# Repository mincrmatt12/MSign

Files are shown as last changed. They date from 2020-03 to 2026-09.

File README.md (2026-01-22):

# MSign

Code + designs for an LED sign display board powered by an STM32 and ESP8266. Make sure you clone the submodules.

## Organization

- `board`: schematics and PCB layout
- `stm`: STM32 firmware (drives the display)
- `stmboot`: STM32 bootloader
- `esp`: ESP8266 firmware (grabs information from the internet)
- `espweb`: ESP8266 web-based configuration page source
- `cfgserver`: Server for shipping unattended config and software updates (without using the webui)
- `bmap`: Tools for generating graphics resources
- `caplog`: Tools for debugging
- `vendor`: Various dependencies in source form (everything not listed below)
- `sim`: Stubs/shims for running the `esp` and `stm` codebases under linux.

## Dependencies

- A recent `arm-none-eabi-gcc` installation (suitably modern to deal with C++20; GCC 14 is what's tested)
- A `xtensa-lx106-elf-gcc` that can deal with C++20; preferably version 13.2.0 (which was available at one point in debian)
  - A suitable newlib/libstdc++ archive is available in `Dockerfile.build`
- Python 3 and the packages in `requirements.txt`
  - If you aren't building the `espweb` directory you do not require the `cryptography` package listed
- OpenOCD (for flashing)
  - If you have PlatformIO installed we use its OpenOCD by default, so you may not need to install it system-wide.
- CMake (version 3.13 or later is recommended)
- `quilt`, to apply the patches in `vendor` for the ESP8266 SDK

and everything checked out in the `vendor` directory. The ESP8266 SDK also usually requests you have python (specifically _system_ python, whatever runs from `python`) installed with it's requirements (`vendor/ESP8266_RTOS_SDK/requirements.txt`)

A Docker file with these is provided as `Dockerfile.build`.

For building the `espweb` you also need:

- yarn
- node 

A Docker file with _these_ is also provided as `Dockerfile.webbuild`

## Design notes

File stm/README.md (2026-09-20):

# STM
The code will run on a nucleo-f207zg or the msign, which uses an stm32f205rgt

## HUB75

### Pinout on nucleo

| Pin | Mapped |
| ----- | --- |
| `R0`  | `PD0`  |
| `G0`  | `PD1`  |
| `B0`  | `PD2`  |
| `R1`  | `PD3`  |
| `G1`  | `PD4`  |
| `B1`  | `PD5`  |
| `A` | `PB0`  |
| `B` | `PB1`  |
| `C` | `PB2`  |
| `D` | `PB3`  |
| `CLK` | `PD6`  |
| `LAT` | `PB5`  |
| `OE`  | `PB6`  |

### Pinout on board

| Pin | Mapped |
| ----- | --- |
| `R0`  | `PC0`  |
| `G0`  | `PC1`  |
| `B0`  | `PC2`  |
| `R1`  | `PC3`  |
| `G1`  | `PC4`  |
| `B1`  | `PC5`  |
| `A` | `PB0`  |
| `B` | `PB1`  |
| `C` | `PB2`  |
| `D` | `PB3`  |
| `CLK` | `PD6`  |
| `LAT` | `PB5`  |
| `OE`  | `PB6`  |

Uses DMA to the GPIO to drive R0-B1 as well as the clock.
DMA is triggered off of TIM1 update event; the delay between different bits of color in PCM encoding goes off of TIM9.

## Serial Protocol

Serial communications run at 115200 baud with even parity, except where specified otherwise.

The protocol starts with a handshake, initiated from the STM32, and continues asynchronously.

The system is mostly based around the sharing and storage of various "slots" of data, which have variable length, which while being capped at 65k by technical restrictions
is limited to around 8k in practice.

### Command format

```
| 0xA6 | 0x00 | 0x11 | <payload> |
  |       |     |
  |       |     ------ command, see below
  |       ---- payload size
  --- direction byte, A6 for packets from the esp, A5 for packets from the STM
```

| Name | Byte |
| ---- | ---- |
| `HANDSHAKE_INIT` | `0x10` |
| `HANDSHAKE_RESP` | `0x11` |
| `HANDSHAKE_OK` | `0x12` |
| `HANDSHAKE_UOK` | `0x13` |
| `HANDSHAKE_CRASH` | `0x14` |
| `DATA_TEMP` | `0x20` |
| `DATA_FULFILL` | `0x21` |
| `DATA_RETRIEVE` | `0x22` |
| `DATA_REQUEST` | `0x23` |
| `DATA_SET_SIZE` | `0x24` |
| `DATA_STORE` | `0x25` |
| `ACK_DATA_TEMP` | `0x30` |
| `ACK_DATA_FULFILL` | `0x31` |
| `ACK_DATA_RETRIEVE` | `0x32` |
| `ACK_DATA_REQUEST` | `0x33` |
| `ACK_DATA_SET_SIZE` | `0x34` |
| `ACK_DATA_STORE` | `0x35` |
| `QUERY_TIME` | `0x40` |
| `RESET` | `0x50` |
| `PING` | `0x51` |
| `PONG` | `0x52` |
| `UPDATE_CMD` | `0x60` |
| `UPDATE_IMG_DATA` | `0x61` |
| `UPDATE_IMG_START` | `0x62` |
| `UPDATE_STATUS` | `0x63` |
| `CONSOLE_MSG` | `0x70` |
| `REFRESH_GRABBER` | `0x80` |
| `SLEEP_ENABLE` | `0x81` |
| `RECONNECT_WIFI` | `0x82` |
| `UI_GET_CALIBRATION` | `0x90` |
| `UI_SAVE_CALIBRATION` | `0x91` |

### Handshake

STM sends command `HANDSHAKE_INIT`, esp responds with `HANDSHAKE_RESP`, STM finishes with `HANDSHAKE_OK`. All handshake commands have payload size 0 and no payload.
The command `HANDSHAKE_UOK` is sent to indicate that the STM should enter update mode. The command `HANDSHAKE_CRASH` is sent from the ESP in place of `HANDSHAKE_RESP` or
`HANDSHAKE_UOK` if there is a pending crash report -- this status is cleared after a reset and the STM should not boot if it gets it.

### Slots

Each slot is represented as a theoretically unbounded, randomly-accessible and partitionable chunk of memory.

Each part of the slot's data can be stored on either the ESP or the STM when not in use. Data stored on a processor in this way is called _canonical_ data. The other processor refers
to this data as _remote_ data, using a placeholder to avoid duplicating it. Remote data may temporarily be converted to _ephemeral_ data, which is a temporary copy of _canonical_ data, almost
always by the STM for use on-screen.

An entire slot has a _temperature_, which relates to where a version of it should be made available:

| Temperature | Meaning |
| --- | --- |
| Cold | Not required for the display right now |
| Warm | Will be required soon for the display, should be sent. |
| Hot | Is being displayed right now. |

There is also a special temperature which is never transmitted, but which the ESP uses internally to represent data that should be Warm but has no space to fit on the STM.

Any updates to data that is at least level Warm should be immediately transferred to the STM, so long as there
is space for it. Additionally, if any part of the slot's data is stored _canonically_ on the STM and the slot
is made Warm or higher, all the remaining parts of the data still stored on the ESP should be flushed to the STM and marked remote, again, memory permitting.

The STM controls the temperature of data using the `DATA_TEMP` (data temperature) message:

```
| 0x090a | 0x01 |
  |        |
  |        ---- the temperature to update to, one of the Block::Temperature* constants
  ----- the slot ID to update (12 bits, stored as 16 bit with upper nybble 0)
```

The STM shall send this message whenever it wishes to change the temperature of a slot, and should send it repeatedly until it receives an identical message of type `ACK_DATA_TEMP` confirming the change
(although it's allowed to stop sending if it wants to). The ESP can also respond with the fake temperature "0xff" which indicates a non-acknowledgement, usually because it thinks there isn't 
enough space (or for if there's no data for that slot)

The ESP can also send a `DATA_TEMP` message to set a slot back to Cold should it determine there is not enough space for it to be updated immediately. The STM may challenge this declaration
by trying to change the slot back to Warm, but will probably get a nak. The ESP may decide to re-instate the Warm temperature for a slot later, but only if the STM has not otherwise changed
the temperature since.

#### Updating

The ESP uses the `DATA_FULFILL` message to signal that the STM should create an ephemeral part of the data at some offset and length.

```
| 0x090a | 0x0100 | 0x0500 | <data> |
  |        |        |        
  |        |        |        
  |        |        ---- total length of update
  |        --- offset to update at
  --- slot ID + framing info:

  0b0000  0x90a
    ||||    |
    ||\\    slot ID
    ||-- reserved
    |- end
    - start
```

The "fulfilling" of the data is in response to a "request", either implicitly from the temperature setting or explicitly from a "DATA_REQUEST" message.

#### Framing

This message (as well as `DATA_STORE`) is framed to allow for sending more than 249 bytes: the `start` bit is set for the first message corresponding to this update, the `end` bit is set for the last message, and the offset is always
the offset of this message.

This is enough to both know the size and starting offset of an update immediately, progressively update, and again know the size and starting offset of the entire update as well.

#### Acknowledgements

This message (as well as `DATA_STORE`) send a single acknowledgement to indicate successful/unsuccessful completion of the update as a whole. Note that an acknowledgement is not required if an `end` packet
is not sent.

This acknowledgement takes the form

```
| 0x090a | 0x0100 | 0x0120 | 0 |
  |           |      |       |
  |           |      |       -- result code
  |           |      -- length of update
  -- slot ID  -- start of update
```

The result code is one of these:

| Code | Usage |
| ---- | ----- |
| `0x00` | Completed OK |
| `0x01` | Not enough space to store -- try again soon to allow for potential cleanup |
| `0x02` | Not enough space to store -- cleanup failed, definitely no space |
| `0x10` | Illegal internal state |
| `0x11` | Parameters don't make sense / other NAK |
| `0xff` | Internal timeout somewhere |

#### Moving 

The ESP is allowed to store data canonically on the STM should it want, and it does this with the `DATA_STORE` message.
It has the same format and acknowledgement scheme as `DATA_FULFILL`, but semantically means to create a canonical part not an ephemeral one.

### Unmoving

If the ESP decides it no longer wants data canonically on the STM, it can send the `DATA_RETRIEVE` message. 

```
| 0x090a | 0x0100 | 0x0120 |
  |           |     |
  |           |     -- region size
  -- slot ID  -- region start 
```

If the data is present on the STM, it sends an acknowledgement that is identical. If the data is not present, a similar process to an invalid `DATA_CHANGE_SIZE` is used.
Once the acknowledgement is sent, the STM sends its own `DATA_STORE` message sequence, and the ESP responds accordingly. 

#### Size update

The ESP sends `DATA_CHANGE_SIZE` whenever the total size of a slot changes. The STM should handle new empty space as remote placeholders.

```
| 0x090a | 0x0aaa |
   |           |
   |           |
   -- slot ID  -- new slot size
```

This is acknowledged with a copy of the message, and it is illegal to not have this complete succesfully. If there isn't enough space to store
the placeholder, not responding is valid and the ESP will handle the timeout in some vaguely graceful manner.

#### Forgetting/requesting

The STM can request an explicit `DATA_FULFILL` from the ESP by sending a `DATA_REQUEST` message. The syntax for this message is:

```
| 0x090a | 0x000c | 0x0120 |
  |           |     |
  |           |     -- region size
  -- slot ID  -- region start
```

An identically-formatted message is sent as acknowledgement.

### Consoles

A console is a unidirectional stream of characters. There are three consoles on the MSign:

| ID | Usage |
| --- | ---|
| `0x01` | The debug console input; as accessed through the web interface for commands starting with `"stm"` |
| `0x02` | The debug console output; relayed back to the web interface, hooked to `stderr` |
| `0x10` | `printf` output; logs, hooked to `stdout` |

The protocol uses one message for these:

```
| 0x01 | <data> |
  |      |
  |		 - character data for the remainder of the message
  -------- the console ID
```

It can be sent from either device.

### Time sync

When the STM sends a `QUERY_TIME` message, the ESP should respond with the current time. The payload of the request is empty and the response is

```
| 0x00 | <time> |
  |      |
  |      ---- JS-style millisecond-referenced unix timestamp
  ---- status code
```

The time should be as close to as possible the time when the last byte of the header of the request was sent.
The status code can be one of

| Code | Meaning |
| ---- | --- |
| `0x00` | OK |
| `0x01` | Time is still being retrieved, try again in a bit |

### Refresh

The STM can ask the ESP to refresh data from a certain grabber (see the esp source) by sending the `REFRESH_GRABBER` with a single byte payload indicating which ID to refresh.

### Sleep mode

The MSign has a sort of pseudo sleep mode which can by enabled or disabled by either devices by sending the `SLEEP_ENABLE` message with a singly byte payload indicating whether
or not to enable/disable (`00` being disabled, anything else being enabled)

When in sleep mode, the following things occur:

- all log output is prevented from reaching the serial port (to avoid blinking the led)
- the screen is turned off
- update frequency is made much slower

### Reconnect

The STM can ask the ESP to reset its WiFi connection (e.g. to refresh DHCP leases after a router reboot) by sending a `RECONNECT_WIFI` message with no payload.

### ADC calibration

The ESP persists to the SD card the current calibration in a file. The calibration can be updated either manually on the SD card or by an interactive process on the STM whose results
are also persisted to the SD card.

The STM can request the current calibration with an empty `UI_GET_CALIBRATION` message. In response, the ESP sends a `UI_GET_CALIBRATION` of its own, formatted as

```
| 0x00 | 0x0000 | 0x0000 | 0x0000 | 0x0000 | 0x0000 | 0x0000 |
  |      |                                                 |
  |      ---------- calibration data as 6 16-bit words ----|
  --- response code                                        
```

with the calibration data missing if the error code is not `0`. The error code can be one of:

| Code | Meaning |
| ---- | --- |
| `0x00` | OK |
| `0x10` | No calibration data present |
| `0x11` | No calibration data present and auto-configuration is disabled (i.e. ignore joystick) |

The calibration data is made up of the following three values repeated twice, once for the x-axis and once for the y-axis:

- minimum reading
- maximum reading
- deadzone width (total delta from (max + min)/2 allowed)

The STM can upload new calibration using the `UI_SAVE_CALIBRATION` command, with a payload consisting of just the calibration data portion of the `UI_GET_CALIBRATION` response. Once the data is
written to the SD card, the ESP responds with an empty `UI_SAVE_CALIBRATION` message.

### Other commands

When either device sends the `RESET` command, both devices should reset. Usually sent by the ESP upon grabbing new configuration -- but the STM can also send it in rare cases.

When either device sends the `PING` command, the other MUST respond with the `PONG` command, UNLESS the handshake has not been completed.

The above three commands have no payload.

### Update commands

The update procedure is rather complicated due to the requirement to update two things.
The first step is the ESP receiving an update package. While it is downloading the package, it updates various status slots to inform. Once it has finished, it will send a `RESET` command to reset the device.
When the system reboots, the ESP shall respond with `HANDSHAKE_UOK` on successful handshaking. Once this occurs, the STM enter update mode. When this occurs, the baudrate is doubled until
the terminating `RESET`.

Once the update finishes for the STM, it must send an appropriate `UPDATE_STATUS` to the ESP. Once this occurs,
the ESP will update itself. When it finishes, the STM will hear a `UPDATE_CMD` to reset itself to normal mode. At this point, the system is updated.

#### Detailed flow

After the `RESET`, the ESP will send various `UPDATE_CMD`s, and then the image.

The `UPDATE_CMD` message looks like this:

```
| 0xFF |
 |
 ---- cmd ID
```

where `cmd ID` is:

| ID | Meaning |
| :--- | :--- |
| `0x10` | Cancel update mode / reset to normal mode |
| `0x11` | Prepare to recieve image
| `0x30` | Image read error |
| `0x31` | Image checksum error |
| `0x32` | Invalid state error |
| `0x40` | Update completed successfully |
| `0x50` | ESP wrote sector (see below) |
| `0x51` | ESP copying sector (see below) |

Once message `0x11` is sent, the STM should get ready to recieve the `UPDATE_IMG_START`. This message contains:

The STM can respond with `UPDATE_STATUS` messages, with the same format.

| ID | Meaning |
| :--- | --- |
| `0x10` | Entered update mode |
| `0x12` | Ready for image |
| `0x13` | Ready for chunk |
| `0x20` | Beginning copy process |
| `0x21` | Copy process completed |
| `0x30` | Resend last chunk, csum error |
| `0x40` | Checksum error on entire thing, abort procedure |
| `0x41` | Unexpected protocol error, abort |

Note there are no errors for copy process as if it fails the code won't run. If the ESP doesn't get anything for a few minutes it can report failure and ask for manual reflashing.

```
| 0xCC CC | 0xSS SS SS SS | 0xCNCN |
  |          |               |
  |          |               ------ chunk count, little endian 16bits
  |          ---- size of new image, bytes, little endian 32bits
  ---- checksum, little endian 16bits, CRC16
```

Then, the STM can send `UPDATE_STATUS` commands to get the chunks.

Once it sends the `0x13` message, the ESP responds with a chunk like this:

```
| 0xCC 0xCC | <data for rest of message>
  |            |
  |            -- chunk data (size = msgsize - 2) extra bytes are padded with zeros
  ---- CRC-16 checksum for this chunk
```

After each chunk, the STM can respond with an error or a new message.
If the stm deduces it has received all chunks, it sends the finished message and updates itself.
After completion of this process, it sends the status corresponding to update completed.
The ESP will then begin writing the image to itself in preparation for copying, and will send out "ESP wrote sector" messages
as it does so.
The STM then waits for the ESP to send a cmd corresponding to completed.
It then resets.

## Serial

### Pinout on nucleo

USART6.

| Pin  | Mapped |
| ---- | --- |
| `TX` | `PG14`  |
| `RX` | `PG9`  |

### Pinout on board

USART2.

| Pin  | Mapped |
| ---- | --- |
| `TX` | `PA2`  |
| `RX` | `PA3`  |

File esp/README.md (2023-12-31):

# ESP8266

## Pinouts

Debug tx is mapped to `GPIO2`.

TX/RX are on `GPIO13`/`GPIO15`.

SD is wired

| PIN | Mapped |
| --- | --- |
| `MISO` | `GPIO12` |
| `MOSI` | `GPIO4` |
| `SCK` | `GPIO14` |
| `CS`  | `GPIO5` |

(configurable via menuconfig)

## SD Card

The SD card contains the following files:

```
|
+- config.json
+- ca
| |
| -- <sha512 dn hash>
| -- <sha512 dn hash>
+-?model.bin
+-?model1.bin
+-?adc.bin
+- cache
|  |
|  +- ... various directories
+- web
| |
| +- page.html
| +- page.js
| +- page.css
| +- vendor.js
| +-?page.html.gz
| +-?page.js.gz
| +-?page.css.gz
| +-?vendor.js.gz
| +-?etag
--*upd
  |
  +- state
  +- esp.bin
  +- stm.bin
  +- webui.ar
  +- certs.bin
  +- chck.sum
```

Files marked with a `?` are optional, and will either be generated by the system or are not required.

Files marked with a `*` are only present during an update.

Files marked with a `!` are internal only.

### Simple files

- `config.json` contains the configuration for the sign. A reference of keys/values can be found in the various `.cfg.h` files within the main source tree.
- `model.bin` and `model1.bin` are optional 3D models, the default is a baked in M^2 text. The format is simply a 32bit integer of the number of triangles followed by tightly packed floats for each triangle (`xyz*3, rgb`)
- `adc.bin` contains the current calibration for the joystick. If not calibrated, the joystick is ignored (and a warning is shown unless
disabled in the config).

### Web files

The `html` file is served whenever a request is made that _doesn't_ contain a valid API URI.
The other files are served whenever a request matching their name (optionally containing a cache-busting
hash, in which case cache headers are set to cache indefinitely). 
The `etag` file is generated automatically to help with caching and should be deleted after changing the web assets.

### Update files

The files in the `upd` folder relate to the ongoing system update. In general, these should not be touched. To update the webui / certificate bundle it's easier
to manipulate their folders directly; to install new firmware from the SD card see the utilities in the `espweb/` folder.

The `bin` files contain the entire firmware image for the two systems, stored as flat binary files.

State is a single byte indicating the update state. `chck.sum` contains two 16 bit checksums for the
firmware files.

The `webui.ar` file is a normal `.ar` archive containing the new website files. It is written by the webui itself
for an over-the-air update -- updating the files manually in `web/` and deleting `web/etag` is usually faster for a manual
update.

The `certs.bin` file is a custom archive type containing a new block of certificates to install from an over-the-air update. Old certificates
are not removed -- to revoke a certificate the folder must be manually cleaned up.

## TLS files

All the files in the `ca` directory are trusted certificates. The filename is the
subject DN encoded in X.500 form and hashed with SHA512 (stored as hex) and is just
the DER-encoded X.509 certificate.

## Cache files

Files in the `cache` directory are used internally by various grabbers (in general, each grabber
automatically manages its own subfolder). The folder can be safely deleted.

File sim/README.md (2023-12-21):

# sim

Simulates the entire sign, using mostly the same codebase.

## Building

Requirements:

- A recent version of CMake

## Running

The system communicates with named pipes for emulating the UART.

Create two with

```
$ mkfifo stoe
$ mkfifo etos
```

then point the new `stmsim` and `espsim` binaries at them:

```
$ # terminal 1
$ ./stmsim <etos 2>stoe

----

$ # terminal 2
$ ./espsim <stoe >etos
```

You can also use more magic if you want to record the messages, possibly to be looked at with `caplog`, or combined with the logging utilities below:

```
$ # terminal 1
$ ./stmsim <etos 2>stoe 2> >(logtime.py stoelog.txt)

----

$ # terminal 2
$ ./espsim <stoe >etos > >(logtime.py etoslog.txt)
```

(`>(something)` becomes a file descriptor, `> >(something)` redirects that normally)

Alternatively, make two more named pipes and pass them into `caplog`'s `realtime` mode.

You also need to setup a TAP interface to get the ESP network working.

```
# add a bridge that our machine is on: this will forward packets
# to/from the virtual esp
# if you have a vm system setup with a virbr0 interface, you can skip all the way to the tap0 setup and just use it instead

$ sudo ip link add br0 type bridge
$ sudo ip addr add <some ip unused, e.g. 192.168.122.1/24> dev br0
$ sudo ip link set br0 up

# setup nat

$ echo 1 > /proc/sys/net/ipv4/ip_forward
$ sudo iptables -t nat -A POSTROUTING -o <your wifi/ethernet port> -j MASQUERADE
$ sudo iptables -A FORWARD -i br0 -j ACCEPT
$ sudo iptables -A FORWARD -o br0 -d <your subnet, e.g 192.168.122.0/24> -m conntrack --ctstate RELATED,ESTABLISHED -j ACCEPT
$ sudo ip route add <subnet for the bridge, e.g. 192.168.122.0/24> dev br0 proto kernel scope link src <ip of bridge, e.g. 192.168.122.1>

# setup the tap

$ sudo ip tuntap add dev tap0 mode tap user `whoami`
$ sudo ip link set tap0 master br0
$ sudo ip link set address 02:12:34:56:78:ab dev tap0
$ sudo ip link set tap0 up

# set config for espsim

$ export PRECONFIGURED_TAPIF=tap0
$ export SIMESP_IP <some ip on the subnet of the bridge, e.g 192.168.122.2>
$ export SIMESP_NETMASK <netmask of the bridge, e.g. 255.255.255.0>
$ export SIMESP_GATEWAY <ip of the bridge, e.g. 192.168.122.1>
```

The esp sim gets its SD card contents from the file `sdcard.bin` in the working directory, which should be a raw image of an SD card. You can create one with `fdisk` and `mkfs.vfat` and modify it
by loop mounting it; or by grabbing an actual SD card in use and taking a `dd`-style image of it.

## Structure

The `src` folder contains files to be mixed with the actual sources, any files here have precedence over those elsewhere, allowing for "overriding" of the original sources with mocked-up versions.
The two binaries communicate over standard file streams.

`espsim` sends data to `stmsim` over `stdout` and receives over `stdin`, sending debug data to `stderr`. To allow for terminal coloring, `stmsim` sends over `stderr`, but still receives on `stdin`.

The only file the fake ESP currently reads is the `config.txt`, placed in the working directory and with exactly identical contents to what it would be on the real sign.

## Logging

There are two programs provided here, `logtime.py` and `mergelog.py`, which create a logfile with extra bytes for the time and merge two of those logs into a normal log respectively.

## Extras

The `utils/` folder contains a few utilities which are compiled along with the simulator, which can be used for experimenting with some of the libraries available on both systems.

### `jdump`

`jdump` reads JSON from standard input and outputs a trace of how the `json::JSONParser` class will interpret it.

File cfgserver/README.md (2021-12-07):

# cfgserver

Implements a Vaguely Secure™ protocol for sending configuration over the network.

It exposes a set of HTTPS endpoints which implement a simple authentication scheme and update delivery mechanism.

It also now supports telemetry logging; the ESP can optionally include a header with prometheus-style key/value pairs, which
are exposed at `/a/metrics`.

## Authentication

To authenticate, the ESP must form a valid bearer token. The first step to generating a token is to obtain a _challenge_ from the server, by
performing `GET /challenge`. This will return a blob of text, which is opaque to the ESP (but on the server is a signed message containing
some random nonce and a timestamp). The ESP then signs this message with a shared HMAC key and appends the result (in hex) to the blob. This final string
is used as a bearer token.

For example:

```
GET /challenge HTTP/1.1
...

fahdvu234hauc.fjah3
```

```
GET /whatever HTTP/1.1
Authorization: Bearer fahdvu234hauc.fjah3;22be1f7c
```

Separately, the server stores an administrator user/password/2fa token which can be sent to `POST /login` as

```
{
   "user": "username",
   "password": "password",
   "token": "232148"
}
```

which will set a session cookie that will substitute for valid authentication (this is so that the normal webui can be hosted at the root of the server)

Thirdly, the server can be asked to generate static bearer tokens for use in CI.

These all have different privilege levels:

- The ESP is allowed to download but not change config
- Static tokens are allowed to change but not read config
- The administrator is allowed to do both.

## Update checking

There are two things `cfgserver` can send to the ESP, config updates or system updates. Both of these have an associated "version" identifier. For configuration, the
version is an arbitrary integer. Although it is an integer, a "newer" version does not need to have a larger version, rather the system only checks for a different version.

The version for system upgrades is the version ESP-IDF places into the firmware, which is obtained with `git describe --tags --always --dirty`.

The current version being served can be read from `/version` without authentication:

```
GET /version HTTP/1.1
...

HTTP/1.1 200 OK

{"firm": "v3.1-579-gffe802", "cfg": 4152}
```

If a value is not present, the corresponding file has not been uploaded.

## Downloading updates

The current config can be downloaded from `/conf.json` with valid authentication.

The current firmware is downloadable from `/stm.bin` and `/esp.bin`, again with valid authentication. 

## Uploading updates

Config can be pushed by `POST`-ing to `/conf.json` and firmware can be sent by `POST`-ing to `/updatefirm` with form-encoded files `stm.bin` and `esp.bin`.

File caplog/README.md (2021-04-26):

# `caplog`

Various tools to dissect capture logs of the communication between the STM and ESP.

## `dissect`

Takes in either a CSV from the Saleae software or a raw `bin` file containing a dump of all bytes transferred, and converts them to a visually
interpretable format.

`caplog/dissect.py [logicexport,simlog] <path to in file>`
(you can also use any prefix of the first argument)

## `regiondump.py`

GDB script that adds a command `dump_bheap` which takes an expression to a raw `bheap::Arena`'s region and a filename and writes out
a summary of all the blocks in the heap.

```
(gdb) source caplog/regiondump.py
(gdb) dump_bheap servicer.arena.region dump_file.txt
```

This also adds another command, `dump_raw_bheap` which outputs a json file (or appends to an existing json file) with an easier
to parse representation of the heap, suitable for visualization with `dumpviewer.html`.

## `dumpviewer.html`

Tiny single page web thing that can read a heap trace and visualize it.

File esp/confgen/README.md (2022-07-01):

# confgen
 
`confgen` is the system we use to generate the config.cpp parser. It essentially generates implementations for header files ending with `.cfg.h` based
on control comments.

There are a couple of ways that `confgen` can be instructed to provide data to you:

- directly, in a ram variable (`holds`)
- indirectly, through a function that receives config (`receives`)
- lazily, by generating a function that reads the data (`loads`)

## Comment syntax

All `confgen` comments start

```
//!cfg: <something>
```

The first word of a confgen is the desired type, either `holds`, `receives`, or `loads`. The next block, after a space, is the _path specification_, similar in
style to `jq`.

Specifically, the path syntax is

```ebnf

path: ("." atom)+

atom: CNAME -> path_element
	| CNAME "[" array_index "]" -> named_array_element
	| "[" array_index "]" -> anon_array_element
	| variable -> wildcard_element
	| CNAME "!size" -> special_size_element

variable: "$" CNAME

?array_index: INT
		   | variable

```

For example:

```
.ssid  ->  { "ssid": <something> }

.weather.apikey -> {"weather": {"apikey": <something>}}

.ttc.entries[0].name -> {"ttc": {"entries": [{"name": 0}]}}

.ttc.entries[$n].$var -> all subentries (passed to function as a size_t and const char *)

.ttc.entries!size -> length of entries array
```

Variables have three uses:
- For arrays, to denote which axes of the target variable correspond to axes of json arrays. These use names `$i - $k`, and if omitted will be assumed to refer to the
  last element of the path
- For `receives`, to specify wildcards which correspond to function arguments (by name).
- For `loads`, to specify dynamic matches. They are the exact inverse of the behaviour for `receives`; calling a generated loader with some arguments
will load the value that a similar receiver would get for those same arguments.

`holds` annotates a variable and specifies that the config data at the given path should be placed in it. The variable should be declared
`extern`, as the config generator will create the actual storage.

`receives` annotates a function that will be called with config data (and possible values of variables). The values are passed to whichever parameter
is named `value` -- it does not need to be in any specific location.

`loads` annotates a function that will have its implementation generated such that it loads some entry from the config, as denoted by the path. Its arguments
can be used as variables in said path to choose different things to load at runtime.

### Additional tags

Other things can be added as comma separated tags after the main declaration, such as explicit datatypes or defaults.

```
, default <some value>
, max $i = 0
, result $hi
```

- `default` sets a default for a value. Defaults are only allowed for loaders/global variables and should only be basic constants (not a complex expression). Arrays
can be initialized by space separating the desired values. The `$i - $k` variables can be used to refer to array indices.
- `max` sets a maximum for a given variable in wildcard/array filling mode. By default, it's inferred from the dimensions of the targeted variable,
but for `receives` this is impossible and so can be assigned manually
- `result` specifies a named argument to a loader which should be a `bool&` and which is set to true/false depending on if the load succeeded.

### Annotating types

Structure members can be annotated, in which case the entire structure becomes eligible for being used as a target variable. Note that currently you cannot have a function
receive an entire object (although a loader _can_ generate one). Structure function members can also be used as receive targets.

The paths used are relative to wherever the structure is used, for example

```c++
struct Thing {
   //!cfg: .a
   int a = 4;
   //!cfg: .bs
   int bs[3]{};
}

//!cfg: .some.path
extern Thing thingy;
```

which will load from `.some.path.a` and `.some.path.bs[0-2]`.

Structures are default-constructed, however you can also provide explicit defaults for fields too. These will currently _not_ be applied
in loaders, though.

Types are only searched for annotations in `.cfg.h` files, not anything included from one. To search an additional file, use the `//!cfg: include <file>` notation
which works relative to the current file (like a quoted `#include`).

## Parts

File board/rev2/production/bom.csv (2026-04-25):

Designator | Footprint | Quantity | Value | LCSC Part #
C1, C12, C15, C21, C24, C25, C3, C34, C35, C38, C44, C45, C46, C47, C48, C49, C5, C50, C51, C52, C53, C54, C55, C56, C57, C58, C59, C60, C61, C62, C63, C64, C65, C66, C71 | 0402 | 35 | 100nF | C307331
C10, C16, C2, C37, C72 | 1206 | 5 | 10uF | C13585
C11, C23, C68, C74 | 0603 | 4 | 1uF | C15849
C13 | 0603 | 1 | 2.2nF | C1604
C14 | 0603 | 1 | 8.2nF | C1322360
C17 | CP_Radial_D8.0mm_P3.50mm | 1 | 220uF | C106697
C18 | CP_Radial_D8.0mm_P3.50mm | 1 | 150uF | C106696
C19, C20, C22, C36, C39, C43 | 1206 | 6 | 4.7uF | C29823
C26, C27, C28, C29, C30, C31, C32, C33, C7, C73, C8, C9 | 1206 | 12 | 47uF | C96123
C4 | 0603 | 1 | 33nF | C21117
C40, C42 | 0402 | 2 | 15pF | C1548
C41, C67 | 0603 | 2 | 2.2uF | C23630
C6 | 0402 | 1 | 10pF | C32949
C69, C70 | 0603 | 2 | 330pF | C1664
JCONT1 | PinHeader_1x09_P2.54mm_Horizontal | 1 | Conn_01x09_Pin
JDBG1, JDBG2 | PinHeader_1x03_P2.54mm_Vertical | 2 | Conn_01x03
JLED1, JLED2 | IDC-Header_2x08_P2.54mm_Vertical | 2 | Conn_02x08_Counter_Clockwise
JPWR1 | CONN-TH_4P-P9.50_WJHB9500M-9.5-04P-13-00A | 1 | Screw_Terminal_01x02 | C255007
JSD1 | microSD_XUNPU_TF-115-BCP9 | 1 | Micro_SD_Card_Det1 | C720505
JUSB1, JUSB2 | USB_C_Receptacle_HRO_TYPE-C-31-M-12 | 2 | USB_C_Receptacle_USB2.0_14P | C165948
L1 | L_Chilisin_BMRF00101040 | 1 | 6.8uH | C7502775
L2 | L_Cenker_CKST1707 | 1 | 1uH | C5292052
Q1 | DFN-8_L4.9-W6.0-P1.27-LS6.1-BL | 1 | WSD40120DN56G | C507088
R1 | 0603 | 1 | 49.9k | C23184
R10 | 0603 | 1 | 2.2 | C22939
R12, R13, R18, R19 | 0402 | 4 | 22 | C25092
R14 | 0402 | 1 | 10 | C25077
R15, R17, R24, R25, R26, R27, R28, R29, R30, R32, R33, R34, R35, R36, R37, R38, R52 | 0402 | 17 | 1k | C11702
R16, R22, R23, R49, R50, R51 | 0402 | 6 | 33 | C25105
R2, R20, R21, R3, R8 | 0402 | 5 | 10k | C25744
R4 | 1206 | 1 | 100 | C17901
R40, R41, R42, R43, R47 | 0805 | 5 | 10k | C17414
R44, R45 | 0603 | 2 | 5.1k | C23186
R46 | 0603 | 1 | 20k | C4184
R48 | 0402 | 1 | 200 | C25087
R5 | 0805 | 1 | 1.2k | C17379
R6 | 0805 | 1 | 470k | C17709
R7 | 0805 | 1 | 150k | C17470
R9 | 0402 | 1 | 3.3k | C25890
SW1, SW2, SW3, SW5 | SW-SMD_MS-22D17AG2.5 | 4 | MS-22D28-G020 | C20611671
SW4 | SW_SPST_TS-1088-xR020 | 1 | TS-1088-AR02016 | C720477
TP1, TP2, TP3, TP4, TP5, TP6, TP7 | TestPoint_Pad_D1.0mm | 7 | TestPoint
U1 | WQFN-20-1EP_3x3mm_P0.4mm_EP1.7x1.7mm_ThermalVias | 1 | TPD6S300A | C2876380
U10 | TSSOP-16_4.4x5mm_P0.65mm | 1 | 74VHC161 | C7421276
U11, U13 | TSOP-28_L11.8-W8.0-P0.55-LS13.4-L | 2 | IS61LV256AL | C412837
U12, U14 | TSSOP-16_4.4x5mm_P0.65mm | 2 | 74AHCT595 | C460504
U15, U16 | TSSOP-20_4.4x6.5mm_P0.65mm | 2 | 74HCT245 | C5980
U17, U18 | UQFN-10_1.4x1.8mm_P0.4mm | 2 | TS3USB30ERSWR | C73880
U19 | SOT-223-3_TabPin2 | 1 | LD1117AG-33-AA3-A-R | C71121
U2 | SOT-583-8 | 1 | TPS62933 | C3200405
U3 | VQFN-10_L2.0-W2.0-P0.45-TL | 1 | TPS259472A | C3662789
U4 | TSOT-23-6 | 1 | LM5050-1 | C473393
U5 | POWERPAK_MLP34-57_VIS | 1 | SiC451 | C1852144
U6 | QFN-48-1EP_7x7mm_P0.5mm_EP5.6x5.6mm | 1 | STM32G071CBUx | C529343
U7 | ESP32-C6-WROOM-1 | 1 | ESP32-C6-WROOM-1 | C5366877
U8 | SOT-23-5 | 1 | TLV74311 | C485147
U9 | RP2350-QFN-80-1EP_10x10_P0.4mm_EP3.4x3.4mm_ThermalVias | 1 | RP2354B | C39843328
Y1 | Crystal_SMD_3225-4Pin_3.2x2.5mm | 1 | ABM8-272-T3 | C20625731

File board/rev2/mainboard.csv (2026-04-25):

Id | Designator | Footprint | Quantity | Designation | Supplier and ref
1 | C1, C3, C5, C12, C15, C21, C24, C25, C34, C35, C38, C44, C45, C46, C47, C48, C49, C50, C51, C52, C53, C54, C55, C56, C57, C58, C59, C60, C61, C62, C63, C64, C65, C66, C71 | C_0402_1005Metric | 35 | 100nF
2 | C2, C10, C16, C37, C72 | C_1210_3225Metric | 5 | 10uF
3 | C4 | C_0603_1608Metric | 1 | 33nF
4 | C6 | C_0402_1005Metric | 1 | 10pF
5 | C7, C8, C9, C26, C27, C28, C29, C30, C31, C32, C33, C73 | C_1206_3216Metric | 12 | 47uF
6 | C11, C23, C68, C74 | C_0603_1608Metric | 4 | 1uF
7 | C13 | C_0603_1608Metric | 1 | 2.2nF
8 | C14 | C_0603_1608Metric | 1 | 8.2nF
9 | C17 | CP_Radial_D8.0mm_P3.50mm | 1 | 220uF
10 | C18 | CP_Radial_D8.0mm_P3.50mm | 1 | 150uF
11 | C19, C20, C22, C36, C39, C43 | C_1206_3216Metric | 6 | 4.7uF
12 | C40, C42 | C_0402_1005Metric | 2 | 15pF
13 | C41, C67 | C_0603_1608Metric | 2 | 2.2uF
14 | C69, C70 | C_0603_1608Metric | 2 | 330pF
15 | JCONT1 | PinHeader_1x09_P2.54mm_Horizontal | 1 | Conn_01x09_Pin
16 | JDBG1, JDBG2 | PinHeader_1x03_P2.54mm_Vertical | 2 | Conn_01x03
17 | JLED1, JLED2 | IDC-Header_2x08_P2.54mm_Vertical | 2 | Conn_02x08_Counter_Clockwise
18 | JPWR1 | CONN-TH_4P-P9.50_WJHB9500M-9.5-04P-13-00A | 1 | Screw_Terminal_01x02
19 | JSD1 | microSD_XUNPU_TF-115-BCP9 | 1 | Micro_SD_Card_Det1
20 | JUSB1, JUSB2 | USB_C_Receptacle_HRO_TYPE-C-31-M-12 | 2 | USB_C_Receptacle_USB2.0_14P
21 | L1 | L_Chilisin_BMRF00101040 | 1 | 6.8uH
22 | L2 | L_Cenker_CKST1707 | 1 | 1uH
23 | Q1 | DFN-8_L4.9-W6.0-P1.27-LS6.1-BL | 1 | WSD40120DN56G
24 | R1 | R_0603_1608Metric | 1 | 49.9k
25 | R2, R3, R8, R20, R21 | R_0402_1005Metric | 5 | 10k
26 | R4 | R_1206_3216Metric | 1 | 100
27 | R5 | R_0805_2012Metric | 1 | 1.2k
28 | R6 | R_0805_2012Metric | 1 | 470k
29 | R7 | R_0805_2012Metric | 1 | 150k
30 | R9 | R_0402_1005Metric | 1 | 3.3k
31 | R10 | R_0603_1608Metric | 1 | 2.2
32 | R12, R13, R18, R19 | R_0402_1005Metric | 4 | 22
33 | R14 | R_0402_1005Metric | 1 | 10
34 | R15, R17, R24, R25, R26, R27, R28, R29, R30, R32, R33, R34, R35, R36, R37, R38, R52 | R_0402_1005Metric | 17 | 1k
35 | R16, R22, R23, R49, R50, R51 | R_0402_1005Metric | 6 | 33
36 | R40, R41, R42, R43, R47 | R_0805_2012Metric | 5 | 10k
37 | R44, R45 | R_0603_1608Metric | 2 | 5.1k
38 | R46 | R_0603_1608Metric | 1 | 20k
39 | R48 | R_0402_1005Metric | 1 | 200
40 | SW1, SW2, SW3, SW5 | SW-SMD_MS-22D28-G020 | 4 | MS-22D28-G020
41 | SW4 | SW_SPST_TS-1088-xR020 | 1 | TS-1088-AR02016
42 | U1 | WQFN-20-1EP_3x3mm_P0.4mm_EP1.7x1.7mm_ThermalVias | 1 | TPD6S300A
43 | U2 | SOT-583-8 | 1 | TPS62933
44 | U3 | VQFN-10_L2.0-W2.0-P0.45-TL | 1 | TPS259472A
45 | U4 | TSOT-23-6 | 1 | LM5050-1
46 | U5 | POWERPAK_MLP34-57_VIS | 1 | SiC451
47 | U6 | QFN-48-1EP_7x7mm_P0.5mm_EP5.6x5.6mm | 1 | STM32G071CBUx
48 | U7 | ESP32-C6-WROOM-1 | 1 | ESP32-C6-WROOM-1
49 | U8 | SOT-23-5 | 1 | TLV74311
50 | U9 | RP2350-QFN-80-1EP_10x10_P0.4mm_EP3.4x3.4mm_ThermalVias | 1 | RP2354B
51 | U10 | TSSOP-16_4.4x5mm_P0.65mm | 1 | 74VHC161
52 | U11, U13 | TSOP-28_L11.8-W8.0-P0.55-LS13.4-L | 2 | IS61LV256AL
53 | U12, U14 | TSSOP-16_4.4x5mm_P0.65mm | 2 | 74AHCT595
54 | U15, U16 | TSSOP-20_4.4x6.5mm_P0.65mm | 2 | 74HCT245
55 | U17, U18 | UQFN-10_1.4x1.8mm_P0.4mm | 2 | TS3USB30ERSWR
56 | U19 | SOT-223-3_TabPin2 | 1 | LD1117AG-33-AA3-A-R
57 | Y1 | Crystal_SMD_3225-4Pin_3.2x2.5mm | 1 | ABM8-272-T3

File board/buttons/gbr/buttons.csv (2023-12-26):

Value | Reference(s) | Footprint | LCSC Part
47nF | C1, C2 | Capacitor_SMD:C_0603_1608Metric | C1622
12k | R1, R2, R3, R4 | Resistor_SMD:R_0402_1005Metric | C25752

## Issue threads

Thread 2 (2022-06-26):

ESP config memory leak

mincrmatt12, 2022-06-26:
Due to an oversight in the config parser generator, string members inside of objects are not freed when reloading the configuration. This causes memory leaks when new configurations are downloaded from the webui/cfgserver.

Current solution will be to replace all global unmanaged `char *` with a destructable `config::string_t`. This should also let the sim store default/non-default tracking flags without imposing memory penalties on the actual device to emulate the current behaviour of checking which region of memory the pointer is in.

Closed 2022-07-01.

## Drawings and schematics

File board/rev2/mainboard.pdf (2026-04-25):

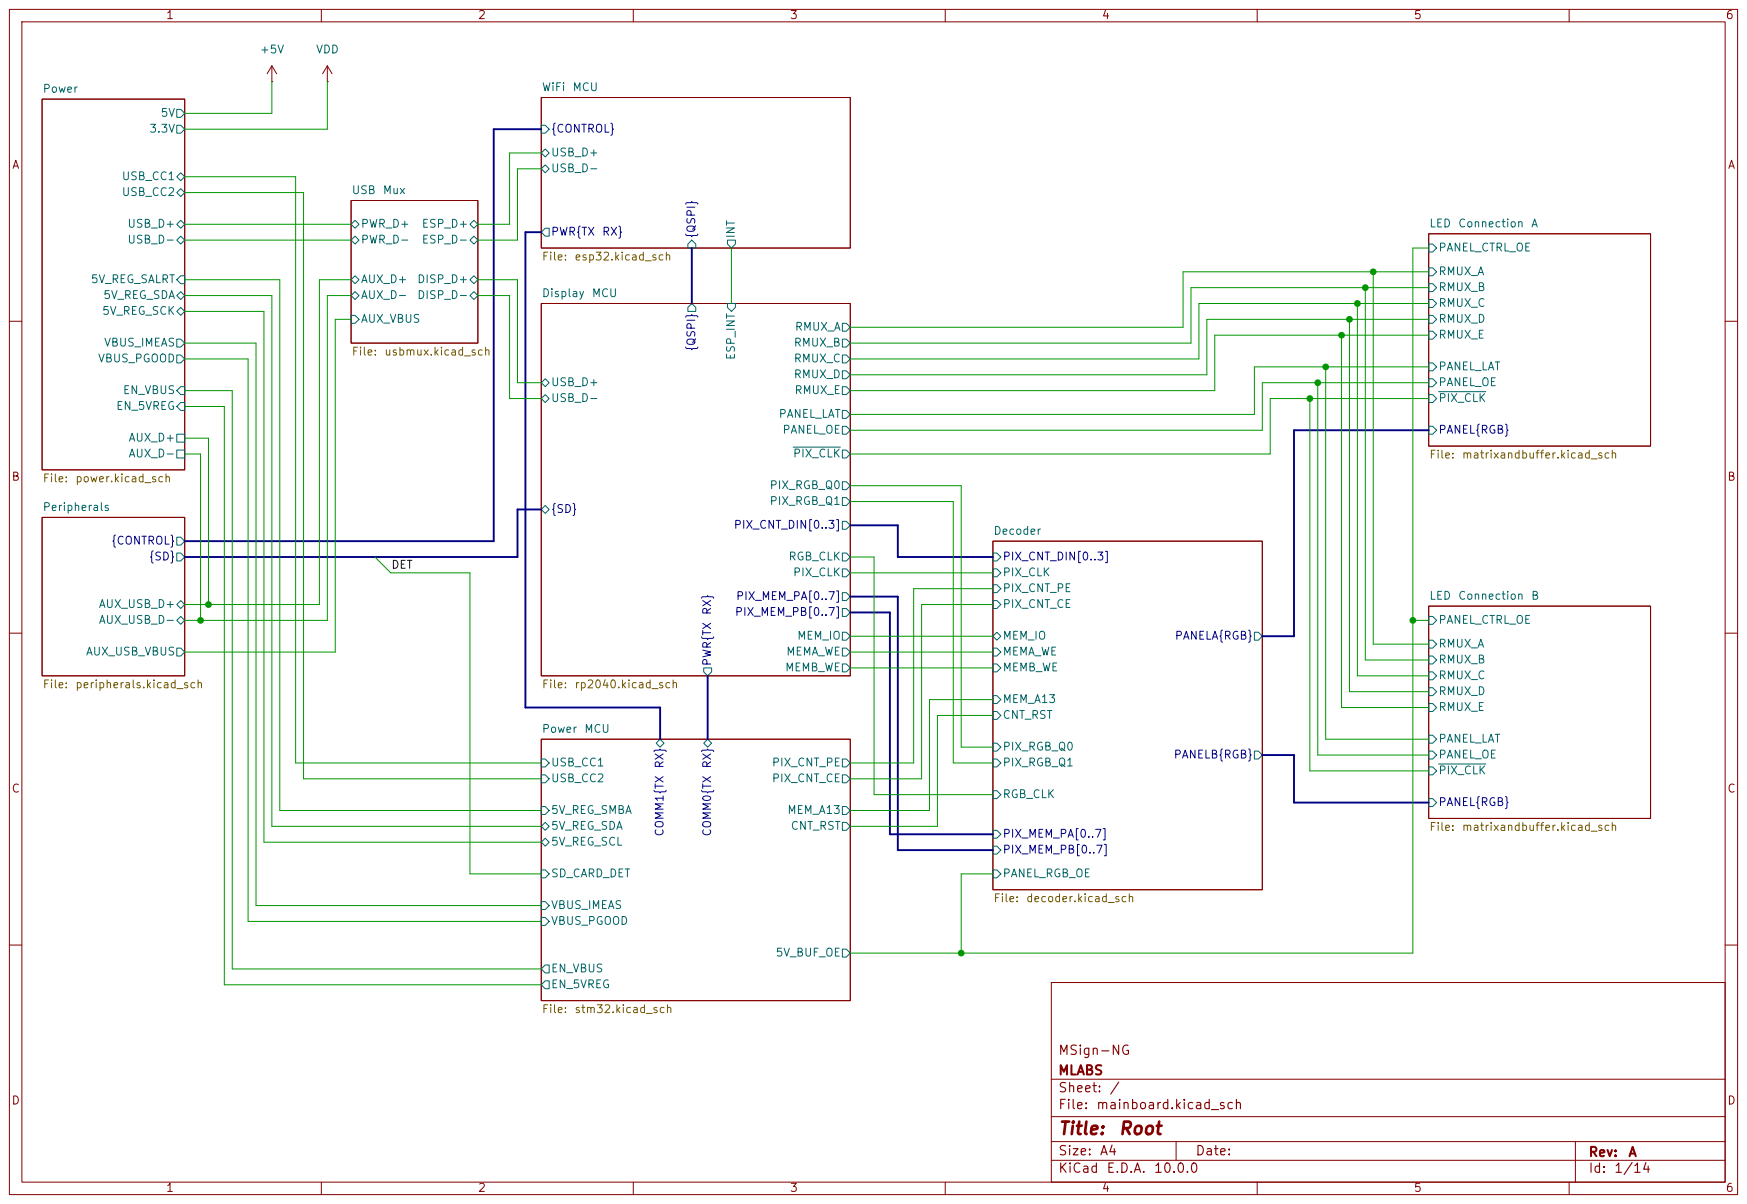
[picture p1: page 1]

PIX_CNT_PE COMM0{TX RX} COMM1{TX RX} SD_CARD_DET Power MCU

Sheet: / MLABS MSign-NG

Size: A4 | Rev: A
KiCad E.D.A. 10.0.0 | Id: 1/14

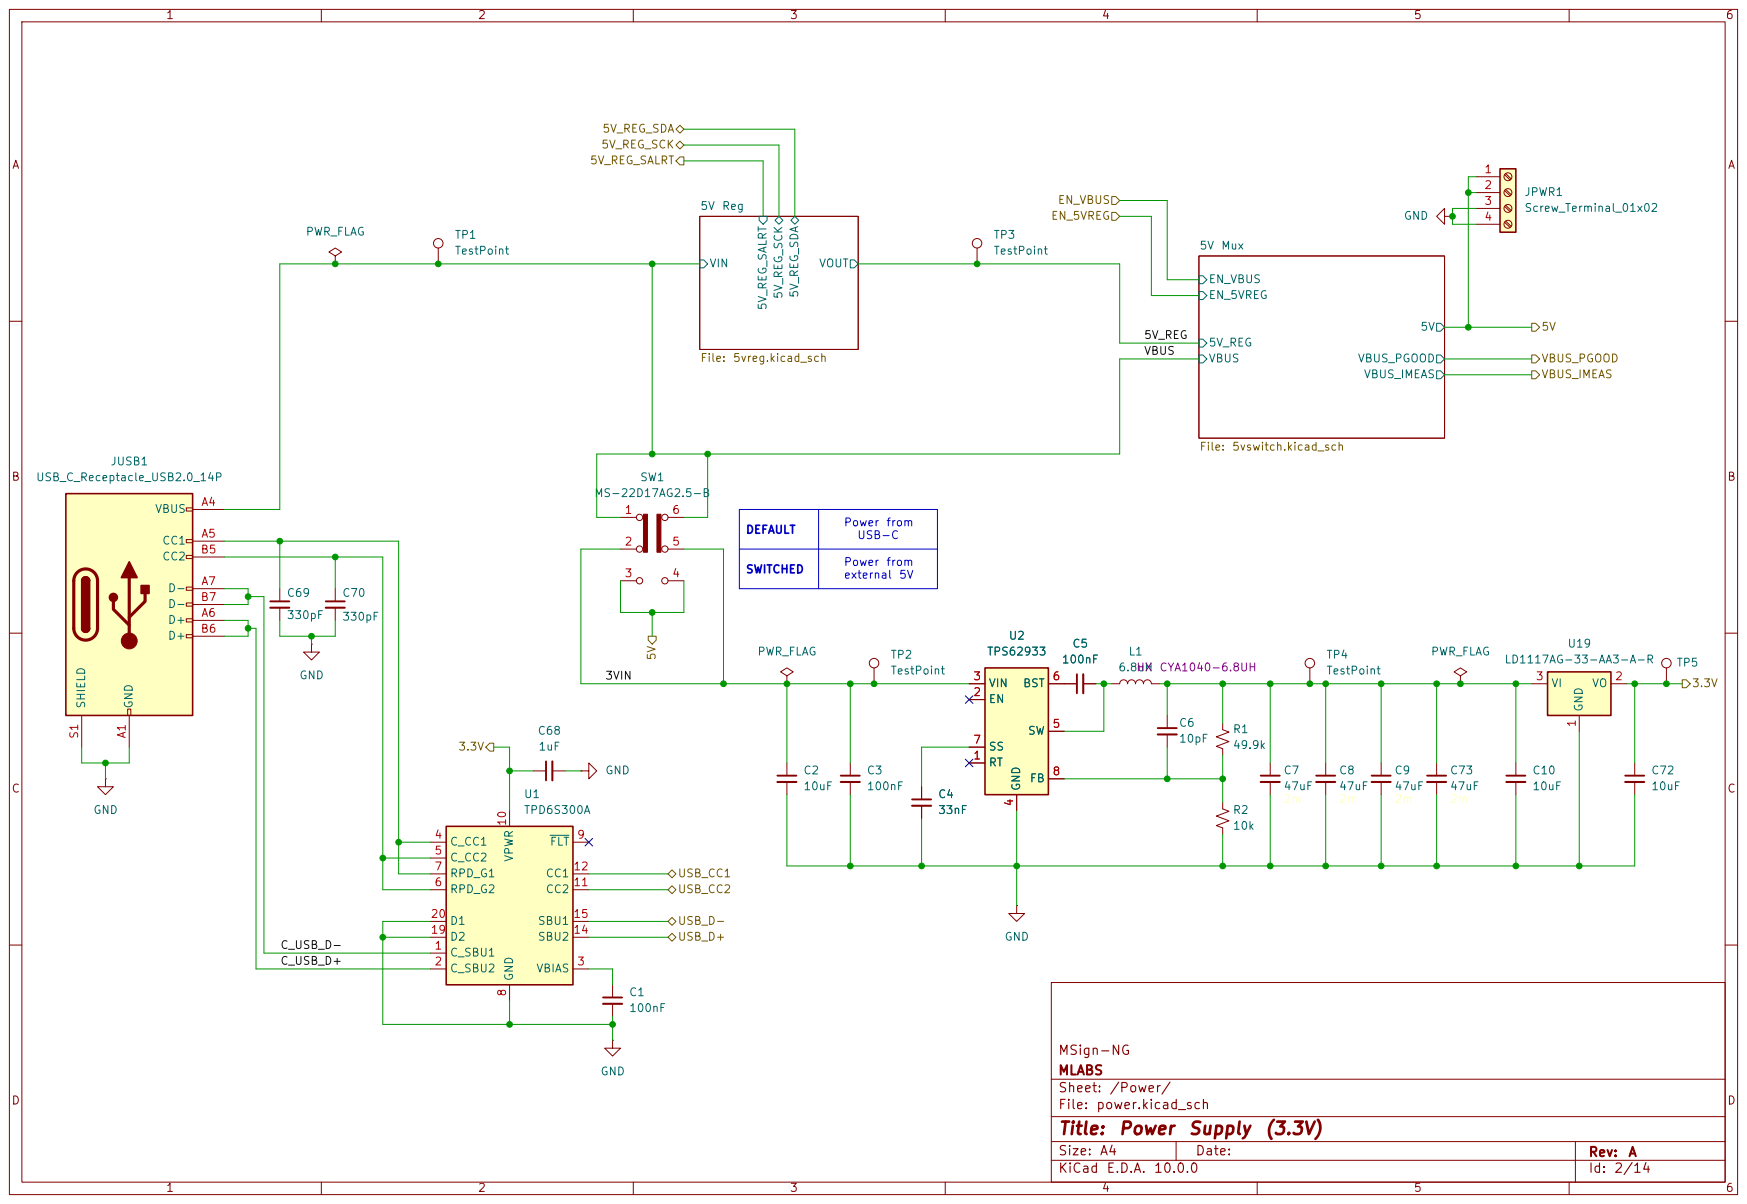
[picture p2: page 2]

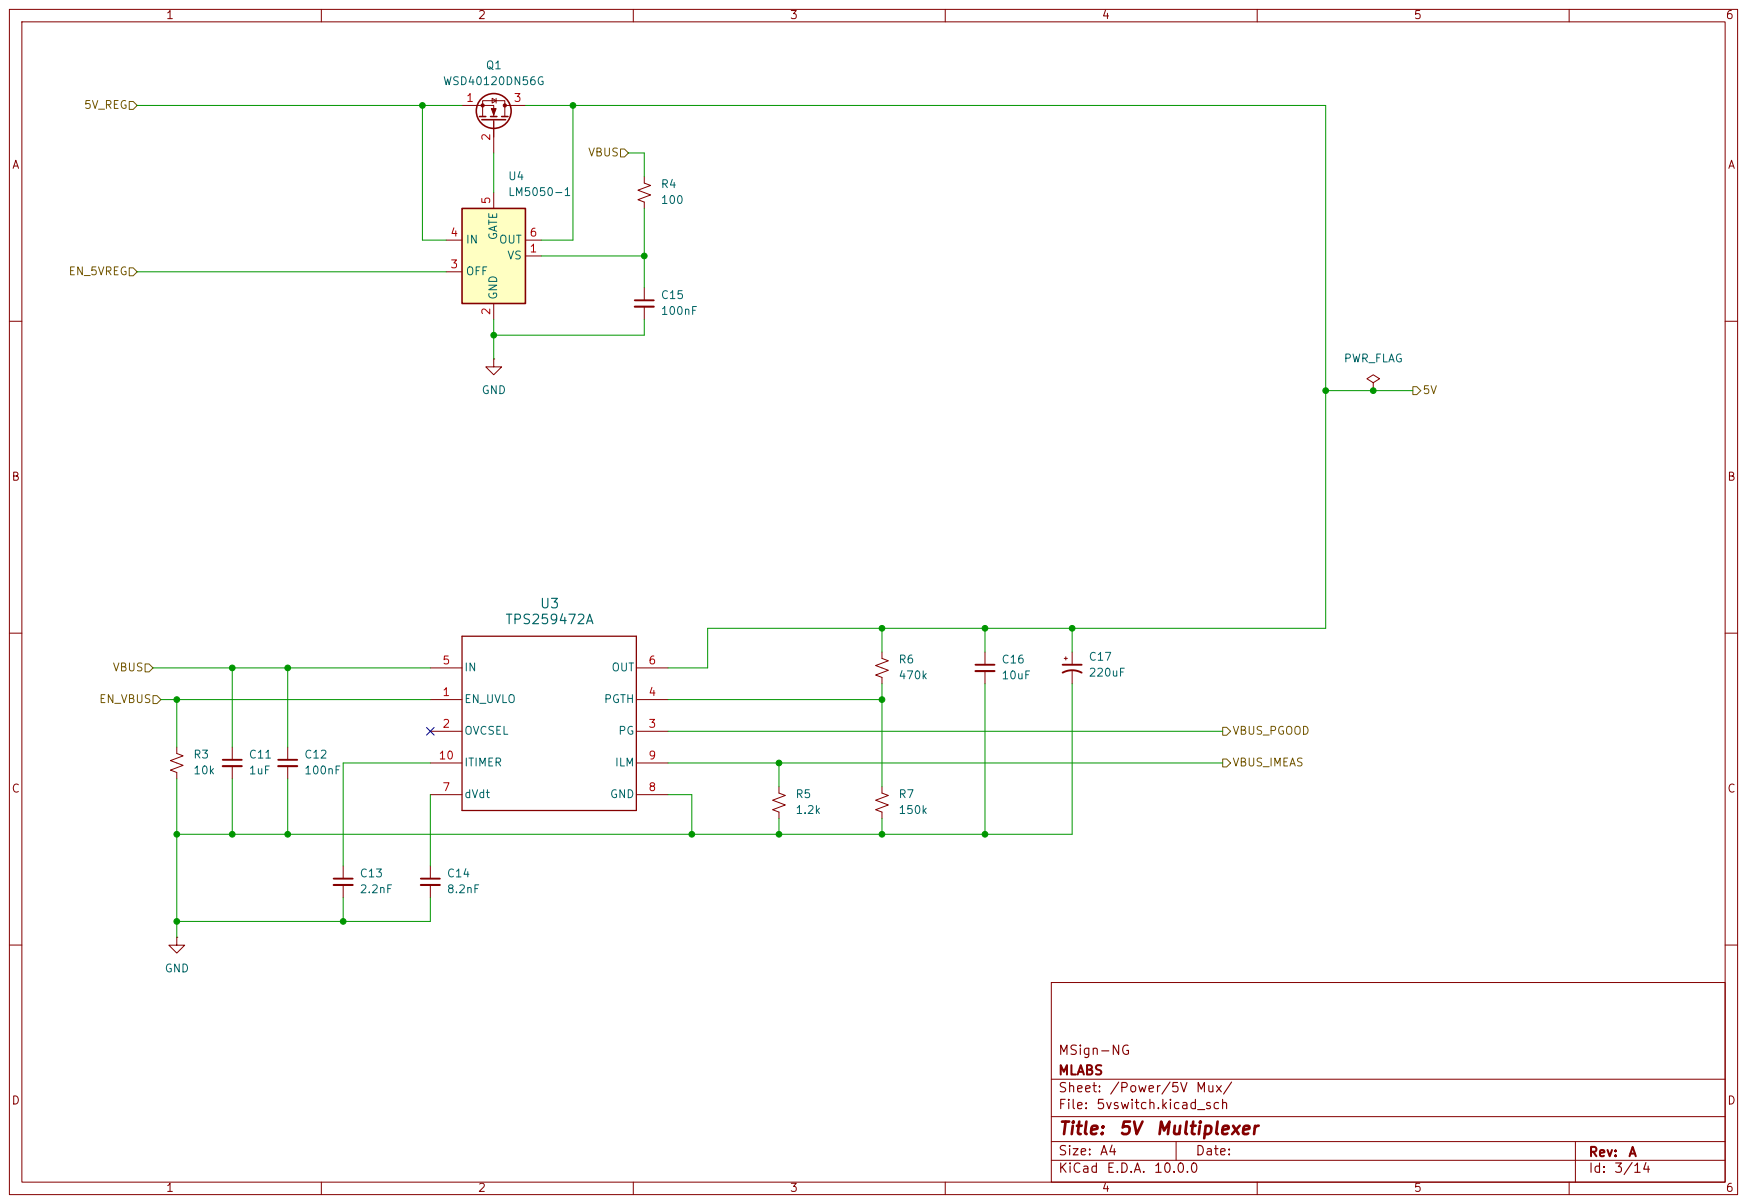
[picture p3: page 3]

Sheet: /Power/5V Mux/ MLABS MSign-NG

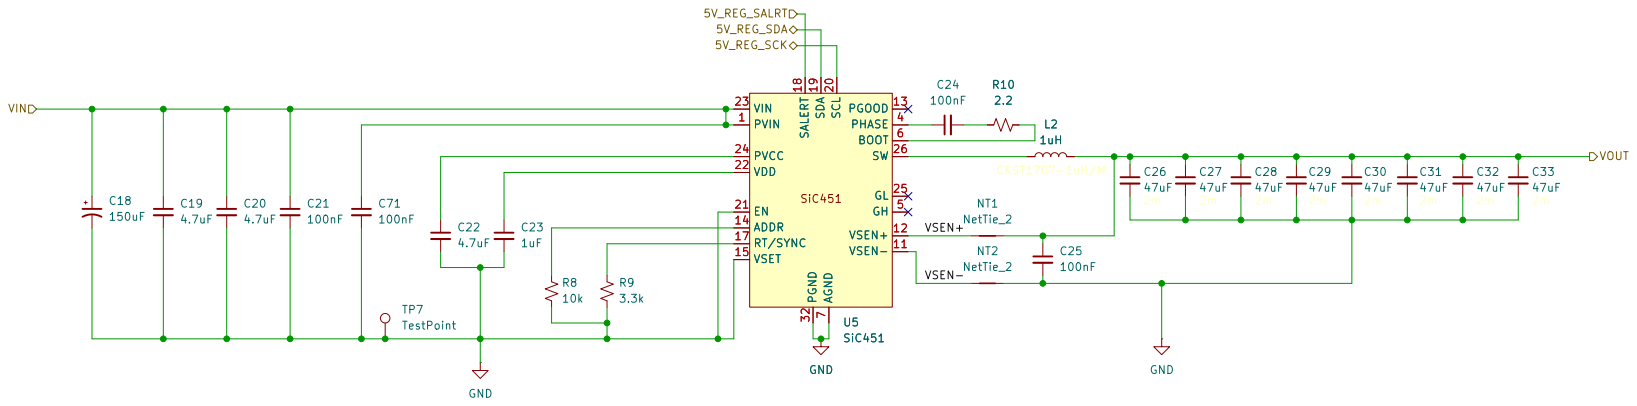
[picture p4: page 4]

Sheet: /Power/5V Reg/ MLABS MSign-NG

File: 5vreg.kicad_sch
Title: USB PD 5V Regulator

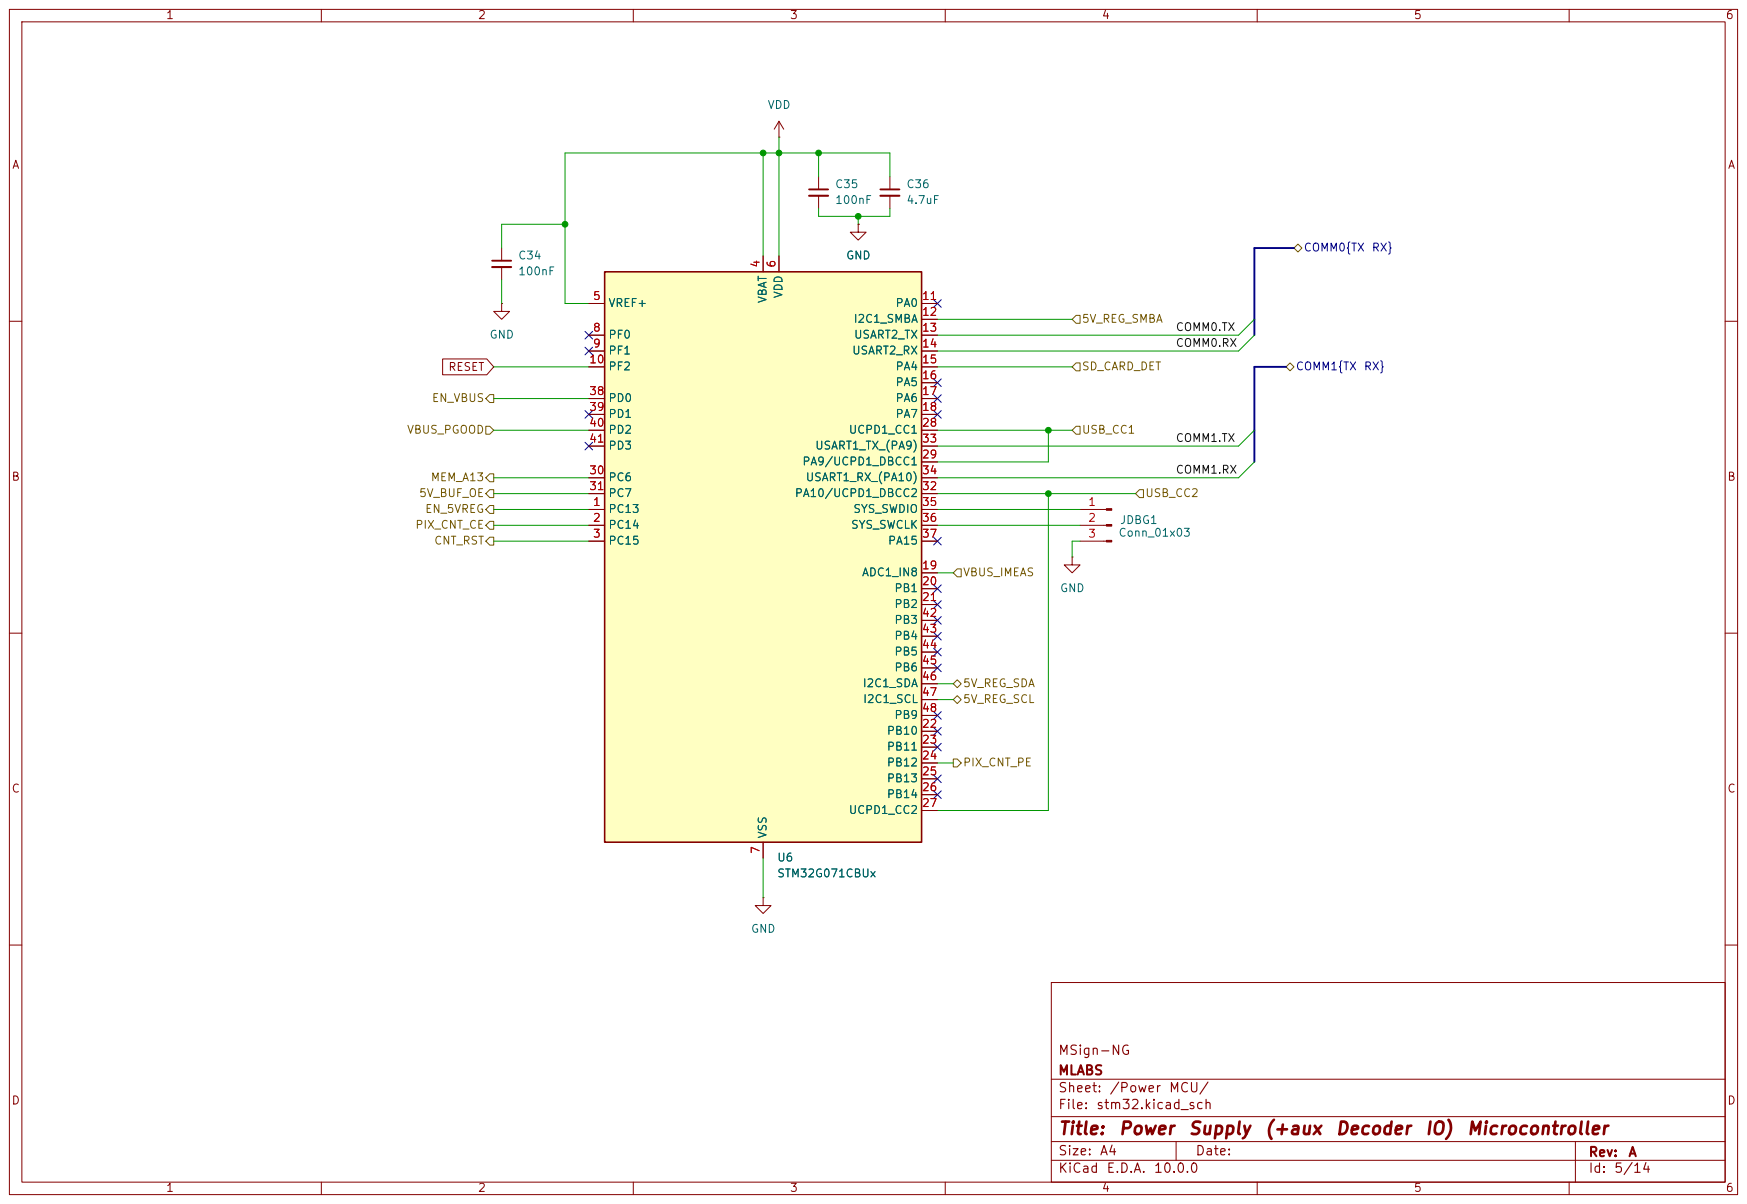
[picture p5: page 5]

Sheet: /Power MCU/ MLABS MSign-NG

File: stm32.kicad_sch
Title: Power Supply (+aux Decoder IO) Microcontroller

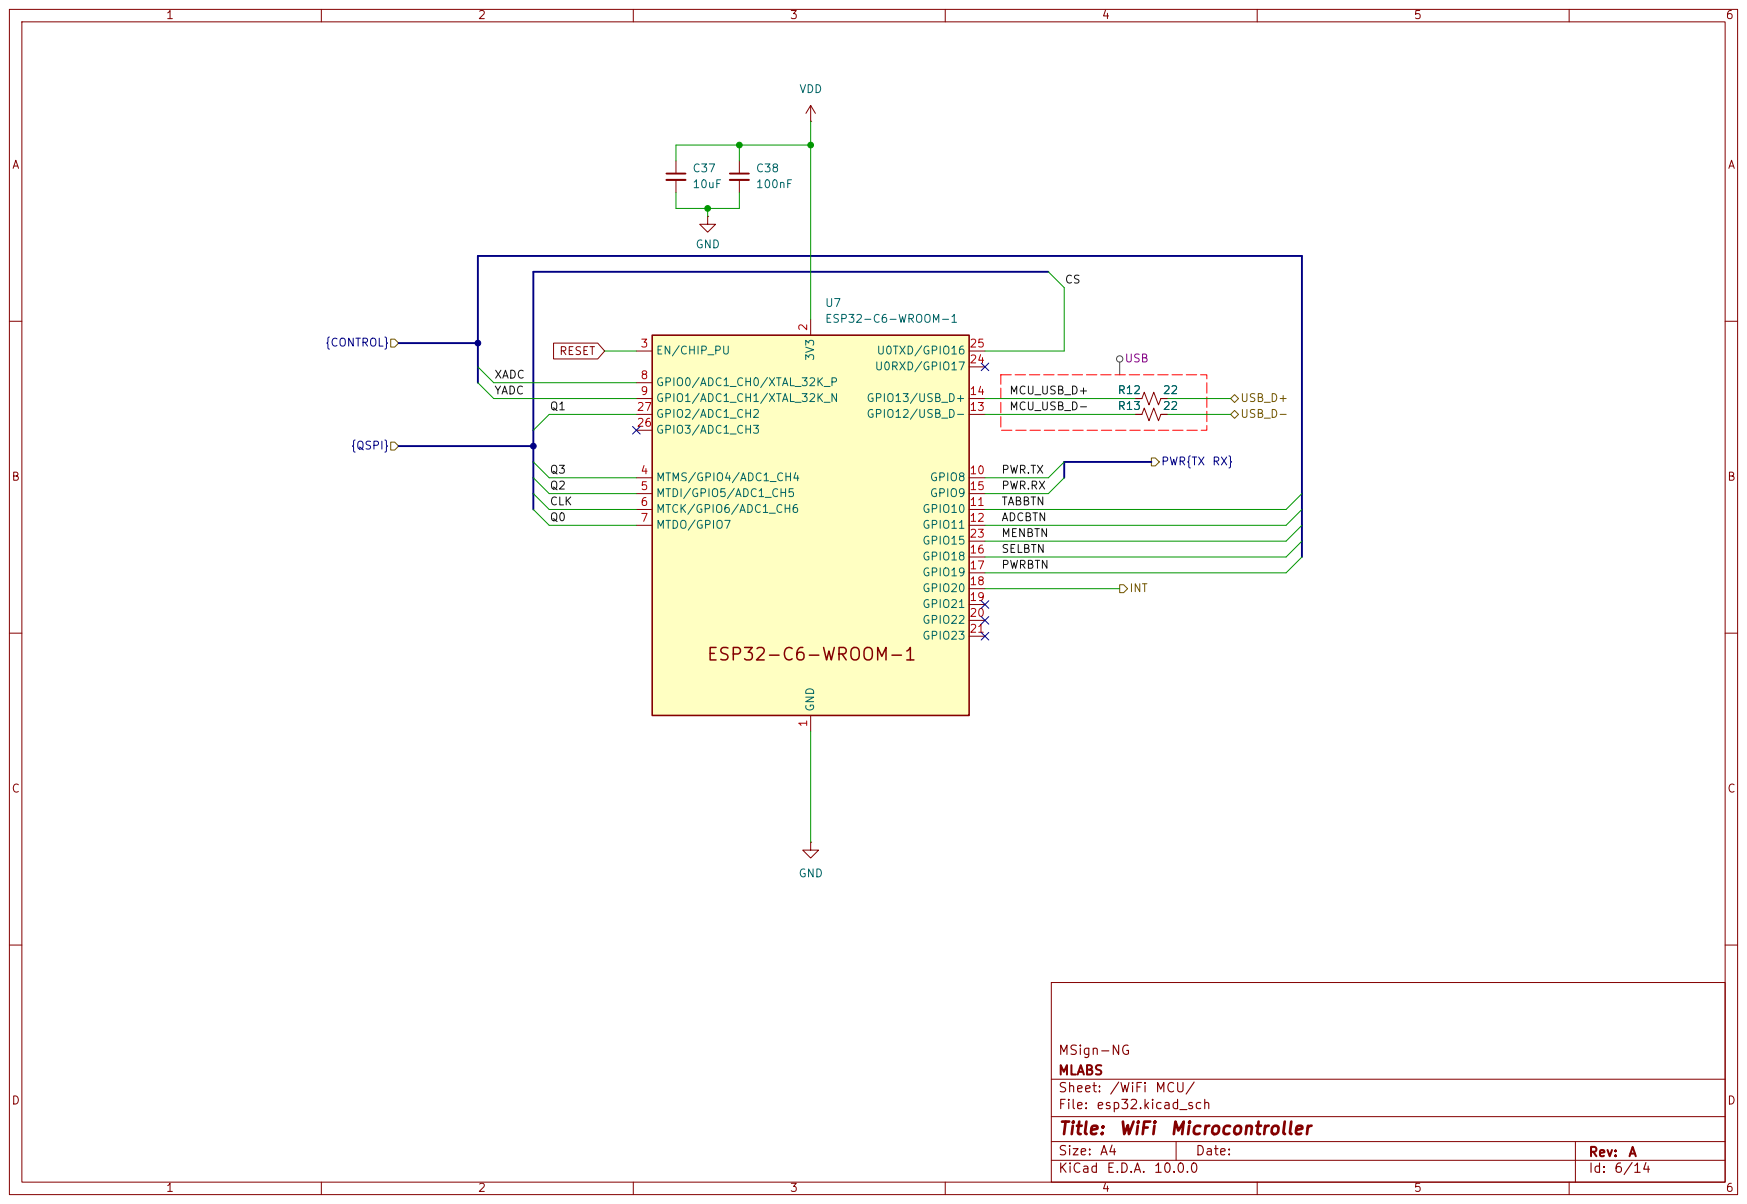
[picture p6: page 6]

Sheet: /WiFi MCU/ MLABS MSign-NG

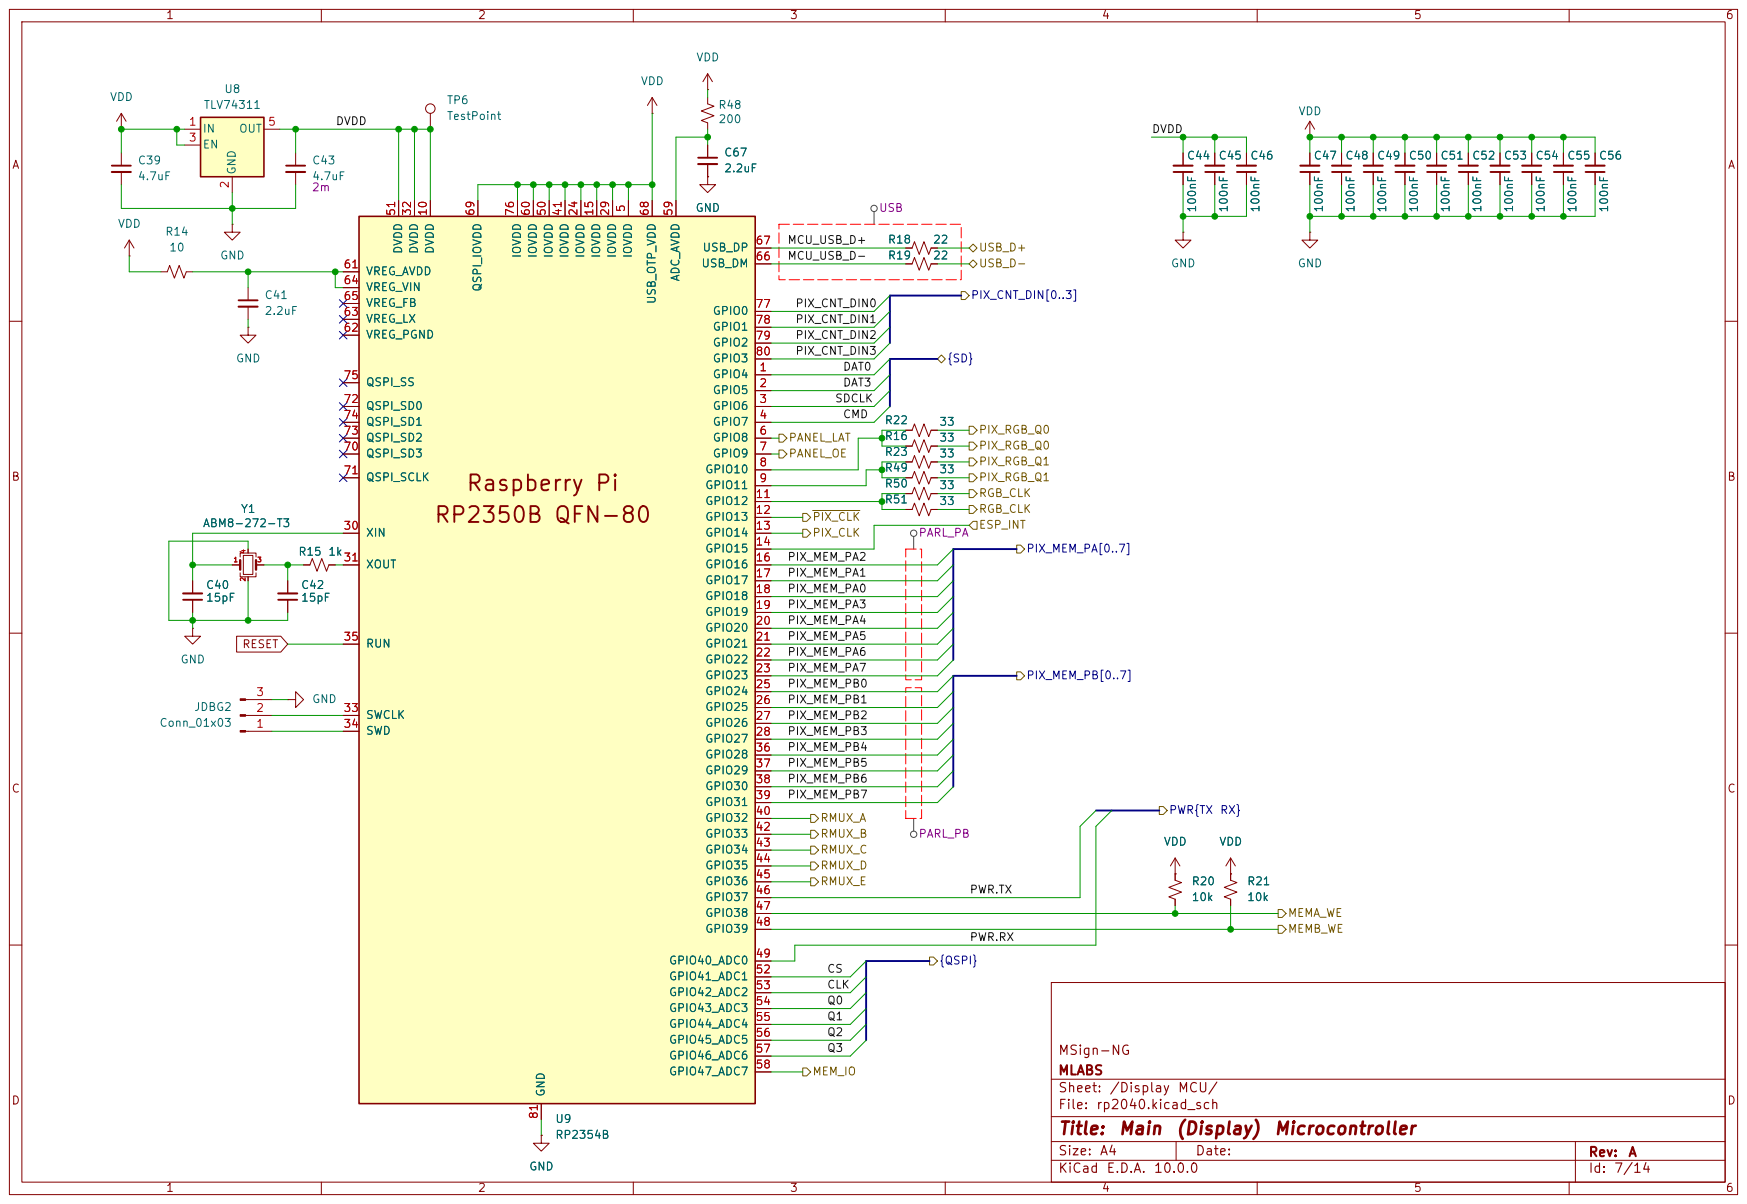
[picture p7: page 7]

5 GPIO8 6 GPIO9 7 GPIO10 8 GPIO11 9 DVDD 10 GPIO12 11 GPIO13 12 GPIO14 13 GPIO15 14 IOVDD 15 GPIO16 16 GPIO17 17 GPIO18 18 GPIO19 19 GPIO20 20 GPIO21 21 GPIO22 22 GPIO23 23 IOVDD 24 GPIO24 25 GPIO25 26 GPIO26 27 GPIO27 28 IOVDD 29
GND Raspberry Pi
RP2350B QFN-80

Sheet: /Display MCU/ MLABS MSign-NG

File: rp2040.kicad_sch
Title: Main (Display) Microcontroller

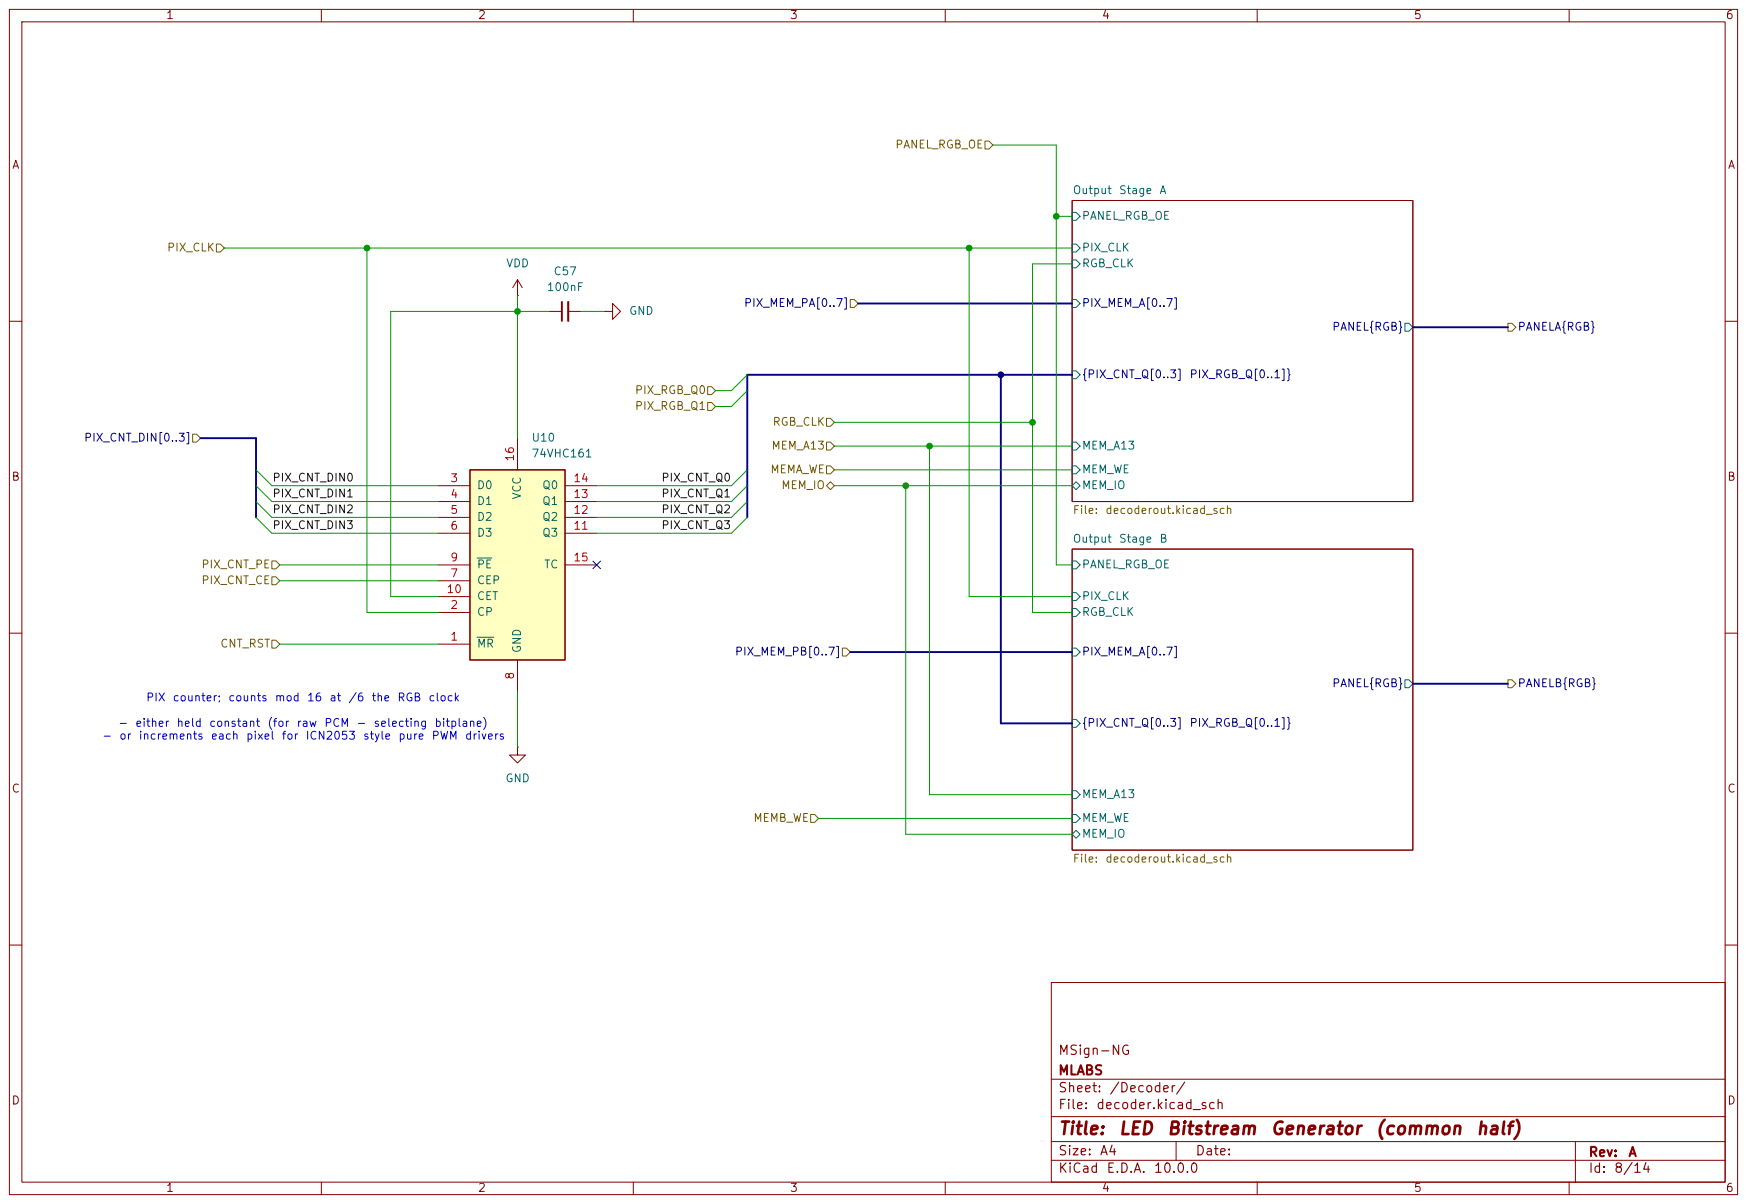
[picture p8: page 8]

Sheet: /Decoder/ MLABS MSign-NG

File: decoder.kicad_sch
Title: LED Bitstream Generator (common half)

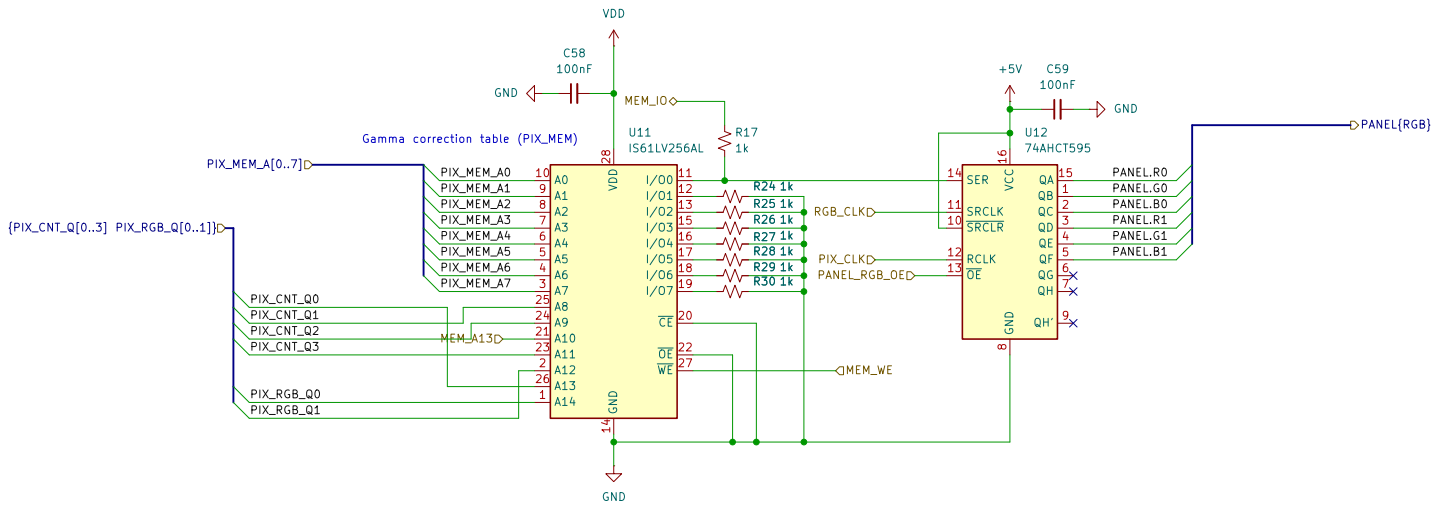
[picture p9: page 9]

Sheet: /Decoder/Output Stage A/ MLABS MSign-NG GND 14 VDD 28

File: decoderout.kicad_sch
Title: LED Bitstream Generator (gamma LUT + shifter)

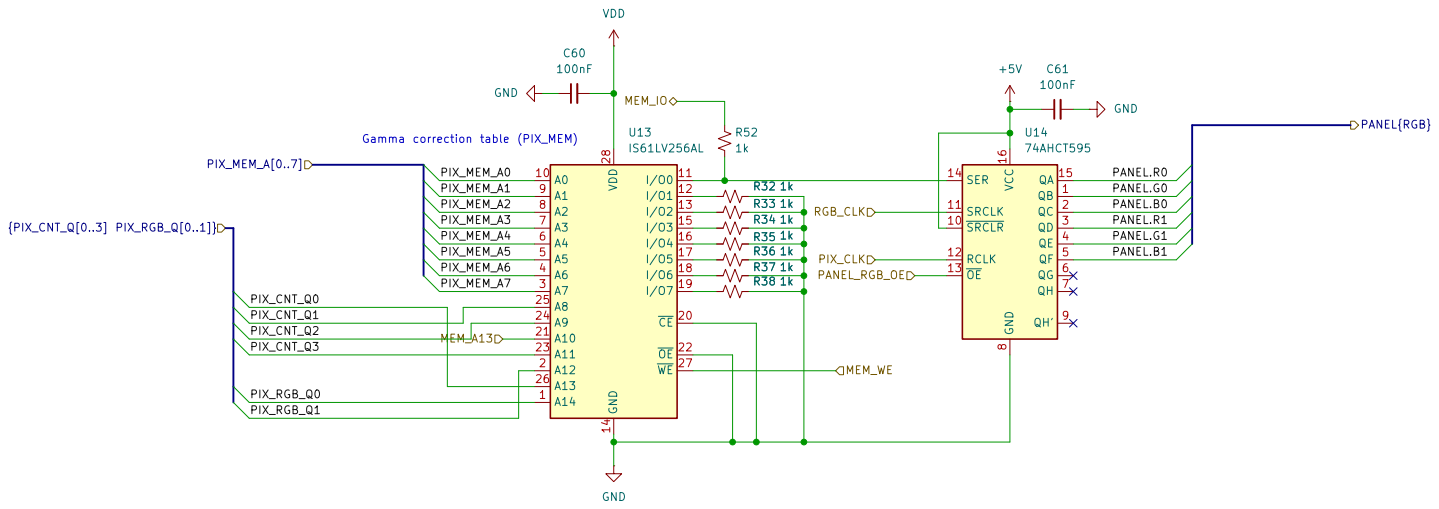
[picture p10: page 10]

Sheet: /Decoder/Output Stage B/ MLABS MSign-NG GND 14 VDD 28

File: decoderout.kicad_sch
Title: LED Bitstream Generator (gamma LUT + shifter)

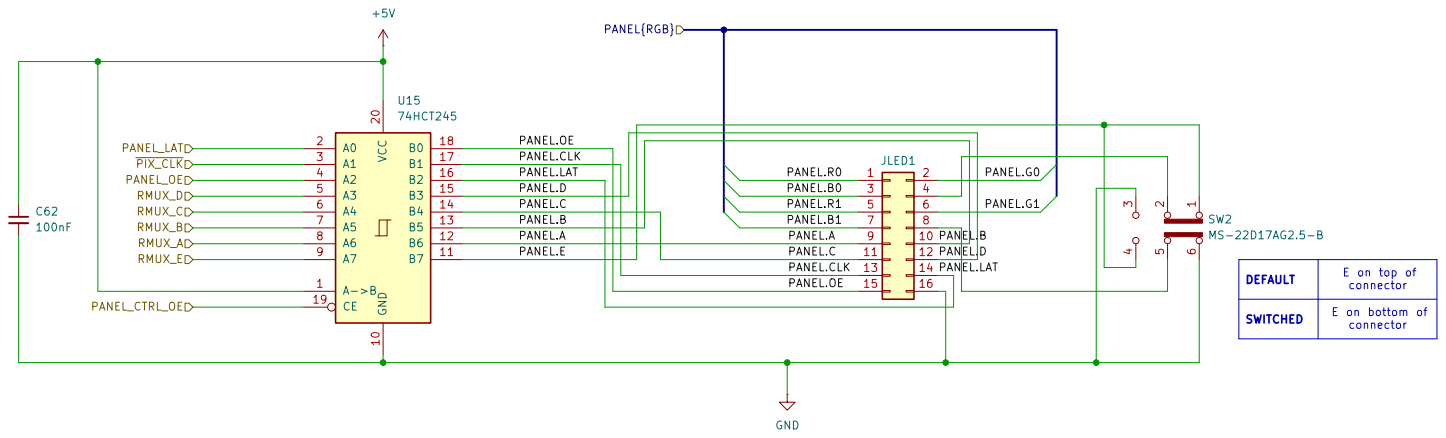
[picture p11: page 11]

Sheet: /LED Connection A/ MLABS MSign-NG

File: matrixandbuffer.kicad_sch
Title: LED Level Shifter + Socket

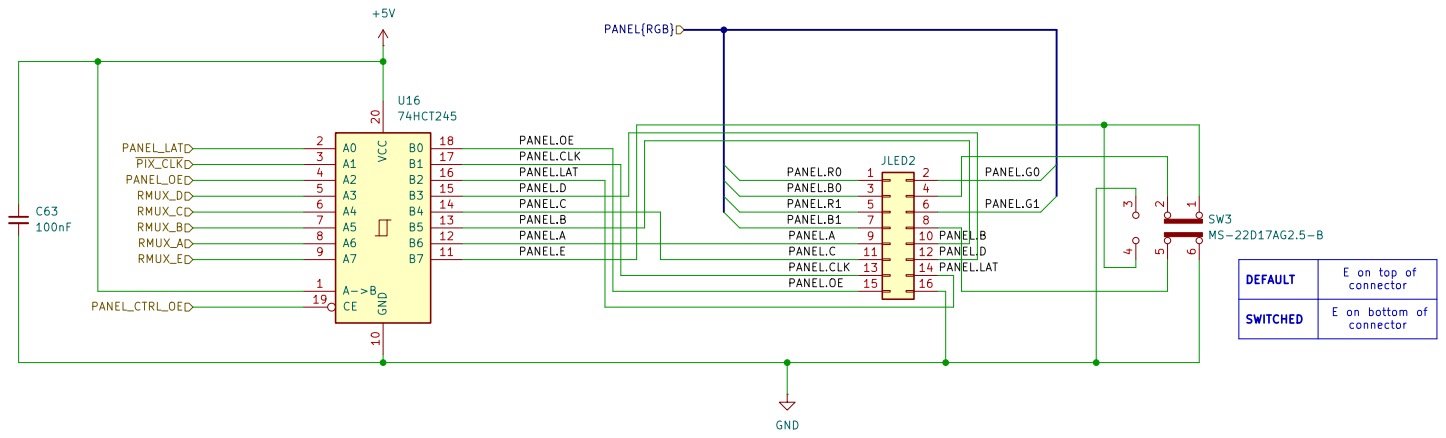
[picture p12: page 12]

Sheet: /LED Connection B/ MLABS MSign-NG

File: matrixandbuffer.kicad_sch
Title: LED Level Shifter + Socket


Sheet: /Peripherals/ MLABS MSign-NG

File: peripherals.kicad_sch
Title: Misc. External Connectors


Sheet: /USB Mux/ MLABS MSign-NG

File: usbmux.kicad_sch
Title: USB Port Crosspoint Switch

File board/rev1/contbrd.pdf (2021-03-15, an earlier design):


Reserved for extra display signals

Document Number: | REV: B

Date: 2021-02-20 9:30 PM | Sheet: 1/3


Power pins and on-board buttons
MSign
TITLE:

Document Number: | REV: B

Date: 2021-02-20 9:30 PM | Sheet: 2/3


External connectors and sockets

Document Number: | REV: B

Date: 2021-02-20 9:30 PM | Sheet: 3/3

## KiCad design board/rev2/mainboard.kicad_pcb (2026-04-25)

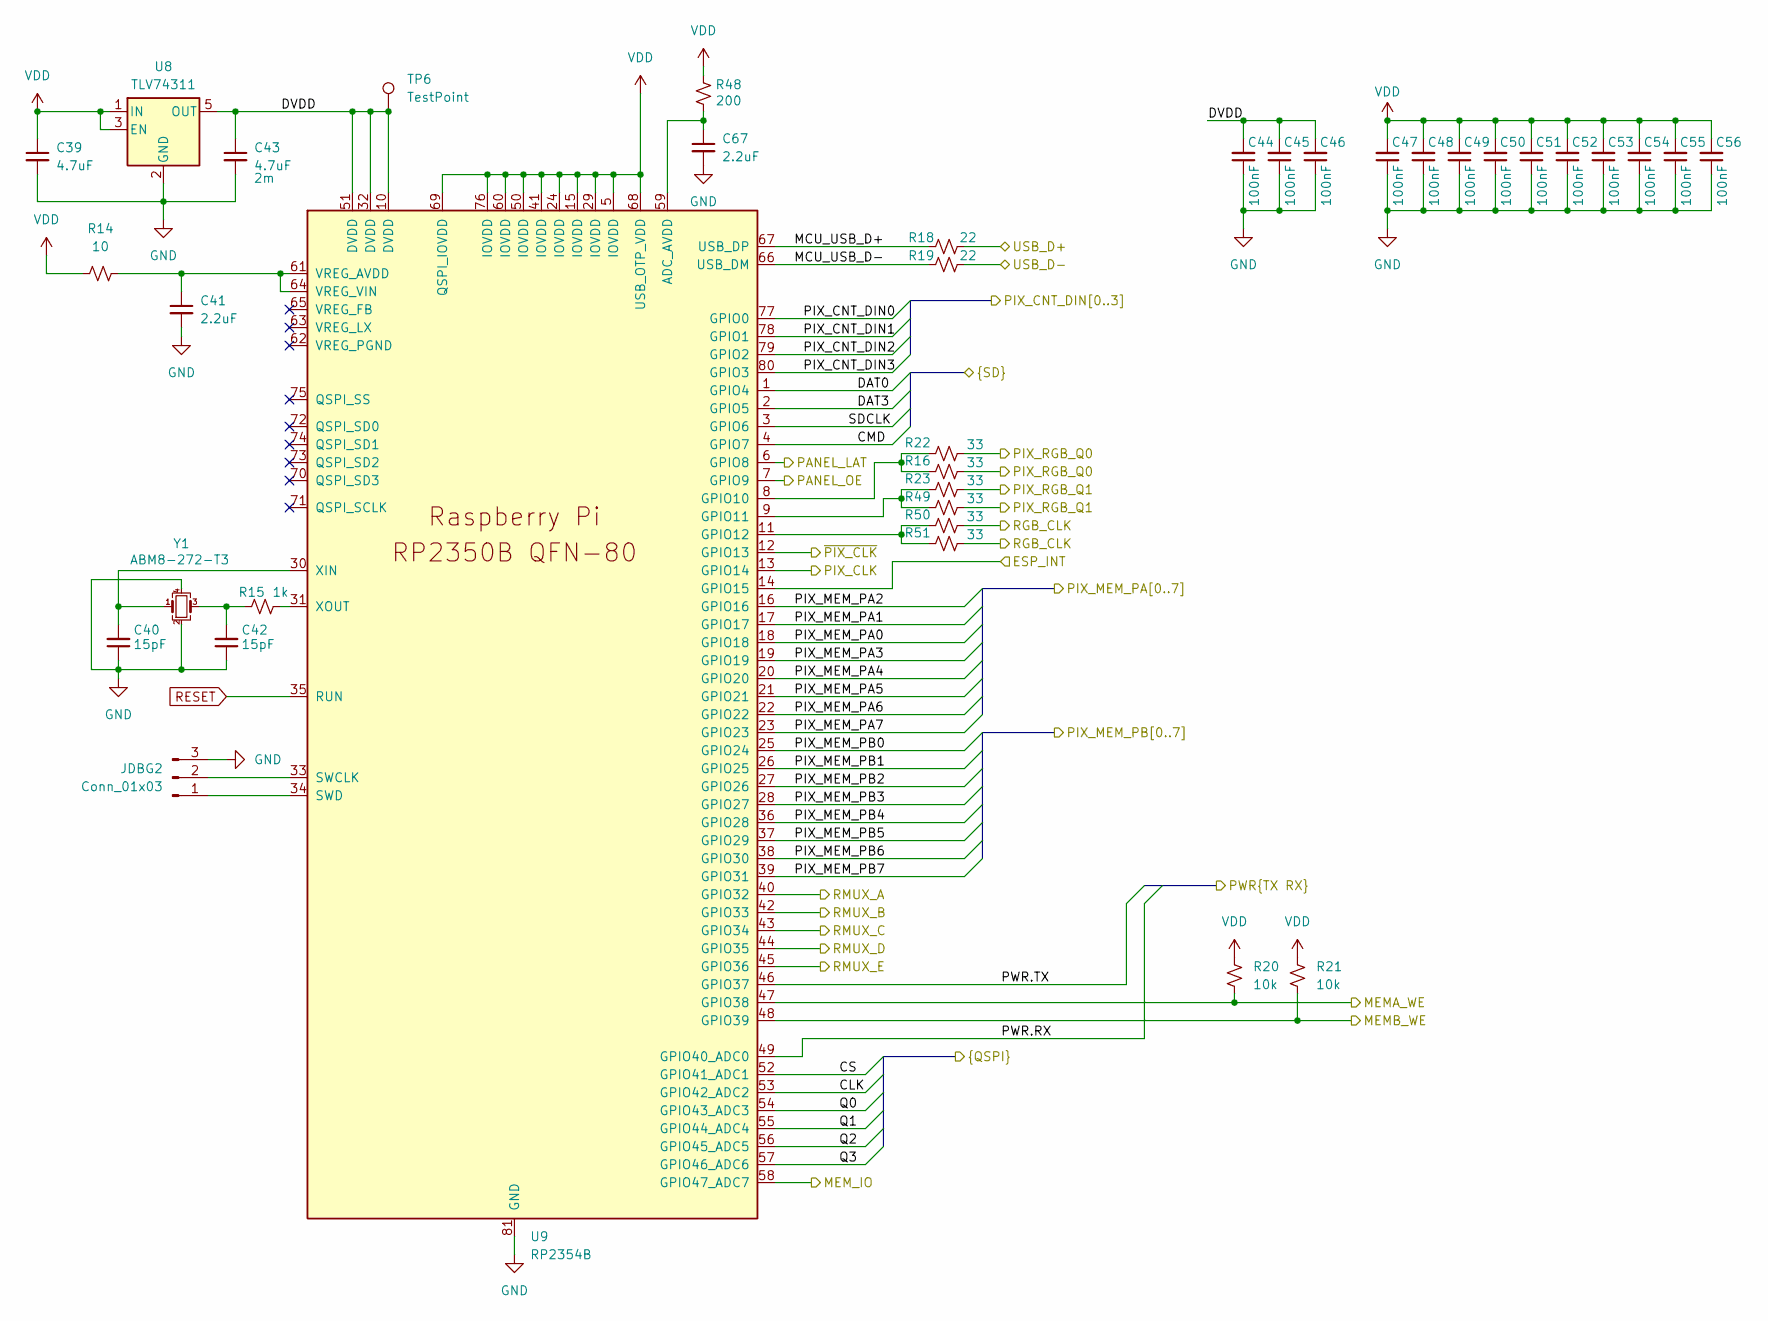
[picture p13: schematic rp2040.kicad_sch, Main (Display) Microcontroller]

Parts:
C39, C43: 4.7uF; C_1206_3216Metric; Part 1206B475K500NT; LCSC C29823
C40, C42: 15pF; C_0402_1005Metric; Part 0402CG150J500NT; LCSC C1548
C41, C67: 2.2uF; C_0603_1608Metric; Part CL10A225KO8NNNC; LCSC C23630
C44, C45, C46, C47, C48, C49, C50, C51, C52, C53, C54, C55, C56: 100nF; C_0402_1005Metric; Part CL05B104KB54PNC; LCSC C307331
JDBG2: Conn_01x03; PinHeader_1x03_P2.54mm_Vertical
R14: 10; R_0402_1005Metric; Part 0402WGF100JTCE; LCSC C25077
R15: 1k; R_0402_1005Metric; Part 0402WGF1001TCE; LCSC C11702
R16, R22, R23, R49, R50, R51: 33; R_0402_1005Metric; Part 0402WGF330JTCE; LCSC C25105
R18, R19: 22; R_0402_1005Metric; Part 0402WGF220JTCE; LCSC C25092
R20, R21: 10k; R_0402_1005Metric; Part 0402WGF1002TCE; LCSC C25744
R48: 200; R_0402_1005Metric; Part 0402WGF2000TCE; LCSC C25087
TP6: TestPoint; TestPoint_Pad_D1.0mm
U8: TLV74311; SOT-23-5; Part TLV74311PDBVR; LCSC C485147
U9: RP2354B; RP2350-QFN-80-1EP_10x10_P0.4mm_EP3.4x3.4mm_ThermalVias; Part RP2354B; LCSC C39843328
Y1: ABM8-272-T3; Crystal_SMD_3225-4Pin_3.2x2.5mm; Part ABM8-272-T3; LCSC C20625731

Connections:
/Decoder/MEMA_WE: R20.2, U9.47 (GPIO38); also elsewhere on the board
/Decoder/MEMB_WE: R21.2, U9.48 (GPIO39); also elsewhere on the board
/Decoder/MEM_IO: U9.58 (GPIO47_ADC7); also elsewhere on the board
/Decoder/Output Stage A/PIX_RGB_Q0: R16.2, R22.2; also elsewhere on the board
/Decoder/Output Stage A/PIX_RGB_Q1: R23.2, R49.2; also elsewhere on the board
/Decoder/PIX_CLK: U9.13 (GPIO14); also elsewhere on the board
/Decoder/PIX_CNT_DIN0: U9.77 (GPIO0); also elsewhere on the board
/Decoder/PIX_CNT_DIN1: U9.78 (GPIO1); also elsewhere on the board
/Decoder/PIX_CNT_DIN2: U9.79 (GPIO2); also elsewhere on the board
/Decoder/PIX_CNT_DIN3: U9.80 (GPIO3); also elsewhere on the board
/Decoder/PIX_MEM_PA0: U9.25 (GPIO24); also elsewhere on the board
/Decoder/PIX_MEM_PA1: U9.26 (GPIO25); also elsewhere on the board
/Decoder/PIX_MEM_PA2: U9.27 (GPIO26); also elsewhere on the board
/Decoder/PIX_MEM_PA3: U9.28 (GPIO27); also elsewhere on the board
/Decoder/PIX_MEM_PA4: U9.36 (GPIO28); also elsewhere on the board
/Decoder/PIX_MEM_PA5: U9.37 (GPIO29); also elsewhere on the board
/Decoder/PIX_MEM_PA6: U9.38 (GPIO30); also elsewhere on the board
/Decoder/PIX_MEM_PA7: U9.39 (GPIO31); also elsewhere on the board
/Decoder/PIX_MEM_PB0: U9.18 (GPIO18); also elsewhere on the board
/Decoder/PIX_MEM_PB1: U9.17 (GPIO17); also elsewhere on the board
/Decoder/PIX_MEM_PB2: U9.16 (GPIO16); also elsewhere on the board
/Decoder/PIX_MEM_PB3: U9.19 (GPIO19); also elsewhere on the board
/Decoder/PIX_MEM_PB4: U9.20 (GPIO20); also elsewhere on the board
/Decoder/PIX_MEM_PB5: U9.21 (GPIO21); also elsewhere on the board
/Decoder/PIX_MEM_PB6: U9.22 (GPIO22); also elsewhere on the board
/Decoder/PIX_MEM_PB7: U9.23 (GPIO23); also elsewhere on the board
/Decoder/RGB_CLK: R50.2, R51.2; also elsewhere on the board
/Display MCU/CLK: U9.53 (GPIO42_ADC2); also elsewhere on the board
/Display MCU/CMD: U9.4 (GPIO7); also elsewhere on the board
/Display MCU/CS: U9.52 (GPIO41_ADC1); also elsewhere on the board
/Display MCU/DAT0: U9.1 (GPIO4); also elsewhere on the board
/Display MCU/DAT3: U9.2 (GPIO5); also elsewhere on the board
/Display MCU/DVDD: C43.1, C44.2, C45.2, C46.2, TP6.1 (1_1), U8.5 (OUT), U9.10 (DVDD), U9.32 (DVDD), U9.51 (DVDD)
/Display MCU/ESP_INT: U9.14 (GPIO15); also elsewhere on the board
/Display MCU/MCU_USB_D+: R18.1, U9.67 (USB_DP)
/Display MCU/MCU_USB_D-: R19.1, U9.66 (USB_DM)
/Display MCU/PANEL_LAT: U9.6 (GPIO8); also elsewhere on the board
/Display MCU/PANEL_OE: U9.7 (GPIO9); also elsewhere on the board
/Display MCU/PWR.RX: U9.49 (GPIO40_ADC0); also elsewhere on the board
/Display MCU/PWR.TX: U9.46 (GPIO37); also elsewhere on the board
/Display MCU/Q0: U9.54 (GPIO43_ADC3); also elsewhere on the board
/Display MCU/Q1: U9.55 (GPIO44_ADC4); also elsewhere on the board
/Display MCU/Q2: U9.56 (GPIO45_ADC5); also elsewhere on the board
/Display MCU/Q3: U9.57 (GPIO46_ADC6); also elsewhere on the board
/Display MCU/RMUX_A: U9.40 (GPIO32); also elsewhere on the board
/Display MCU/RMUX_B: U9.42 (GPIO33); also elsewhere on the board
/Display MCU/RMUX_C: U9.43 (GPIO34); also elsewhere on the board
/Display MCU/RMUX_D: U9.44 (GPIO35); also elsewhere on the board
/Display MCU/RMUX_E: U9.45 (GPIO36); also elsewhere on the board
/Display MCU/SDCLK: U9.3 (GPIO6); also elsewhere on the board
/Display MCU/USB_D+: R18.2; also elsewhere on the board
/Display MCU/USB_D-: R19.2; also elsewhere on the board
/Display MCU/~PIX_CLK: U9.12 (GPIO13); also elsewhere on the board
GND: C39.2, C40.1, C41.2, C42.1, C43.2, C44.1, C45.1, C46.1, C47.1, C48.1, C49.1, C50.1, C51.1, C52.1, C53.1, C54.1, C55.1, C56.1, C67.2, JDBG2.3, U8.2 (GND), U9.81 (GND), Y1.2, Y1.4; also elsewhere on the board
unnamed: C42.2, R15.1, Y1.3
unnamed: JDBG2.1, U9.34 (SWD)
unnamed: JDBG2.2, U9.33 (SWCLK)
unnamed: C67.1, R48.2, U9.59 (ADC_AVDD)
unnamed: R16.1, R22.1, U9.8 (GPIO10)
unnamed: R23.1, R49.1, U9.9 (GPIO11)
unnamed: R50.1, R51.1, U9.11 (GPIO12)
unnamed: C41.1, R14.2, U9.61 (VREG_AVDD), U9.64 (VREG_VIN)
unnamed: C40.2, U9.30 (XIN), Y1.1
unnamed: R15.2, U9.31 (XOUT)
RESET: U9.35 (RUN); also elsewhere on the board
VDD: C39.1, C47.2, C48.2, C49.2, C50.2, C51.2, C52.2, C53.2, C54.2, C55.2, C56.2, R14.1, R20.1, R21.1, R48.1, U8.1 (IN), U8.3 (EN), U9.5 (IOVDD), U9.15 (IOVDD), U9.24 (IOVDD), U9.29 (IOVDD), U9.41 (IOVDD), U9.50 (IOVDD), U9.60 (IOVDD), U9.68 (USB_OTP_VDD), U9.69 (QSPI_IOVDD), U9.76 (IOVDD); also elsewhere on the board

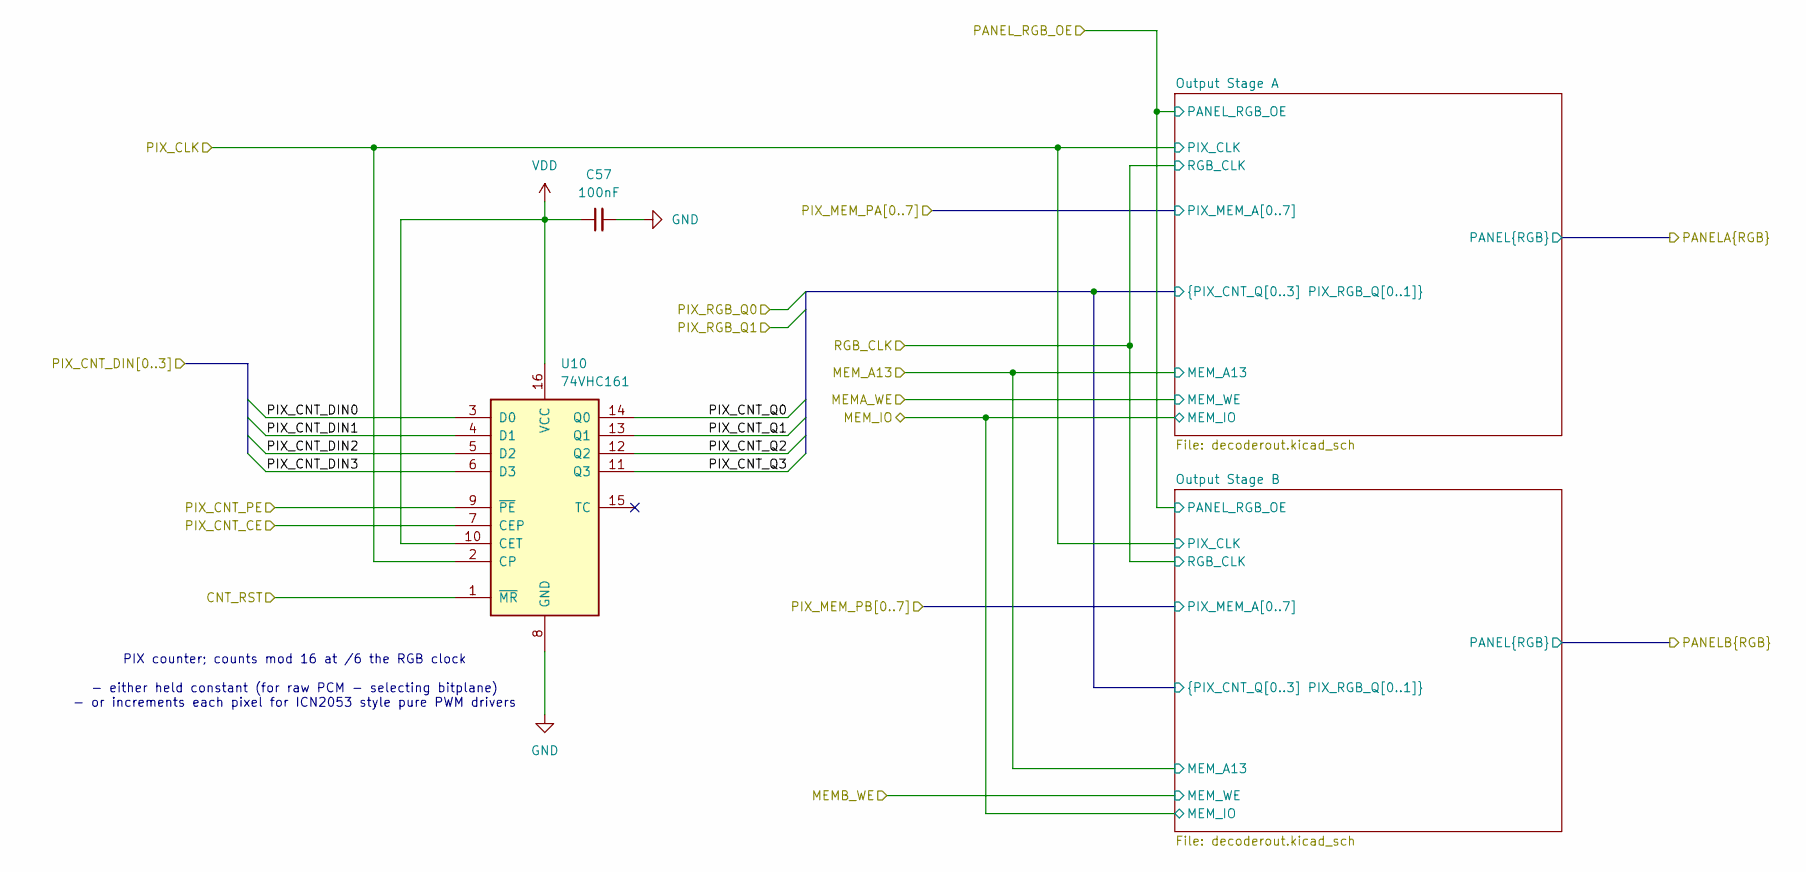
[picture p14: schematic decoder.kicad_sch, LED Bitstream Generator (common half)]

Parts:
C57: 100nF; C_0402_1005Metric; Part CL05B104KB54PNC; LCSC C307331
U10: 74VHC161; TSSOP-16_4.4x5mm_P0.65mm; Part 74VHC161FT(BJ); LCSC C7421276

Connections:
/Decoder/CNT_RST: U10.1 (~MR); also elsewhere on the board
/Decoder/Output Stage A/PIX_CNT_Q0: U10.14 (Q0); also elsewhere on the board
/Decoder/Output Stage A/PIX_CNT_Q1: U10.13 (Q1); also elsewhere on the board
/Decoder/Output Stage A/PIX_CNT_Q2: U10.12 (Q2); also elsewhere on the board
/Decoder/Output Stage A/PIX_CNT_Q3: U10.11 (Q3); also elsewhere on the board
/Decoder/PIX_CLK: U10.2 (CP); also elsewhere on the board
/Decoder/PIX_CNT_CE: U10.7 (CEP); also elsewhere on the board
/Decoder/PIX_CNT_DIN0: U10.3 (D0); also elsewhere on the board
/Decoder/PIX_CNT_DIN1: U10.4 (D1); also elsewhere on the board
/Decoder/PIX_CNT_DIN2: U10.5 (D2); also elsewhere on the board
/Decoder/PIX_CNT_DIN3: U10.6 (D3); also elsewhere on the board
/Decoder/PIX_CNT_PE: U10.9 (~PE); also elsewhere on the board
GND: C57.2, U10.8 (GND); also elsewhere on the board
VDD: C57.1, U10.10 (CET), U10.16 (VCC); also elsewhere on the board

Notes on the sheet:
PIX counter; counts mod 16 at /6 the RGB clock - either held constant (for raw PCM - selecting bitplane) - or increments each pixel for ICN2053 style pure PWM drivers

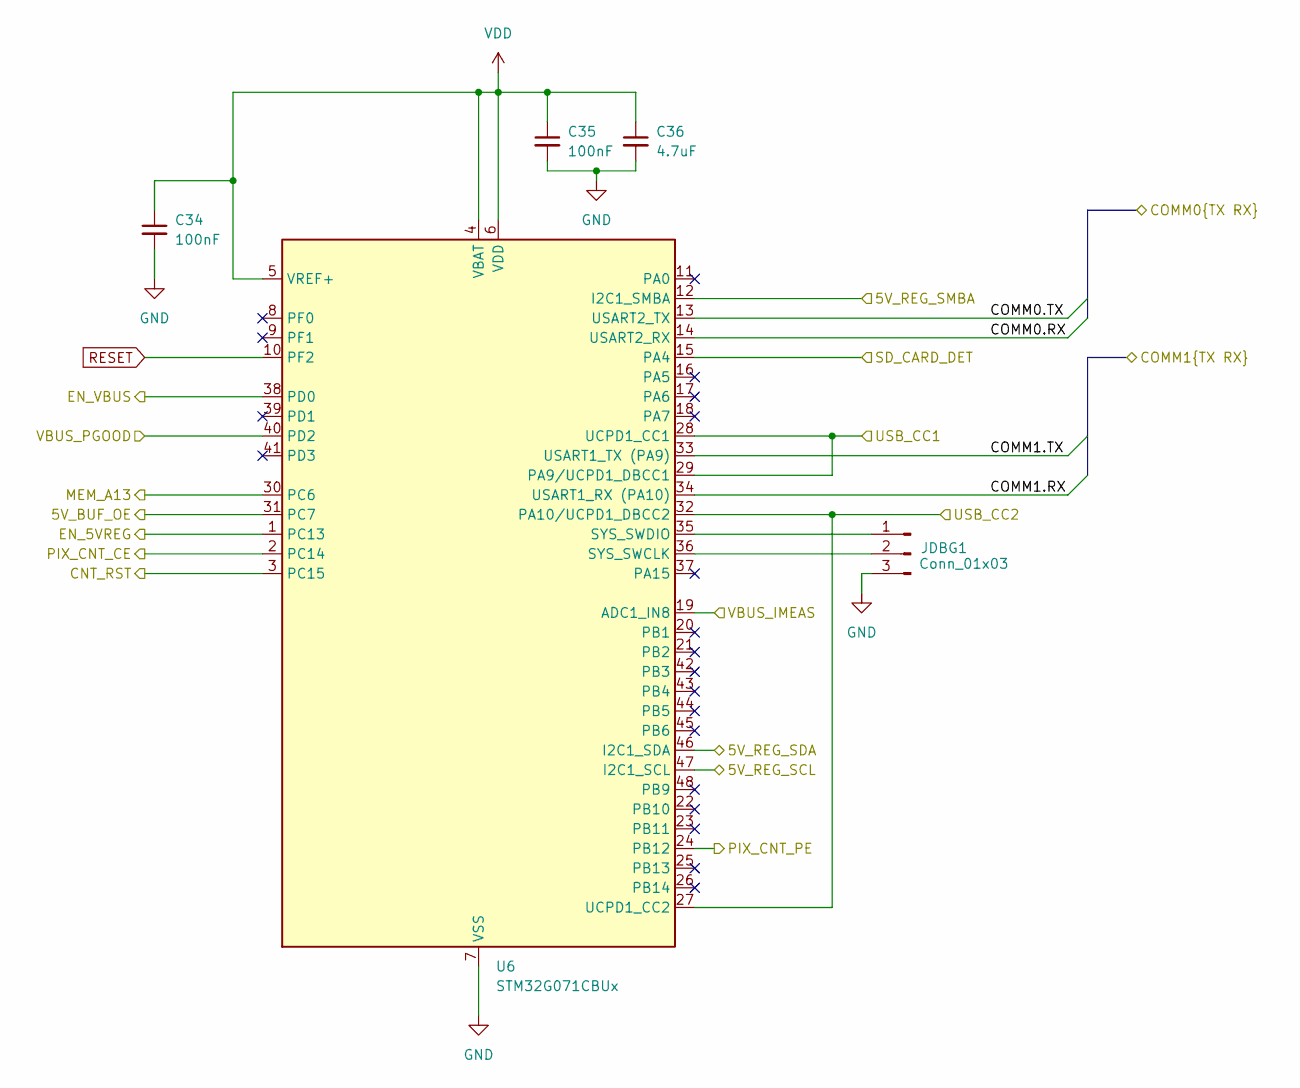
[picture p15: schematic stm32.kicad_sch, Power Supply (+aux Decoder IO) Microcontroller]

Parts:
C34, C35: 100nF; C_0402_1005Metric; Part CL05B104KB54PNC; LCSC C307331
C36: 4.7uF; C_1206_3216Metric; Part 1206B475K500NT; LCSC C29823
JDBG1: Conn_01x03; PinHeader_1x03_P2.54mm_Vertical
U6: STM32G071CBUx; QFN-48-1EP_7x7mm_P0.5mm_EP5.6x5.6mm; Part STM32G071CBU6; LCSC C529343

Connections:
/Decoder/CNT_RST: U6.3 (PC15); also elsewhere on the board
/Decoder/MEM_A13: U6.30 (PC6); also elsewhere on the board
/Decoder/PANEL_RGB_OE: U6.31 (PC7); also elsewhere on the board
/Decoder/PIX_CNT_CE: U6.2 (PC14); also elsewhere on the board
/Decoder/PIX_CNT_PE: U6.24 (PB12); also elsewhere on the board
/Display MCU/DET: U6.15 (PA4); also elsewhere on the board
/Display MCU/PWR.RX: U6.14 (USART2_RX); also elsewhere on the board
/Display MCU/PWR.TX: U6.13 (USART2_TX); also elsewhere on the board
/Power MCU/5V_REG_SCL: U6.47 (I2C1_SCL); also elsewhere on the board
/Power MCU/5V_REG_SDA: U6.46 (I2C1_SDA); also elsewhere on the board
/Power MCU/5V_REG_SMBA: U6.12 (I2C1_SMBA); also elsewhere on the board
/Power MCU/COMM1.RX: U6.34 (USART1_RX (PA10)); also elsewhere on the board
/Power MCU/COMM1.TX: U6.33 (USART1_TX (PA9)); also elsewhere on the board
/Power MCU/EN_5VREG: U6.1 (PC13); also elsewhere on the board
/Power MCU/EN_VBUS: U6.38 (PD0); also elsewhere on the board
/Power MCU/USB_CC1: U6.28 (UCPD1_CC1), U6.29 (PA9/UCPD1_DBCC1); also elsewhere on the board
/Power MCU/USB_CC2: U6.27 (UCPD1_CC2), U6.32 (PA10/UCPD1_DBCC2); also elsewhere on the board
/Power MCU/VBUS_IMEAS: U6.19 (ADC1_IN8); also elsewhere on the board
/Power MCU/VBUS_PGOOD: U6.40 (PD2); also elsewhere on the board
GND: C34.2, C35.2, C36.2, JDBG1.3, U6.7 (VSS), U6.49 (VSS); also elsewhere on the board
unnamed: JDBG1.1, U6.35 (SYS_SWDIO)
unnamed: JDBG1.2, U6.36 (SYS_SWCLK)
RESET: U6.10 (PF2); also elsewhere on the board
VDD: C34.1, C35.1, C36.1, U6.4 (VBAT), U6.5 (VREF+), U6.6 (VDD); also elsewhere on the board

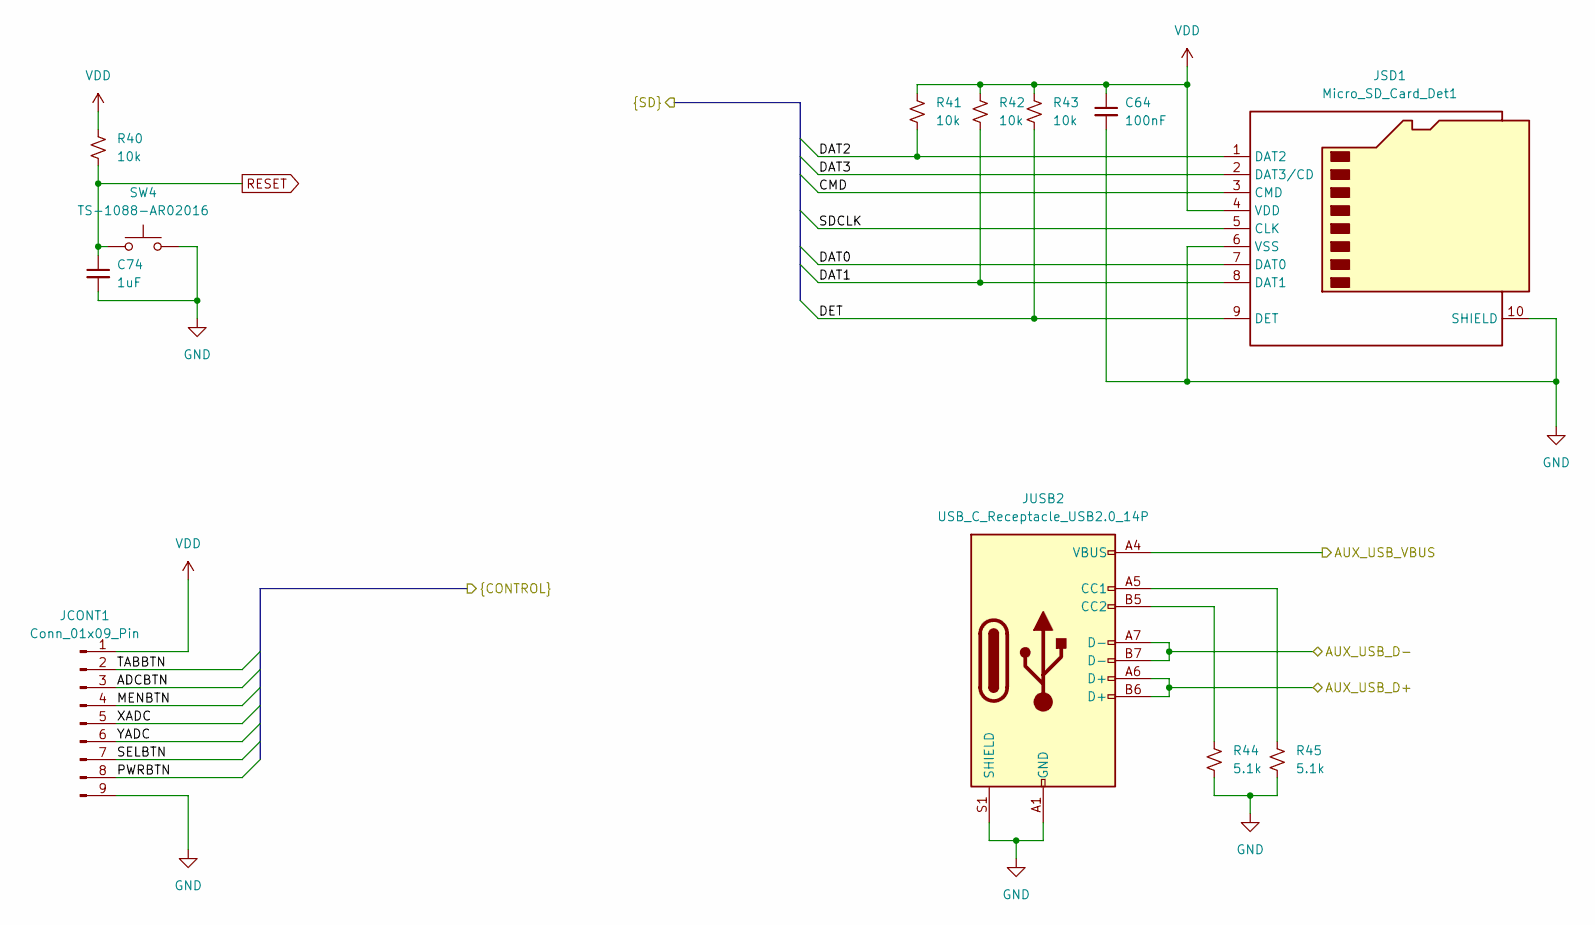
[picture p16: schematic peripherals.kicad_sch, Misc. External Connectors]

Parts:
C64: 100nF; C_0402_1005Metric; Part CL05B104KB54PNC; LCSC C307331
C74: 1uF; C_0603_1608Metric; Part CL10A105KB8NNNC; LCSC C15849
JCONT1: Conn_01x09_Pin; PinHeader_1x09_P2.54mm_Horizontal
JSD1: Micro_SD_Card_Det1; microSD_XUNPU_TF-115-BCP9; Part TF-115-BCP9; LCSC C720505
JUSB2: USB_C_Receptacle_USB2.0_14P; USB_C_Receptacle_HRO_TYPE-C-31-M-12; Part TYPE-C-31-M-12; LCSC C165948
R40, R41, R42, R43: 10k; R_0805_2012Metric; Part 0805W8F1002T5E; LCSC C17414
R44, R45: 5.1k; R_0603_1608Metric; Part 0603WAF5101T5E; LCSC C23186
SW4: TS-1088-AR02016; SW_SPST_TS-1088-xR020; Part TS-1088-AR02016; LCSC C720477

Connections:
/Display MCU/CMD: JSD1.3 (CMD); also elsewhere on the board
/Display MCU/DAT0: JSD1.7 (DAT0); also elsewhere on the board
/Display MCU/DAT1: JSD1.8 (DAT1), R42.2
/Display MCU/DAT2: JSD1.1 (DAT2), R41.2
/Display MCU/DAT3: JSD1.2 (DAT3/CD); also elsewhere on the board
/Display MCU/DET: JSD1.9 (DET), R43.2; also elsewhere on the board
/Display MCU/SDCLK: JSD1.5 (CLK); also elsewhere on the board
/Peripherals/ADCBTN: JCONT1.3; also elsewhere on the board
/Peripherals/AUX_USB_D+: JUSB2.A6 (D+), JUSB2.B6 (D+); also elsewhere on the board
/Peripherals/AUX_USB_D-: JUSB2.A7 (D-), JUSB2.B7 (D-); also elsewhere on the board
/Peripherals/AUX_USB_VBUS: JUSB2.A4 (VBUS), JUSB2.A9 (VBUS), JUSB2.B4 (VBUS), JUSB2.B9 (VBUS); also elsewhere on the board
/Peripherals/MENBTN: JCONT1.4; also elsewhere on the board
/Peripherals/PWRBTN: JCONT1.8; also elsewhere on the board
/Peripherals/SELBTN: JCONT1.7; also elsewhere on the board
/Peripherals/TABBTN: JCONT1.2; also elsewhere on the board
/Peripherals/XADC: JCONT1.5; also elsewhere on the board
/Peripherals/YADC: JCONT1.6; also elsewhere on the board
GND: C64.2, C74.2, JCONT1.9, JSD1.6 (VSS), JSD1.10 (SHIELD), JUSB2.A1 (GND), JUSB2.A12 (GND), JUSB2.B1 (GND), JUSB2.B12 (GND), JUSB2.S1 (SHIELD), R44.2, R45.2, SW4.2; also elsewhere on the board
unnamed: JUSB2.A5 (CC1), R45.1
unnamed: JUSB2.B5 (CC2), R44.1
RESET: C74.1, R40.2, SW4.1; also elsewhere on the board
VDD: C64.1, JCONT1.1, JSD1.4 (VDD), R40.1, R41.1, R42.1, R43.1; also elsewhere on the board

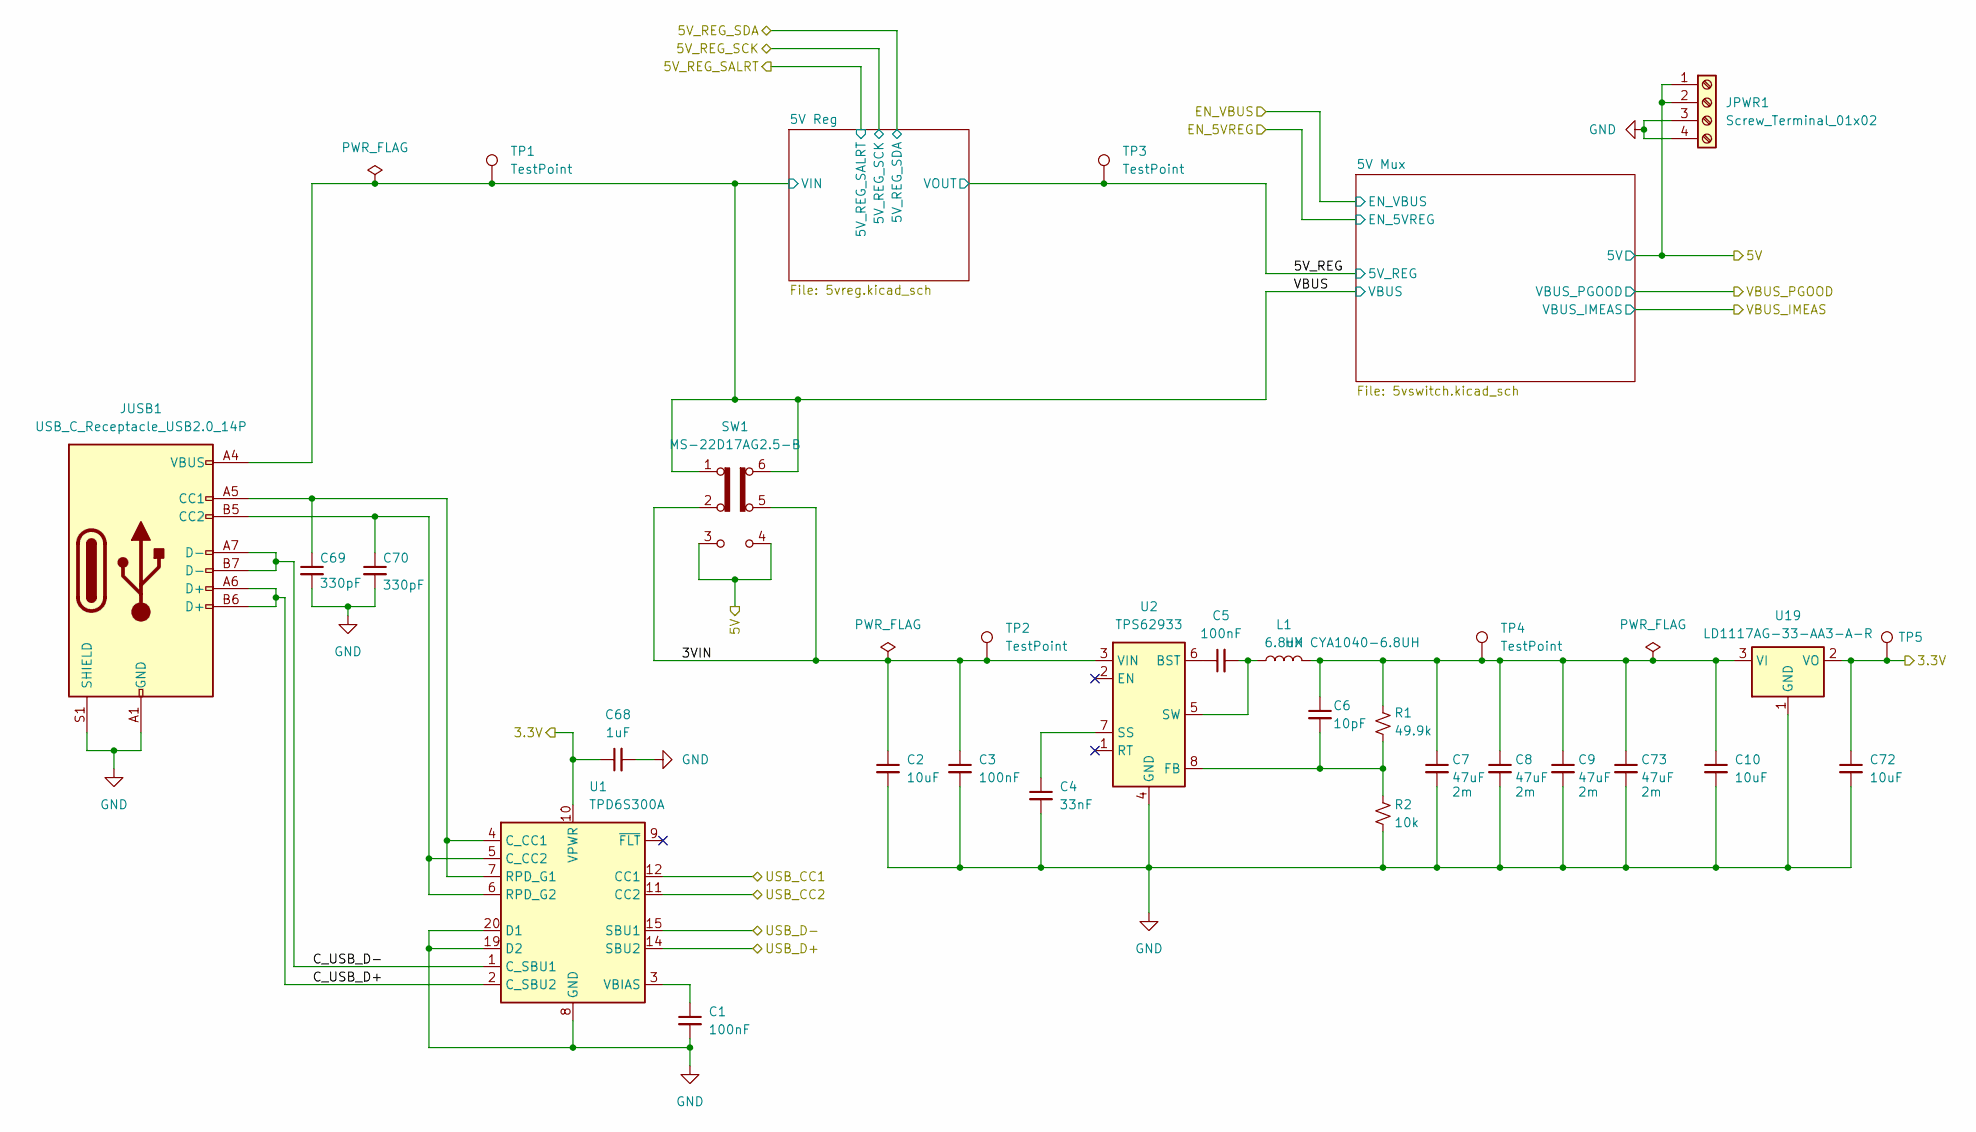
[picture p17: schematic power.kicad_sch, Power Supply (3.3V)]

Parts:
C1, C3, C5: 100nF; C_0402_1005Metric; Part CL05B104KB54PNC; LCSC C307331
C2, C10, C72: 10uF; C_1206_3216Metric; Part CL31A106KBHNNNE; LCSC C13585
C4: 33nF; C_0603_1608Metric; Part CL10B333KB8NNNC; LCSC C21117
C6: 10pF; C_0402_1005Metric; Part CL05C100JB5NNNC; LCSC C32949
C7, C8, C9, C73: 47uF; C_1206_3216Metric; Part CL31A476MPHNNNE; LCSC C96123
C68: 1uF; C_0603_1608Metric; Part CL10A105KB8NNNC; LCSC C15849
C69, C70: 330pF; C_0603_1608Metric; Part CL10C331JB8NNNC; LCSC C1664
JPWR1: Screw_Terminal_01x02; CONN-TH_4P-P9.50_WJHB9500M-9.5-04P-13-00A
JUSB1: USB_C_Receptacle_USB2.0_14P; USB_C_Receptacle_HRO_TYPE-C-31-M-12; Part TYPE-C-31-M-12; LCSC C165948
L1: 6.8uH; L_Chilisin_BMRF00101040; Part HX CYA1040-6.8UH; LCSC C7502775
R1: 49.9k; R_0603_1608Metric; Part 0603WAF4992T5E; LCSC C23184
R2: 10k; R_0402_1005Metric; Part 0402WGF1002TCE; LCSC C25744
SW1: MS-22D17AG2.5-B; SW-SMD_MS-22D17AG2.5; Part MS-22D17AG2.5-B; LCSC C20611671
TP1, TP2, TP3, TP4, TP5: TestPoint; TestPoint_Pad_D1.0mm
U1: TPD6S300A; WQFN-20-1EP_3x3mm_P0.4mm_EP1.7x1.7mm_ThermalVias; Part TPD6S300ARUKR; LCSC C2876380
U2: TPS62933; SOT-583-8; Part TPS62933DRLR; LCSC C3200405
U19: LD1117AG-33-AA3-A-R; SOT-223-3_TabPin2; LCSC C71121

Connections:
+5V: JPWR1.1, JPWR1.2, SW1.3 (C), SW1.4 (A); also elsewhere on the board
/Power MCU/USB_CC1: U1.12 (CC1); also elsewhere on the board
/Power MCU/USB_CC2: U1.11 (CC2); also elsewhere on the board
/Power/3VIN: C2.1, C3.1, SW1.2 (B), SW1.5 (B), TP2.1 (1_1), U2.3 (VIN)
/Power/5V_REG: TP3.1 (1_1); also elsewhere on the board
/Power/C_USB_D+: JUSB1.A6 (D+), JUSB1.B6 (D+), U1.2 (C_SBU2)
/Power/C_USB_D-: JUSB1.A7 (D-), JUSB1.B7 (D-), U1.1 (C_SBU1)
/Power/USB_D+: U1.14 (SBU2); also elsewhere on the board
/Power/USB_D-: U1.15 (SBU1); also elsewhere on the board
/Power/VBUS: JUSB1.A4 (VBUS), JUSB1.A9 (VBUS), JUSB1.B4 (VBUS), JUSB1.B9 (VBUS), SW1.1 (A), SW1.6 (C), TP1.1 (1_1); also elsewhere on the board
GND: C1.2, C2.2, C3.2, C4.2, C7.2, C8.2, C9.2, C10.2, C68.2, C69.2, C70.2, C72.2, C73.2, JPWR1.3, JPWR1.4, JUSB1.A1 (GND), JUSB1.A12 (GND), JUSB1.B1 (GND), JUSB1.B12 (GND), JUSB1.S1 (SHIELD), R2.2, U1.8 (GND), U1.13 (GND), U1.16 (GND), U1.17 (GND), U1.18 (GND), U1.19 (D2), U1.20 (D1), U1.21 (GND), U2.4 (GND), U19.1 (GND); also elsewhere on the board
unnamed: C69.1, JUSB1.A5 (CC1), U1.4 (C_CC1), U1.7 (RPD_G1)
unnamed: C70.1, JUSB1.B5 (CC2), U1.5 (C_CC2), U1.6 (RPD_G2)
unnamed: C1.1, U1.3 (VBIAS)
unnamed: C5.1, U2.6 (BST)
unnamed: C6.2, R1.2, R2.1, U2.8 (FB)
unnamed: C4.1, U2.7 (SS)
unnamed: C5.2, L1.1, U2.5 (SW)
unnamed: C6.1, C7.1, C8.1, C9.1, C10.1, C73.1, L1.2, R1.1, TP4.1 (1_1), U19.3 (VI)
VDD: C68.1, C72.1, TP5.1 (1_1), U1.10 (VPWR), U19.2 (VO); also elsewhere on the board

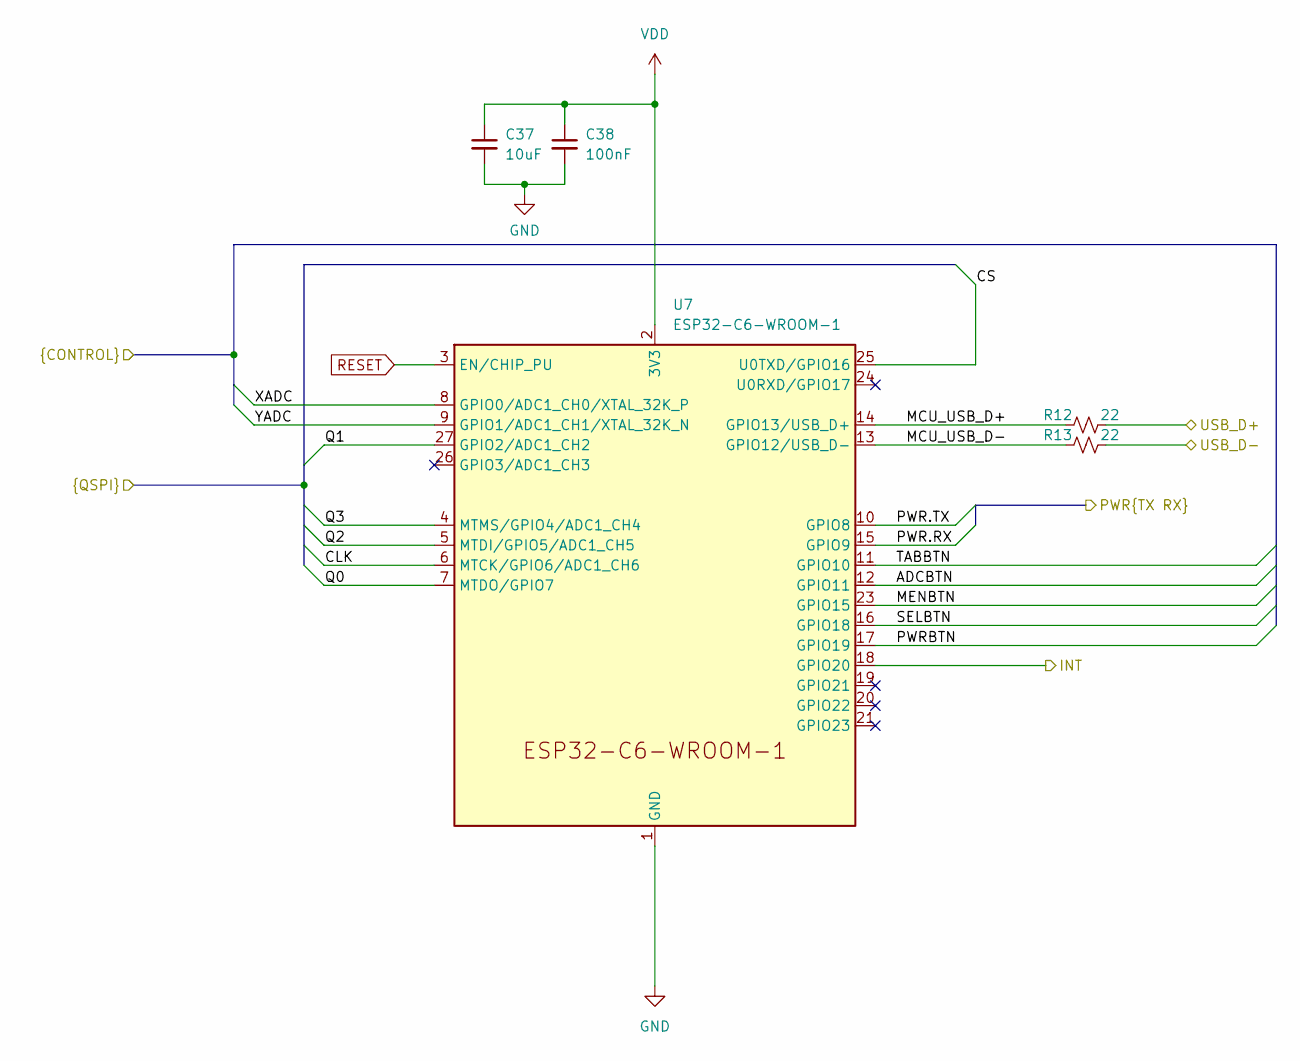
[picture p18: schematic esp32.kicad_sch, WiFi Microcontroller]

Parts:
C37: 10uF; C_1206_3216Metric; Part CL31A106KBHNNNE; LCSC C13585
C38: 100nF; C_0402_1005Metric; Part CL05B104KB54PNC; LCSC C307331
R12, R13: 22; R_0402_1005Metric; Part 0402WGF220JTCE; LCSC C25092
U7: ESP32-C6-WROOM-1; Part ESP32-C6-WROOM-1-N8; LCSC C5366877

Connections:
/Display MCU/CLK: U7.6 (MTCK/GPIO6/ADC1_CH6); also elsewhere on the board
/Display MCU/CS: U7.25 (U0TXD/GPIO16); also elsewhere on the board
/Display MCU/ESP_INT: U7.18 (GPIO20); also elsewhere on the board
/Display MCU/Q0: U7.7 (MTDO/GPIO7); also elsewhere on the board
/Display MCU/Q1: U7.27 (GPIO2/ADC1_CH2); also elsewhere on the board
/Display MCU/Q2: U7.5 (MTDI/GPIO5/ADC1_CH5); also elsewhere on the board
/Display MCU/Q3: U7.4 (MTMS/GPIO4/ADC1_CH4); also elsewhere on the board
/Peripherals/ADCBTN: U7.12 (GPIO11); also elsewhere on the board
/Peripherals/MENBTN: U7.23 (GPIO15); also elsewhere on the board
/Peripherals/PWRBTN: U7.17 (GPIO19); also elsewhere on the board
/Peripherals/SELBTN: U7.16 (GPIO18); also elsewhere on the board
/Peripherals/TABBTN: U7.11 (GPIO10); also elsewhere on the board
/Peripherals/XADC: U7.8 (GPIO0/ADC1_CH0/XTAL_32K_P); also elsewhere on the board
/Peripherals/YADC: U7.9 (GPIO1/ADC1_CH1/XTAL_32K_N); also elsewhere on the board
/Power MCU/COMM1.RX: U7.15 (GPIO9); also elsewhere on the board
/Power MCU/COMM1.TX: U7.10 (GPIO8); also elsewhere on the board
/USB Mux/ESP_D+: R12.2; also elsewhere on the board
/USB Mux/ESP_D-: R13.2; also elsewhere on the board
/WiFi MCU/MCU_USB_D+: R12.1, U7.14 (GPIO13/USB_D+)
/WiFi MCU/MCU_USB_D-: R13.1, U7.13 (GPIO12/USB_D-)
GND: C37.2, C38.2, U7.1 (GND), U7.28 (GND), U7.29 (GND); also elsewhere on the board
RESET: U7.3 (EN/CHIP_PU); also elsewhere on the board
VDD: C37.1, C38.1, U7.2 (3V3); also elsewhere on the board

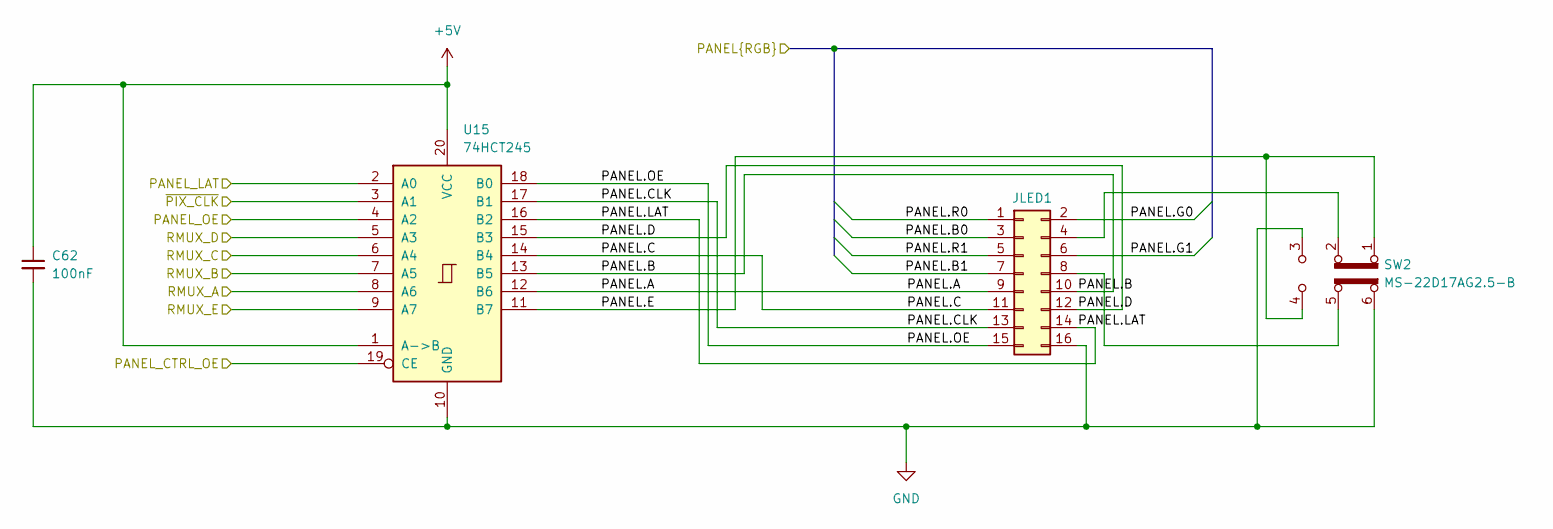
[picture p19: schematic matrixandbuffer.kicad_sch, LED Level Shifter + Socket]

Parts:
C62: 100nF; C_0402_1005Metric; Part CL05B104KB54PNC; LCSC C307331
JLED1: Conn_02x08_Counter_Clockwise; IDC-Header_2x08_P2.54mm_Vertical
SW2: MS-22D17AG2.5-B; SW-SMD_MS-22D17AG2.5; Part MS-22D17AG2.5-B; LCSC C20611671
U15: 74HCT245; TSSOP-20_4.4x6.5mm_P0.65mm; Part 74HCT245PW,118; LCSC C5980

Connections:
+5V: C62.1, U15.1 (A->B), U15.20 (VCC); also elsewhere on the board
/Decoder/PANELA.B0: JLED1.3; also elsewhere on the board
/Decoder/PANELA.B1: JLED1.7; also elsewhere on the board
/Decoder/PANELA.G0: JLED1.2; also elsewhere on the board
/Decoder/PANELA.G1: JLED1.6; also elsewhere on the board
/Decoder/PANELA.R0: JLED1.1; also elsewhere on the board
/Decoder/PANELA.R1: JLED1.5; also elsewhere on the board
/Decoder/PANEL_RGB_OE: U15.19 (CE); also elsewhere on the board
/Display MCU/PANEL_LAT: U15.2 (A0); also elsewhere on the board
/Display MCU/PANEL_OE: U15.4 (A2); also elsewhere on the board
/Display MCU/RMUX_A: U15.8 (A6); also elsewhere on the board
/Display MCU/RMUX_B: U15.7 (A5); also elsewhere on the board
/Display MCU/RMUX_C: U15.6 (A4); also elsewhere on the board
/Display MCU/RMUX_D: U15.5 (A3); also elsewhere on the board
/Display MCU/RMUX_E: U15.9 (A7); also elsewhere on the board
/Display MCU/~PIX_CLK: U15.3 (A1); also elsewhere on the board
/LED Connection A/PANEL.A: JLED1.9, U15.12 (B6)
/LED Connection A/PANEL.B: JLED1.10, U15.13 (B5)
/LED Connection A/PANEL.C: JLED1.11, U15.14 (B4)
/LED Connection A/PANEL.CLK: JLED1.13, U15.17 (B1)
/LED Connection A/PANEL.D: JLED1.12, U15.15 (B3)
/LED Connection A/PANEL.E: SW2.1 (A), SW2.4 (A), U15.11 (B7)
/LED Connection A/PANEL.LAT: JLED1.14, U15.16 (B2)
/LED Connection A/PANEL.OE: JLED1.15, U15.18 (B0)
GND: C62.2, JLED1.16, SW2.3 (C), SW2.6 (C), U15.10 (GND); also elsewhere on the board
unnamed: JLED1.4, SW2.2 (B)
unnamed: JLED1.8, SW2.5 (B)

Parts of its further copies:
C63: 100nF; C_0402_1005Metric; Part CL05B104KB54PNC; LCSC C307331
JLED2: Conn_02x08_Counter_Clockwise; IDC-Header_2x08_P2.54mm_Vertical
U16: 74HCT245; TSSOP-20_4.4x6.5mm_P0.65mm; Part 74HCT245PW,118; LCSC C5980

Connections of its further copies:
+5V: C63.1, U16.1 (A->B), U16.20 (VCC); also elsewhere on the board
/Decoder/PANELB.B0: JLED2.3; also elsewhere on the board
/Decoder/PANELB.B1: JLED2.7; also elsewhere on the board
/Decoder/PANELB.G0: JLED2.2; also elsewhere on the board
/Decoder/PANELB.G1: JLED2.6; also elsewhere on the board
/Decoder/PANELB.R0: JLED2.1; also elsewhere on the board
/Decoder/PANELB.R1: JLED2.5; also elsewhere on the board
/Decoder/PANEL_RGB_OE: U16.19 (CE); also elsewhere on the board
/Display MCU/PANEL_LAT: U16.2 (A0); also elsewhere on the board
/Display MCU/PANEL_OE: U16.4 (A2); also elsewhere on the board
/Display MCU/RMUX_A: U16.8 (A6); also elsewhere on the board
/Display MCU/RMUX_B: U16.7 (A5); also elsewhere on the board
/Display MCU/RMUX_C: U16.6 (A4); also elsewhere on the board
/Display MCU/RMUX_D: U16.5 (A3); also elsewhere on the board
/Display MCU/RMUX_E: U16.9 (A7); also elsewhere on the board
/Display MCU/~PIX_CLK: U16.3 (A1); also elsewhere on the board
/LED Connection B/PANEL.A: JLED2.9, U16.12 (B6)
/LED Connection B/PANEL.B: JLED2.10, U16.13 (B5)
/LED Connection B/PANEL.C: JLED2.11, U16.14 (B4)
/LED Connection B/PANEL.CLK: JLED2.13, U16.17 (B1)
/LED Connection B/PANEL.D: JLED2.12, U16.15 (B3)
/LED Connection B/PANEL.E: U16.11 (B7); also elsewhere on the board
/LED Connection B/PANEL.LAT: JLED2.14, U16.16 (B2)
/LED Connection B/PANEL.OE: JLED2.15, U16.18 (B0)
GND: C63.2, JLED2.16, U16.10 (GND); also elsewhere on the board
unnamed 137: JLED2.4; also elsewhere on the board
unnamed 138: JLED2.8; also elsewhere on the board

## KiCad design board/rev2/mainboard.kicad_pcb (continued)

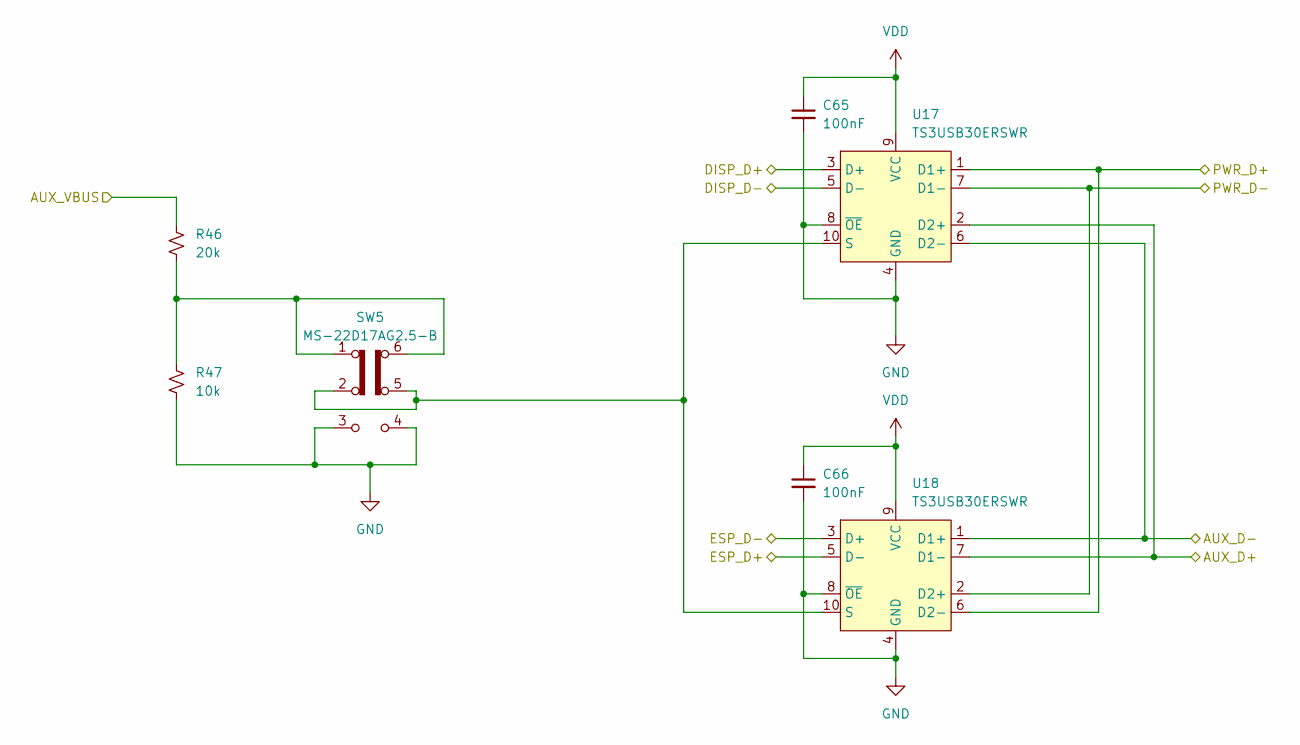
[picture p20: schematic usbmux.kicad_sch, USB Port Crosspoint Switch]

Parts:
C65, C66: 100nF; C_0402_1005Metric; Part CL05B104KB54PNC; LCSC C307331
R46: 20k; R_0603_1608Metric; Part 0603WAF2002T5E; LCSC C4184
R47: 10k; R_0805_2012Metric; Part 0805W8F1002T5E; LCSC C17414
SW5: MS-22D17AG2.5-B; SW-SMD_MS-22D17AG2.5; Part MS-22D17AG2.5-B; LCSC C20611671
U17, U18: TS3USB30ERSWR; UQFN-10_1.4x1.8mm_P0.4mm; Part TS3USB30ERSWR; LCSC C73880

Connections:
/Display MCU/USB_D+: U17.3 (D+); also elsewhere on the board
/Display MCU/USB_D-: U17.5 (D-); also elsewhere on the board
/Peripherals/AUX_USB_D+: U17.2 (D2+), U18.7 (D1-); also elsewhere on the board
/Peripherals/AUX_USB_D-: U17.6 (D2-), U18.1 (D1+); also elsewhere on the board
/Peripherals/AUX_USB_VBUS: R46.1; also elsewhere on the board
/Power/USB_D+: U17.1 (D1+), U18.6 (D2-); also elsewhere on the board
/Power/USB_D-: U17.7 (D1-), U18.2 (D2+); also elsewhere on the board
/USB Mux/ESP_D+: U18.5 (D-); also elsewhere on the board
/USB Mux/ESP_D-: U18.3 (D+); also elsewhere on the board
GND: C65.2, C66.2, R47.2, SW5.3 (C), SW5.4 (A), U17.4 (GND), U17.8 (~OE), U18.4 (GND), U18.8 (~OE); also elsewhere on the board
unnamed: R46.2, R47.1, SW5.1 (A), SW5.6 (C)
unnamed: SW5.2 (B), SW5.5 (B), U17.10 (S), U18.10 (S)
VDD: C65.1, C66.1, U17.9 (VCC), U18.9 (VCC); also elsewhere on the board

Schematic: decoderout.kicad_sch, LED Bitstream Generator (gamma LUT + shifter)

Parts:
C58, C59: 100nF; C_0402_1005Metric; Part CL05B104KB54PNC; LCSC C307331
R17, R24, R25, R26, R27, R28, R29, R30: 1k; R_0402_1005Metric; Part 0402WGF1001TCE; LCSC C11702
U11: IS61LV256AL; TSOP-28_L11.8-W8.0-P0.55-LS13.4-L; Part IS61LV256AL-10TLI; LCSC C412837
U12: 74AHCT595; TSSOP-16_4.4x5mm_P0.65mm; Part 74AHCT595T16-13; LCSC C460504

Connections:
+5V: C59.1, U12.10 (~SRCLR), U12.16 (VCC); also elsewhere on the board
/Decoder/MEMA_WE: U11.27 (~WE); also elsewhere on the board
/Decoder/MEM_A13: U11.21 (A10); also elsewhere on the board
/Decoder/MEM_IO: R17.2; also elsewhere on the board
/Decoder/Output Stage A/PIX_CNT_Q0: U11.26 (A13); also elsewhere on the board
/Decoder/Output Stage A/PIX_CNT_Q1: U11.25 (A8); also elsewhere on the board
/Decoder/Output Stage A/PIX_CNT_Q2: U11.24 (A9); also elsewhere on the board
/Decoder/Output Stage A/PIX_CNT_Q3: U11.23 (A11); also elsewhere on the board
/Decoder/Output Stage A/PIX_RGB_Q0: U11.1 (A14); also elsewhere on the board
/Decoder/Output Stage A/PIX_RGB_Q1: U11.2 (A12); also elsewhere on the board
/Decoder/PANELA.B0: U12.2 (QC); also elsewhere on the board
/Decoder/PANELA.B1: U12.5 (QF); also elsewhere on the board
/Decoder/PANELA.G0: U12.1 (QB); also elsewhere on the board
/Decoder/PANELA.G1: U12.4 (QE); also elsewhere on the board
/Decoder/PANELA.R0: U12.15 (QA); also elsewhere on the board
/Decoder/PANELA.R1: U12.3 (QD); also elsewhere on the board
/Decoder/PANEL_RGB_OE: U12.13 (~OE); also elsewhere on the board
/Decoder/PIX_CLK: U12.12 (RCLK); also elsewhere on the board
/Decoder/PIX_MEM_PA0: U11.10 (A0); also elsewhere on the board
/Decoder/PIX_MEM_PA1: U11.9 (A1); also elsewhere on the board
/Decoder/PIX_MEM_PA2: U11.8 (A2); also elsewhere on the board
/Decoder/PIX_MEM_PA3: U11.7 (A3); also elsewhere on the board
/Decoder/PIX_MEM_PA4: U11.6 (A4); also elsewhere on the board
/Decoder/PIX_MEM_PA5: U11.5 (A5); also elsewhere on the board
/Decoder/PIX_MEM_PA6: U11.4 (A6); also elsewhere on the board
/Decoder/PIX_MEM_PA7: U11.3 (A7); also elsewhere on the board
/Decoder/RGB_CLK: U12.11 (SRCLK); also elsewhere on the board
GND: C58.1, C59.2, R24.2, R25.2, R26.2, R27.2, R28.2, R29.2, R30.2, U11.14 (GND), U11.20 (~CE), U11.22 (~OE), U12.8 (GND); also elsewhere on the board
unnamed: R17.1, U11.11 (I/O0), U12.14 (SER)
unnamed: R24.1, U11.12 (I/O1)
unnamed: R25.1, U11.13 (I/O2)
unnamed: R26.1, U11.15 (I/O3)
unnamed: R27.1, U11.16 (I/O4)
unnamed: R28.1, U11.17 (I/O5)
unnamed: R29.1, U11.18 (I/O6)
unnamed: R30.1, U11.19 (I/O7)
VDD: C58.2, U11.28 (VDD); also elsewhere on the board

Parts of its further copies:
C60, C61: 100nF; C_0402_1005Metric; Part CL05B104KB54PNC; LCSC C307331
R32, R33, R34, R35, R36, R37, R38, R52: 1k; R_0402_1005Metric; Part 0402WGF1001TCE; LCSC C11702
U13: IS61LV256AL; TSOP-28_L11.8-W8.0-P0.55-LS13.4-L; Part IS61LV256AL-10TLI; LCSC C412837
U14: 74AHCT595; TSSOP-16_4.4x5mm_P0.65mm; Part 74AHCT595T16-13; LCSC C460504

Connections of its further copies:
+5V: C61.1, U14.10 (~SRCLR), U14.16 (VCC); also elsewhere on the board
/Decoder/MEMB_WE: U13.27 (~WE); also elsewhere on the board
/Decoder/MEM_A13: U13.21 (A10); also elsewhere on the board
/Decoder/MEM_IO: R52.2; also elsewhere on the board
/Decoder/Output Stage A/PIX_CNT_Q0: U13.26 (A13); also elsewhere on the board
/Decoder/Output Stage A/PIX_CNT_Q1: U13.25 (A8); also elsewhere on the board
/Decoder/Output Stage A/PIX_CNT_Q2: U13.24 (A9); also elsewhere on the board
/Decoder/Output Stage A/PIX_CNT_Q3: U13.23 (A11); also elsewhere on the board
/Decoder/Output Stage A/PIX_RGB_Q0: U13.1 (A14); also elsewhere on the board
/Decoder/Output Stage A/PIX_RGB_Q1: U13.2 (A12); also elsewhere on the board
/Decoder/PANELB.B0: U14.2 (QC); also elsewhere on the board
/Decoder/PANELB.B1: U14.5 (QF); also elsewhere on the board
/Decoder/PANELB.G0: U14.1 (QB); also elsewhere on the board
/Decoder/PANELB.G1: U14.4 (QE); also elsewhere on the board
/Decoder/PANELB.R0: U14.15 (QA); also elsewhere on the board
/Decoder/PANELB.R1: U14.3 (QD); also elsewhere on the board
/Decoder/PANEL_RGB_OE: U14.13 (~OE); also elsewhere on the board
/Decoder/PIX_CLK: U14.12 (RCLK); also elsewhere on the board
/Decoder/PIX_MEM_PB0: U13.10 (A0); also elsewhere on the board
/Decoder/PIX_MEM_PB1: U13.9 (A1); also elsewhere on the board
/Decoder/PIX_MEM_PB2: U13.8 (A2); also elsewhere on the board
/Decoder/PIX_MEM_PB3: U13.7 (A3); also elsewhere on the board
/Decoder/PIX_MEM_PB4: U13.6 (A4); also elsewhere on the board
/Decoder/PIX_MEM_PB5: U13.5 (A5); also elsewhere on the board
/Decoder/PIX_MEM_PB6: U13.4 (A6); also elsewhere on the board
/Decoder/PIX_MEM_PB7: U13.3 (A7); also elsewhere on the board
/Decoder/RGB_CLK: U14.11 (SRCLK); also elsewhere on the board
GND: C60.1, C61.2, R32.2, R33.2, R34.2, R35.2, R36.2, R37.2, R38.2, U13.14 (GND), U13.20 (~CE), U13.22 (~OE), U14.8 (GND); also elsewhere on the board
unnamed: R52.1, U13.11 (I/O0), U14.14 (SER)
unnamed: R32.1, U13.12 (I/O1)
unnamed: R33.1, U13.13 (I/O2)
unnamed: R34.1, U13.15 (I/O3)
unnamed: R35.1, U13.16 (I/O4)
unnamed: R36.1, U13.17 (I/O5)
unnamed: R37.1, U13.18 (I/O6)
unnamed: R38.1, U13.19 (I/O7)
VDD: C60.2, U13.28 (VDD); also elsewhere on the board

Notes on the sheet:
Gamma correction table (PIX_MEM)

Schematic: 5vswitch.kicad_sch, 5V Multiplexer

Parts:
C11: 1uF; C_0603_1608Metric; Part CL10A105KB8NNNC; LCSC C15849
C12, C15: 100nF; C_0402_1005Metric; Part CL05B104KB54PNC; LCSC C307331
C13: 2.2nF; C_0603_1608Metric; Part 0603B222K500NT; LCSC C1604
C14: 8.2nF; C_0603_1608Metric; Part 0603B822K500NT; LCSC C1322360
C16: 10uF; C_1206_3216Metric; Part CL31A106KBHNNNE; LCSC C13585
C17: 220uF; CP_Radial_D8.0mm_P3.50mm; Part ERS1VM221F12OT; LCSC C106697
Q1: WSD40120DN56G; DFN-8_L4.9-W6.0-P1.27-LS6.1-BL; Part WSD40120DN56G; LCSC C507088
R3: 10k; R_0402_1005Metric; Part 0402WGF1002TCE; LCSC C25744
R4: 100; R_1206_3216Metric; Part 1206W4F1000T5E; LCSC C17901
R5: 1.2k; R_0805_2012Metric; Part 0805W8F1201T5E; LCSC C17379
R6: 470k; R_0805_2012Metric; Part 0805W8F4703T5E; LCSC C17709
R7: 150k; R_0805_2012Metric; Part 0805W8F1503T5E; LCSC C17470
U3: TPS259472A; VQFN-10_L2.0-W2.0-P0.45-TL; Part TPS259472ARPWR; LCSC C3662789
U4: LM5050-1; TSOT-23-6; Part LM5050MKX-1/NOPB; LCSC C473393

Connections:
+5V: C16.1, C17.1, Q1.3 (D), R6.1, U3.6 (OUT), U4.6 (OUT); also elsewhere on the board
/Power MCU/EN_5VREG: U4.3 (OFF); also elsewhere on the board
/Power MCU/EN_VBUS: R3.1, U3.1 (EN_UVLO); also elsewhere on the board
/Power MCU/VBUS_IMEAS: R5.1, U3.9 (ILM); also elsewhere on the board
/Power MCU/VBUS_PGOOD: U3.3 (PG); also elsewhere on the board
/Power/5V_REG: Q1.1 (S), U4.4 (IN); also elsewhere on the board
/Power/VBUS: C11.1, C12.1, R4.1, U3.5 (IN); also elsewhere on the board
GND: C11.2, C12.2, C13.2, C14.2, C15.2, C16.2, C17.2, R3.2, R5.2, R7.2, U3.8 (GND), U4.2 (GND); also elsewhere on the board
unnamed: Q1.2 (G), U4.5 (GATE)
unnamed: C13.1, U3.10 (ITIMER)
unnamed: R6.2, R7.1, U3.4 (PGTH)
unnamed: C14.1, U3.7 (dVdt)
unnamed: C15.1, R4.2, U4.1 (VS)

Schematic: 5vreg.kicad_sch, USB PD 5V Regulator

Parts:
C18: 150uF; CP_Radial_D8.0mm_P3.50mm; Part ERS1VM151F12OT; LCSC C106696
C19, C20, C22: 4.7uF; C_1206_3216Metric; Part 1206B475K500NT; LCSC C29823
C21, C24, C25, C71: 100nF; C_0402_1005Metric; Part CL05B104KB54PNC; LCSC C307331
C23: 1uF; C_0603_1608Metric; Part CL10A105KB8NNNC; LCSC C15849
C26, C27, C28, C29, C30, C31, C32, C33: 47uF; C_1206_3216Metric; Part CL31A476MPHNNNE; LCSC C96123
L2: 1uH; L_Cenker_CKST1707; Part CKST1707-1uH/M; LCSC C5292052
NT1, NT2: NetTie_2; NetTie-2_SMD_Pad0.5mm
R8: 10k; R_0402_1005Metric; Part 0402WGF1002TCE; LCSC C25744
R9: 3.3k; R_0402_1005Metric; Part 0402WGF3301TCE; LCSC C25890
R10: 2.2; R_0603_1608Metric; Part 0603WAF220KT5E; LCSC C22939
TP7: TestPoint; TestPoint_Pad_D1.0mm
U5: SiC451; POWERPAK_MLP34-57_VIS; Part SIC451ED-T1-GE3; LCSC C1852144

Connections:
/Power MCU/5V_REG_SCL: U5.20 (SCL); also elsewhere on the board
/Power MCU/5V_REG_SDA: U5.19 (SDA); also elsewhere on the board
/Power MCU/5V_REG_SMBA: U5.18 (SALERT); also elsewhere on the board
/Power/5V Reg/VSEN+: NT1.1, U5.12 (VSEN+)
/Power/5V Reg/VSEN-: NT2.1, U5.11 (VSEN-)
/Power/5V_REG: C25.1, C26.1, C27.1, C28.1, C29.1, C30.1, C31.1, C32.1, C33.1, L2.2, NT1.2; also elsewhere on the board
/Power/VBUS: C18.1, C19.1, C20.1, C21.1, C71.1, U5.1 (PVIN), U5.23 (VIN); also elsewhere on the board
GND: C18.2, C19.2, C20.2, C21.2, C22.2, C23.2, C25.2, C26.2, C27.2, C28.2, C29.2, C30.2, C31.2, C32.2, C33.2, C71.2, NT2.2, R8.2, R9.2, TP7.1 (1_1), U5.7 (AGND), U5.15 (VSET), U5.21 (EN), U5.32 (PGND); also elsewhere on the board
unnamed: C24.2, R10.1
unnamed: R8.1, U5.14 (ADDR)
unnamed: R10.2, U5.6 (BOOT)
unnamed: C24.1, U5.4 (PHASE)
unnamed: C22.1, U5.24 (PVCC)
unnamed: R9.1, U5.17 (RT/SYNC)
unnamed: L2.1, U5.26 (SW)
unnamed: C23.1, U5.22 (VDD)

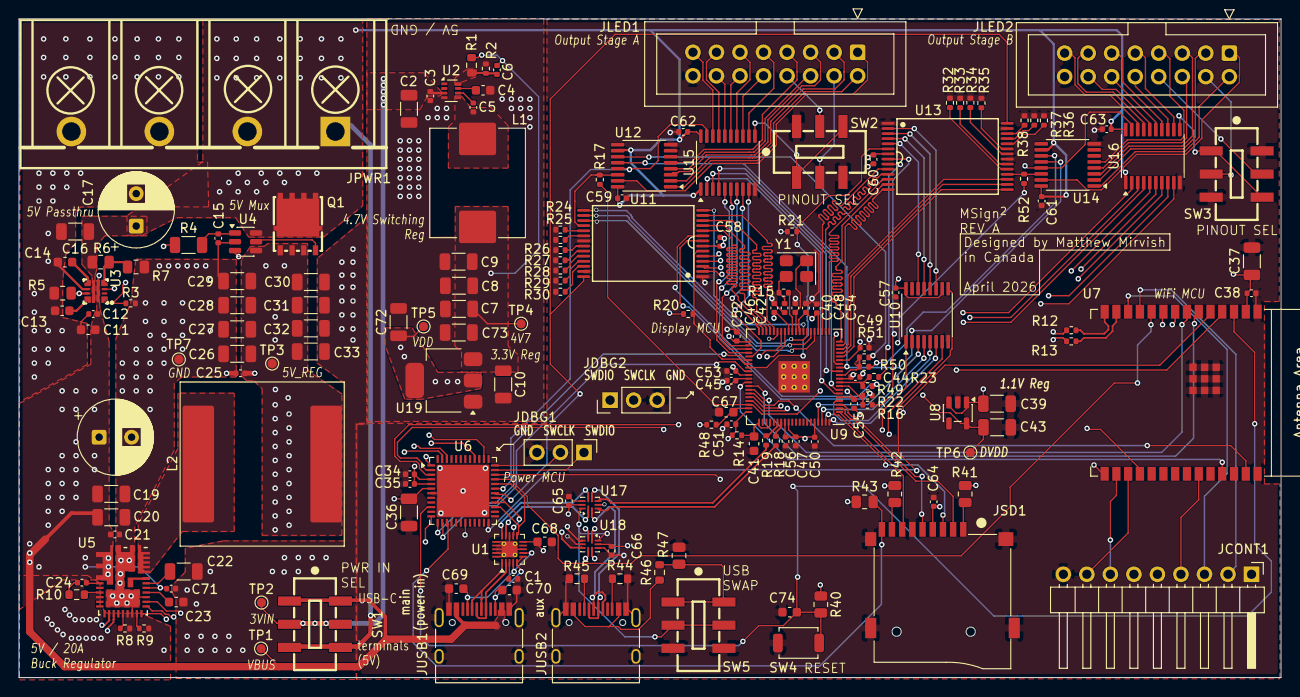
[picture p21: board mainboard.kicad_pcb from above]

Board: 4 copper layers, 136.2 x 71.1 mm, 169 parts (0 on the bottom side), 188 nets.

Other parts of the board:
SW3: MS-22D28-G020; SW-SMD_MS-22D17AG2.5

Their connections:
/LED Connection B/PANEL.E: SW3.1 (A), SW3.4 (A); also elsewhere on the board
GND: SW3.3 (C), SW3.6 (C); also elsewhere on the board
unnamed 137: SW3.2 (B); also elsewhere on the board
unnamed 138: SW3.5 (B); also elsewhere on the board

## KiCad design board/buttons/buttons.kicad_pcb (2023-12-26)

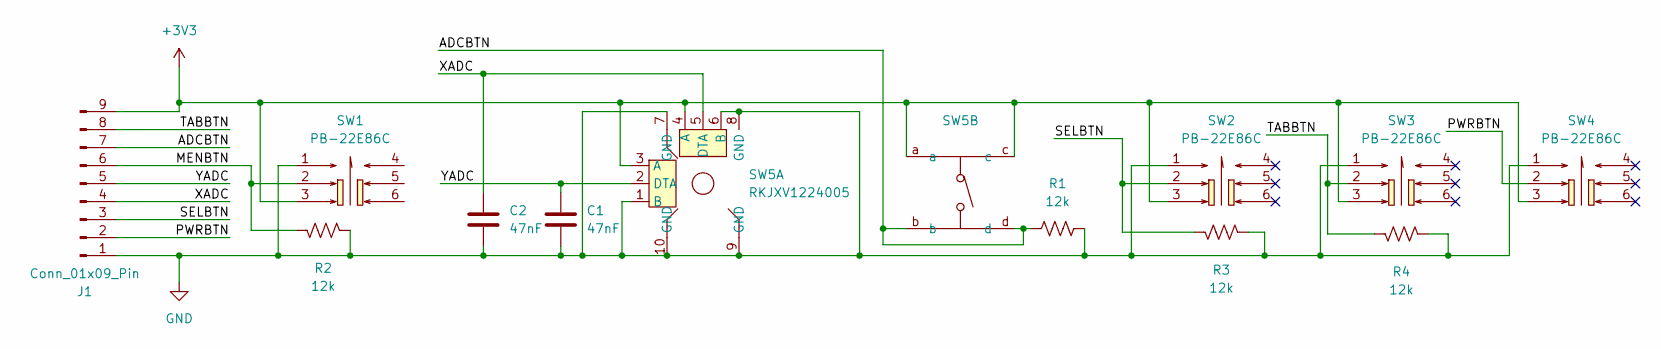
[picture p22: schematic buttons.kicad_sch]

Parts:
C1, C2: 47nF; C_0603_1608Metric; LCSC Part C1622
J1: Conn_01x09_Pin; PinHeader_1x09_P2.54mm_Horizontal
R1, R2, R3, R4: 12k; R_0402_1005Metric; LCSC Part C25752
SW1, SW2, SW3, SW4: PB-22E86C; SW-TH_6P-L8.45-W8.45-P2.50-LS5.5-BL; LCSC Part C2848957
SW5: RKJXV1224005; SW-TH_RKJXV1224005; LCSC Part C146170

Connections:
+3V3: J1.9, SW1.3, SW2.3, SW3.3, SW4.3, SW5.3 (A), SW5.4 (A), SW5.a, SW5.c
/ADCBTN: J1.7, R1.1, SW5.b, SW5.d
/MENBTN: J1.6, R2.2, SW1.2
/PWRBTN: J1.2, SW4.2
/SELBTN: J1.3, R3.2, SW2.2
/TABBTN: J1.8, R4.2, SW3.2
/XADC: C2.1, J1.4, SW5.5 (DTA)
/YADC: C1.1, J1.5, SW5.2 (DTA)
GND: C1.2, C2.2, J1.1, R1.2, R2.1, R3.1, R4.1, SW1.1, SW2.1, SW3.1, SW4.1, SW5.1 (B), SW5.6 (B), SW5.7 (GND), SW5.8 (GND), SW5.9 (GND), SW5.10 (GND)

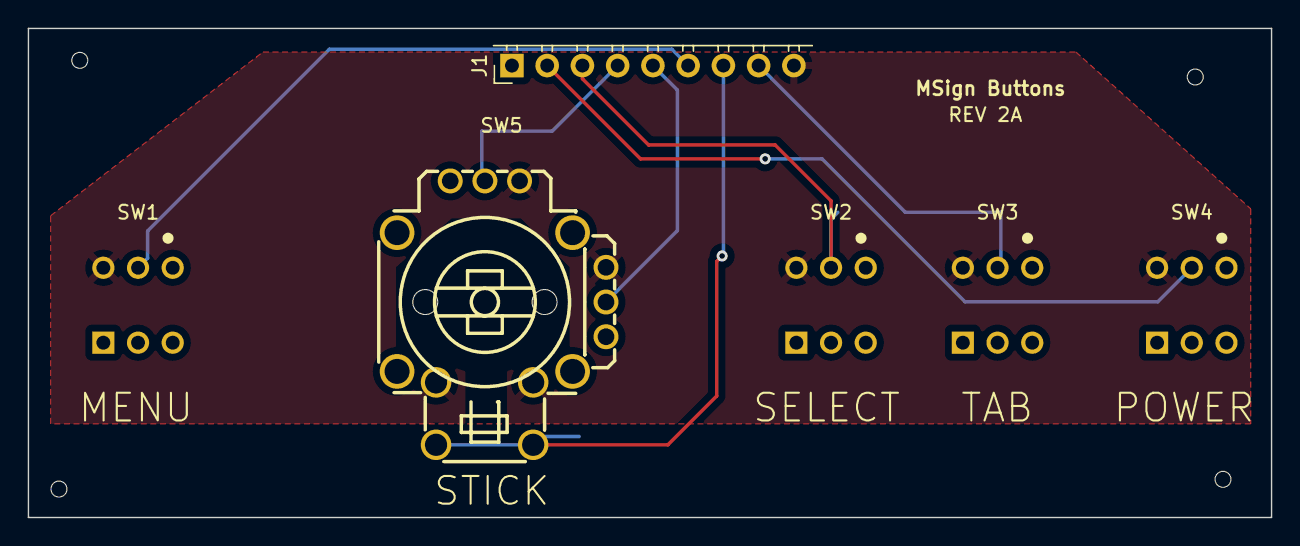
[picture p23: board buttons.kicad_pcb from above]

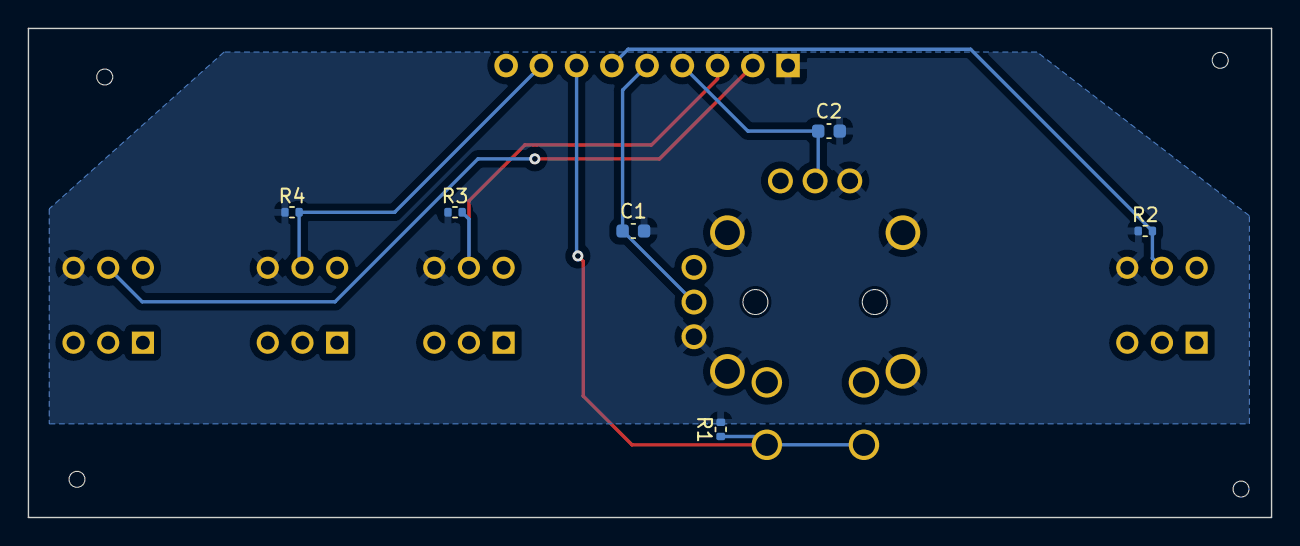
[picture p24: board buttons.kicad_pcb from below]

Board: 2 copper layers, 89.6 x 35.2 mm, 12 parts (6 on the bottom side), 9 nets.

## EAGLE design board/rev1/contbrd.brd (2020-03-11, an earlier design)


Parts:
C1, C4, C7: 100nF; C025-025X050
C2: 100uF; E2,5-6
C3: 1uF; C050-024X044
C5, C6: 2.2uF; E1,8-4
IC1: STM32F205RGT; LQFP64
IC5: ESP8266-12E/ESP-12E; XCVR_ESP8266-12E/ESP-12E
R1, R2, R3: 12k; 0204/7

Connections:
+3V3: C1.1, C2.+, C3.2, C4.2, C7.2, IC1.1 (VBAT), IC1.13 (VDDA), IC5.3 (EN), IC5.8 (VCC), R1.1, R2.1; also elsewhere on the board
A: IC1.26 (PB0); also elsewhere on the board
ACTLED: IC1.21 (PA5); also elsewhere on the board
B: IC1.27 (PB1); also elsewhere on the board
B0: IC1.10 (PC2); also elsewhere on the board
B1: IC1.25 (PC5); also elsewhere on the board
C: IC1.28 (PB2); also elsewhere on the board
D: IC1.55 (PB3); also elsewhere on the board
DCLK: IC1.37 (PC6); also elsewhere on the board
DEBUG_TX: IC5.17 (IO2), R2.2; also elsewhere on the board
ESP_PROG_RX: IC5.21 (RXD); also elsewhere on the board
ESP_PROG_TX: IC5.22 (TXD); also elsewhere on the board
FLASH: IC5.18 (IO0), R1.2; also elsewhere on the board
G0: IC1.9 (PC1); also elsewhere on the board
G1: IC1.24 (PC4); also elsewhere on the board
GND: C1.2, C2.-, C3.1, C4.1, C5.-, C6.-, C7.1, IC1.12 (VSSA), IC1.60 (BOOT0), IC5.15 (GND), R3.1; also elsewhere on the board
LAT: IC1.57 (PB5); also elsewhere on the board
MENBTN: IC1.23 (PA7); also elsewhere on the board
MISO: IC5.6 (IO12); also elsewhere on the board
MOSI: IC5.19 (IO4); also elsewhere on the board
unnamed: C5.+, IC1.31 (VCAP1)
unnamed: C6.+, IC1.47 (VCAP2)
NXTBTN: IC1.43 (PA10); also elsewhere on the board
OE: IC1.58 (PB6); also elsewhere on the board
PRVBTN: IC1.42 (PA9); also elsewhere on the board
PWRBTN: IC1.14 (PA0-WKUP); also elsewhere on the board
R0: IC1.8 (PC0); also elsewhere on the board
R1: IC1.11 (PC3); also elsewhere on the board
RESET: IC1.7 (NRST), IC5.1 (RESET); also elsewhere on the board
RX: IC1.17 (PA3), IC5.16 (IO15), R3.2
SCLK: IC5.5 (IO14); also elsewhere on the board
SDCS: IC5.20 (IO5); also elsewhere on the board
SELBTN: IC1.41 (PA8); also elsewhere on the board
SWCLK: IC1.49 (PA14); also elsewhere on the board
SWDIO: IC1.46 (PA13); also elsewhere on the board
TX: IC1.16 (PA2), IC5.7 (IO13)
UPDLED: IC1.22 (PA6); also elsewhere on the board

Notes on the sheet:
ESP
STM
MSign
STM32 and ESP8266
Reserved for extra display signals


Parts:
C8: 0.47uF; C050-024X044
C9: 10uF; C025-025X050
C10: 33uF; E2-5
C11, C12: 100nF; C025-025X050
C13: 470pF; C025-025X050
IC1: STM32F205RGT; LQFP64
IC2, IC3: 74HCT244DW; SO20W
IC4: LM3940; TO220
J1: DCJ0202
J2: CONN_025MM; SCREWTERMINAL-5MM-2
R4: 470; 0204/7
R5: 12k; 0204/7
S1, S2: 10-XX; B3F-10XX

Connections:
+3V3: C9.1, C10.+, C11.1, C12.1, IC1.19 (VDD), IC1.32 (VDD), IC1.48 (VDD), IC1.64 (VDD), IC4.3 (OUT), R5.2; also elsewhere on the board
+5V: C8.1, IC2.20 (VCC), IC3.20 (VCC), IC4.1 (IN), J1.1, J2.1
FLASH: R4.2; also elsewhere on the board
GND: C8.2, C9.2, C10.-, C11.2, C12.2, C13.2, IC1.18 (VSS), IC1.63 (VSS), IC2.10 (GND), IC3.10 (GND), IC4.2 (GND), J1.3, J2.2, S1.3, S1.4 (P1), S2.3, S2.4 (P1); also elsewhere on the board
unnamed: R4.1, S1.1 (S), S1.2 (S1)
RESET: C13.1, R5.1, S2.1 (S), S2.2 (S1); also elsewhere on the board

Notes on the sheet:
DISPLAY POWER
BARREL JACK
LOW ESR
STM POWER PINS
3V3 REGULATOR
BUTTONS
LL CONVERTER POWER
MSign
Power pins and on-board buttons


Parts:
C14: 100nF; C025-025X050
IC2, IC3: 74HCT244DW; SO20W
JP1: DM3AT-SF-PEJM5
JP2: PINHD-1X5; 1X05
JP3: PINHD-2X8; 2X08
JP4: PINHD-1X9; 1X09
JP5: PINHD-1X6; 1X06
R6: 470k; 0204/7
R7: 12k; 0204/7

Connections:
+3V3: C14.1, JP1.4 (VCC), JP2.1, JP4.1, JP5.1; also elsewhere on the board
A: IC3.11 (A1); also elsewhere on the board
ACTLED: JP4.3; also elsewhere on the board
A_H: IC3.9 (Y1), JP3.9
B: IC2.6 (A3); also elsewhere on the board
B0: IC3.4 (A2); also elsewhere on the board
B0_H: IC3.16 (Y2), JP3.3
B1: IC3.8 (A4); also elsewhere on the board
B1_H: IC3.12 (Y4), JP3.7
B_H: IC2.14 (Y3), JP3.10
C: IC3.13 (A2); also elsewhere on the board
C_H: IC3.7 (Y2), JP3.11
D: IC2.8 (A4); also elsewhere on the board
DCLK: IC3.15 (A3); also elsewhere on the board
DCLK_H: IC3.5 (Y3), JP3.13, R6.2
DEBUG_TX: JP2.5; also elsewhere on the board
D_H: IC2.12 (Y4), JP3.12
ESP_PROG_RX: JP2.3; also elsewhere on the board
ESP_PROG_TX: JP2.2; also elsewhere on the board
G0: IC2.2 (A1); also elsewhere on the board
G0_H: IC2.18 (Y1), JP3.2
G1: IC2.4 (A2); also elsewhere on the board
G1_H: IC2.16 (Y2), JP3.6
GND: C14.2, IC2.1 (G), IC2.19 (G), IC3.1 (G), IC3.19 (G), JP1.6 (GND), JP1.MOUNT0 (GND), JP1.MOUNT1 (GND), JP1.MOUNT2 (GND), JP1.MOUNT3 (GND), JP2.4, JP3.4, JP3.8, JP3.16, JP4.9, JP5.3, R6.1, R7.2; also elsewhere on the board
LAT: IC2.11 (A1); also elsewhere on the board
LAT_H: IC2.9 (Y1), JP3.14
MENBTN: JP4.4; also elsewhere on the board
MISO: JP1.7 (DATA0/MISO); also elsewhere on the board
MOSI: JP1.3 (CMD/MOSI); also elsewhere on the board
NXTBTN: JP4.6; also elsewhere on the board
OE: IC3.17 (A4); also elsewhere on the board
OE_H: IC3.3 (Y4), JP3.15
PRVBTN: JP4.5; also elsewhere on the board
PWRBTN: JP4.8, R7.1; also elsewhere on the board
R0: IC3.2 (A1); also elsewhere on the board
R0_H: IC3.18 (Y1), JP3.1
R1: IC3.6 (A3); also elsewhere on the board
R1_H: IC3.14 (Y3), JP3.5
RESET: JP5.5; also elsewhere on the board
SCLK: JP1.5 (CLK); also elsewhere on the board
SDCS: JP1.2 (DATA3-CD/CS_N); also elsewhere on the board
SELBTN: JP4.7; also elsewhere on the board
SWCLK: JP5.2; also elsewhere on the board
SWDIO: JP5.4; also elsewhere on the board
UPDLED: JP4.2; also elsewhere on the board

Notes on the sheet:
DISPLAY DATA CONNECTOR
MICROSD CARD
ESP PROGRAMMING HEADER
STM PROGRAMMING HEADER
MSign
External connectors and sockets
EXTERNAL BUTTONS


Board: 2 copper layers, 97.8 x 66.1 mm, 35 parts (0 on the bottom side), 52 nets.

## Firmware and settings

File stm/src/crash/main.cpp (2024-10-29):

#include "../matrix.h"
#include "decode.h"
#include "main.h"
#include "mindraw.h"
#include "rtos.h"
#include "simplematrix.h"
#include "../tskmem.h"
#include "../ui.h"
#include "srvd.h"
#include "../srv.h"
#include <alloca.h>
#include <stdio.h>

#ifdef USE_F2
#include <stm32f2xx_ll_cortex.h>
#include <stm32f2xx_ll_system.h>
#include <stm32f2xx_ll_utils.h>
#endif

#ifdef USE_F4
#include <stm32f4xx_ll_cortex.h>
#include <stm32f4xx_ll_system.h>
#include <stm32f4xx_ll_utils.h>
#endif

extern "C" {
	extern uint32_t _ecstack;
	extern uint8_t _svram;
	extern uint8_t _ecdata;
	extern uint8_t _scidata;
	extern uint8_t _ecbss;
	extern uint8_t _scdata;
	extern uint32_t g_pfnVectors_crash;
};

namespace crash {
	// Smaller matrix to give more space for our private data
	Matrix matrix;

	constexpr inline uint32_t page_delay = 5000;

	inline constexpr uint8_t mkcolor(uint8_t r, uint8_t g, uint8_t b) {
		return r | (g << 2) | (b << 4);
	}

	void delay_ms(uint32_t delay, bool cancellable=true) {
		volatile uint32_t dummyread = SysTick->CTRL;  // get rid of countflag

		int state = 0;

		while (delay)
		{
			if((SysTick->CTRL & SysTick_CTRL_COUNTFLAG_Msk) != 0)
			{
				if (state == 1) state = 2;
				--delay;
			}

			bool ispressed = (UI_BUTTON_PORT->IDR & (1 << ui::Buttons::POWER)) && cancellable;

			switch (state) {
				case 0: // waiting for pressed
					if (ispressed) state = 1;
					break;
				case 1:
					if (!ispressed) state = 0;
					break;
				case 2:
					if (!ispressed) return;
					break;
			}
		}
	}

	int y = 18;

	uint16_t print_line(const char* txt, uint8_t color, uint16_t indent, bool advance=true) {
		if (y > 64) {
			delay_ms(page_delay);
			draw::rect(matrix, 0, 12, 128, 64, 0);
			y = 18;
		}
		auto result = draw::text(matrix, txt, indent, y, color);
		if (advance) y += 6;
		return result;
	}

	void print_wrapped_lines(const char *txt, uint8_t color, uint16_t indent) {
		int remaining = strlen(txt), pos = 0;
		while (remaining > 0) {
			size_t printed = draw::break_line(txt + pos, indent);
			print_line(txt + pos, color, indent);
			pos += printed;
			remaining -= printed;
		}
	}

	void show_backtrace_for(const char * title, uint32_t SP, uint32_t PC, uint32_t LR) {
		// Create a backtrace
		uint32_t backtrace[32];
		uint16_t bt_len = 32;

		decode::fill_backtrace(backtrace, bt_len, PC, LR, SP);

		// Create function name list (ironically using VLA here breaks the backtracer, but whatever)
		char symbols[bt_len][decode::max_length_size];

		decode::resolve_symbols(symbols, backtrace, bt_len);

		// DRAW STACKTRACE
		print_line(title, mkcolor(1, 3, 1), 0);
		for (int i = 0; i < bt_len; ++i) {
			char buf[16];
			snprintf(buf, 16, "%d - ", i);
			uint16_t indent = print_line(buf, mkcolor(3, 2, 0), 0, false);
			snprintf(buf, 16, "0x%08x", backtrace[i]);
			print_line(buf, mkcolor(1, 1, 3), indent);
			print_wrapped_lines(symbols[i], mkcolor(3, 3, 3), indent);
		}

		y = 65; // force page end
	}

	void cmain(const char* errcode, uint32_t SP, uint32_t PC, uint32_t LR) {
		// Mask out all application interrupts
		__set_BASEPRI(2 << (8 - __NVIC_PRIO_BITS));
		// Unremap memory
		SYSCFG->MEMRMP = 0;
		// Change VTOR to our VTOR
		SCB->VTOR = (uint32_t)&g_pfnVectors_crash;
		// Try to exit an exception handler, if possible. (todo)
		
		// Check if sleep mode is enabled -- if so, just reset immediately.
		if (RTC->BKP4R) {
			NVIC_SystemReset();
			while (1) {;}
		}

		LL_DMA_DisableStream(DMA2, LL_DMA_STREAM_5);
		LL_TIM_DisableCounter(TIM1);
		LL_TIM_DisableCounter(TIM9);

		LL_FLASH_DisableDataCache();
		LL_FLASH_DisableInstCache();

		// Disable the matrix interrupts
		NVIC_DisableIRQ(DMA2_Stream5_IRQn);
		NVIC_DisableIRQ(TIM1_BRK_TIM9_IRQn);
		// Zero our BSS
		memset(&_svram, 0, &_ecbss - &_svram);
		// Load our constant data
		memcpy(&_scdata, &_scidata, &_ecdata - &_scdata);

		// Setup GPIO for power button
		
		LL_AHB1_GRP1_EnableClock(UI_BUTTON_PERIPH);

		LL_GPIO_InitTypeDef it{};

		it.Mode = LL_GPIO_MODE_INPUT;
		it.Pull = LL_GPIO_PULL_NO;
		it.Speed = LL_GPIO_SPEED_FREQ_LOW;
		it.Pin = (1 << ui::Buttons::POWER);

		LL_GPIO_Init(UI_BUTTON_PORT, &it); // setup to check for power button presses to advance through screens

		__DSB();
		__ISB();

		// Initialize our matrix
		matrix.init();

		// Setup systick
		LL_SYSTICK_DisableIT();
		LL_InitTick(F_CPU, 1000);

		// Turn on interrupts
		NVIC_SetPriority(DMA2_Stream5_IRQn, NVIC_EncodePriority(NVIC_GetPriorityGrouping(),1,0));
		NVIC_EnableIRQ(DMA2_Stream5_IRQn);

		NVIC_SetPriority(TIM1_BRK_TIM9_IRQn, NVIC_EncodePriority(NVIC_GetPriorityGrouping(),1,1)); // sequence after each other
		NVIC_EnableIRQ(TIM1_BRK_TIM9_IRQn);

		draw::text(matrix, "MSign crashed!", 0, 6, mkcolor(3, 0, 0));
		draw::text(matrix, errcode, 0, 12, mkcolor(3, 3, 3));

		if (PC == 0xffff'ffff) {
			matrix.start_display();
			goto reboot;
		}

		{
			// Start display again
			matrix.start_display();

			while (true) {
				show_backtrace_for("Traceback (recent calls first)", SP, PC, LR);
				print_line("=== CONTEXT ===", mkcolor(1, 3, 1), 0);

				// Are we in a fault handler?
				{
					uint8_t active_isr = __get_IPSR() & 0xff;
					if (active_isr) {
						// We are, check the CFSR bits
						switch (active_isr) {
							case 5:
								// bus fault
								{
									print_line("bus fault:", mkcolor(3, 0, 0), 1);
									if (SCB->CFSR & SCB_CFSR_STKERR_Msk) print_line("during exception stacking", mkcolor(1, 1, 1), 2);
									else if (SCB->CFSR & SCB_CFSR_UNSTKERR_Msk) print_line("during exception unstacking", mkcolor(1, 1, 1), 2);
									else if (SCB->CFSR & SCB_CFSR_IBUSERR_Msk) print_line("during inst fetch", mkcolor(1, 1, 1), 2);
									else if (SCB->CFSR & SCB_CFSR_PRECISERR_Msk || SCB->CFSR & SCB_CFSR_IMPRECISERR_Msk) print_line("during data fetch", mkcolor(1, 1, 1), 2);

									if (SCB->CFSR & SCB_CFSR_BFARVALID_Msk) {
										char buf[32];
										snprintf(buf, 32, "while accessing 0x%08x", SCB->BFAR);
										print_line(buf, mkcolor(1, 1, 3), 2);
									}
								}
								break;
							case 6:
								// usage fault
								{
									print_line("usage fault:", mkcolor(3, 0, 0), 1);
									if (SCB->CFSR & SCB_CFSR_NOCP_Msk) print_line("no coprocessor", mkcolor(1, 1, 1), 2);
									else if (SCB->CFSR & SCB_CFSR_UNDEFINSTR_Msk) print_line("undefined instruction", mkcolor(1, 1, 1), 2);
									else if (SCB->CFSR & SCB_CFSR_INVSTATE_Msk) print_line("invalid isa state", mkcolor(1, 1, 1), 2);
									else if (SCB->CFSR & SCB_CFSR_INVPC_Msk) print_line("invalid exception return", mkcolor(1, 1, 1), 2);
									else if (SCB->CFSR & SCB_CFSR_UNALIGNED_Msk) print_line("unaligned load/store", mkcolor(1, 1, 1), 2);
									else if (SCB->CFSR & SCB_CFSR_DIVBYZERO_Msk) print_line("divide by 0", mkcolor(1, 1, 1), 2);
									else print_line("unknown", mkcolor(3, 3, 3), 2);
								}
								break;
							case 4:
								// memory manage
								{
									print_line("memory protection fault:", mkcolor(3, 0, 0), 1);
									if (SCB->CFSR & SCB_CFSR_IACCVIOL_Msk) print_line("during inst fetch", mkcolor(1, 1, 1), 2);
									else if (SCB->CFSR & SCB_CFSR_DACCVIOL_Msk) print_line("during data fetch", mkcolor(1, 1, 1), 2);
									else if (SCB->CFSR & SCB_CFSR_MSTKERR_Msk) print_line("during exception stacking", mkcolor(1, 1, 1), 2);
									else if (SCB->CFSR & SCB_CFSR_MUNSTKERR_Msk) print_line("during exception unstacking", mkcolor(1, 1, 1), 2);

									if (SCB->CFSR & SCB_CFSR_MMARVALID_Msk) {
										char buf[32];
										snprintf(buf, 32, "while accessing 0x%08x", SCB->MMFAR);
										print_line(buf, mkcolor(1, 1, 3), 2);
									}
								}
								break;
							default:
								// other interrupt
								{
									char buf[32];
									snprintf(buf, 32, "from ISR %d", active_isr);
									print_line(buf, mkcolor(3, 0, 0), 1);
								}
								break;
						}
					}

					{
						// Try to check the active thread
						if (rtos::is_rtos_running()) {
							const char* tname = rtos::guess_active_thread_name();
							if (!tname) {
								print_line("corrupted RTOS state", mkcolor(3, 0, 0), 1);
							}
							else {
								char buf[32];
								snprintf(buf, 32, "from thread %s", tname);
								print_line(buf, mkcolor(0, 3, 0), 1);

							}
							// Try to dump other tasks
							y = 65;
							uint32_t tSP, tPC, tLR;
							rtos::get_task_regs(*reinterpret_cast<uint32_t **>(&tskmem::srvc), tPC, tSP, tLR);
							show_backtrace_for("Traceback for servicer", tSP, tPC, tLR);
							rtos::get_task_regs(*reinterpret_cast<uint32_t **>(&tskmem::screen), tPC, tSP, tLR);
							show_backtrace_for("Traceback for screen", tSP, tPC, tLR);
							rtos::get_task_regs(*reinterpret_cast<uint32_t **>(&tskmem::dbgtim), tPC, tSP, tLR);
							show_backtrace_for("Traceback for dbgtim", tSP, tPC, tLR);
						}
					}
					{
						// Try to show servicer stats
						if (auto * srvp = srvd::ServicerDebugAccessor::get_debug_servicer_pending_requests()) {
							print_line("srv pending requests:", mkcolor(3, 3, 3), 1);
							if (!rtos::for_all_in_queue<srv::Servicer::PendRequest>(srvp, [](const srv::Servicer::PendRequest& pr){
								switch (pr.type) {
									using enum srv::Servicer::PendRequest::PendRequestType;

									case TypeNone: print_line("None", mkcolor(3, 1, 1), 2); break;
									case TypeChangeTemp: print_line("ChangeTemp", mkcolor(2, 2, 3), 2); break;
									case TypeChangeTempMulti: print_line("ChangeTempMulti", mkcolor(2, 2, 3), 2); break;
									case TypeRxTime: print_line("RxTime", mkcolor(2, 3, 2), 2); break;
									case TypeDumpLogOut: print_line("DumpLogOut", mkcolor(2, 3, 2), 2); break;
									case TypeRefreshGrabber: print_line("RefreshGrabber", mkcolor(1, 1, 3), 2); break;
									case TypeSleepMode: print_line("SleepMode", mkcolor(1, 3, 1), 2); break;
									case TypeReset: print_line("Reset", mkcolor(3, 0, 0), 2); break;
									case TypeSync: print_line("Sync", mkcolor(1, 1, 1), 2); break;
									default: print_line("<invalid>", mkcolor(3, 1, 1), 2); break;
								}
							})) print_line("<struct invalid>", mkcolor(3, 0, 0), 2);
							if (srvd::ServicerDebugAccessor::get_debug_servicer_did_ping()) {
								print_line("srv ping waiting", mkcolor(3, 1, 1), 1);
							}
						}
					}


					// Reset printer
					delay_ms(page_delay);
					draw::rect(matrix, 0, 12, 128, 64, 0);
					y = 18;
				}
			}
		}
reboot:
		for (int tim = 8; tim >= 0; --tim) {
			draw::rect(matrix, 0, 12, 128, 64, 0);
			draw::text(matrix, "rebooting:", 0, 18, 0xff);
			draw::rect(matrix, 0, 20, tim*16, 26, mkcolor(1, 2, 3));
			delay_ms(1000, false);
		}

		NVIC_SystemReset();
		while (1) {;}
	}

	// Transfer control to the crash handler.
	//
	// `errcode` must either be null or point to memory outside of the crash handler's region (i.e.
	// outside VRAM)
	//
	// This function does not return.
	[[noreturn]] void call_crash_main(const char *errcode, uint32_t SP, uint32_t PC, uint32_t LR) {
		// Set the stack pointer to the end of the crash handler's stack
		// 
		// Since we're running from either an interrupt handler or a task, we don't set the MSP, rather
		// we just set the current stack pointer and use that.

		asm volatile (
				"mov sp, %0\n\t"
				: 
				: "r" (&_ecstack)
				: "memory"
				);

		// Now we just jump directly to the crash main
		asm volatile (
				"ldr r12, =%0\n\t"
				"bx r12\n\t"
				:
				: "i" (&cmain)
				: "memory"
				);
	}

	[[noreturn]] void panic_nonfatal(const char* errcode) {
		call_crash_main(errcode, 0, 0xffff'ffff, 0);
	}

	[[noreturn]] void panic_from_isr(const char *errcode, uint32_t *SP_at_isr) {
		uint32_t PC = SP_at_isr[6];
		uint32_t LR = SP_at_isr[5];
		bool aligned = SP_at_isr[7] & (1 << 9);
		uint32_t SP = (uint32_t)(&SP_at_isr[8]) + aligned * 4;
		call_crash_main(errcode, SP, PC, LR);
	}

}

extern "C" void msign_panic(const char *msg) {
	crash::panic(msg);
}

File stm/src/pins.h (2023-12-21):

#ifndef PINS_H
#define PINS_H

// Define a bunch of names depending on the active build target

#ifdef STM32F207xx

#define ESP_USART USART6
#define ESP_USART_Port GPIOG
#define ESP_USART_TX LL_GPIO_PIN_14
#define ESP_USART_RX LL_GPIO_PIN_9

#define ESP_USART_IRQ_NAME USART6_IRQn
#define ESP_USART_IRQ_HANDLER USART6_IRQHandler

#define SIGN_DATA_Port GPIOD
#define SIGN_GPIO_PERIPH LL_AHB1_GRP1_PERIPH_GPIOD

#define UART_DMA DMA2
#define UART_DMA_TX_Stream LL_DMA_STREAM_7
#define UART_DMA_RX_Stream LL_DMA_STREAM_1
#define UART_DMA_Channel LL_DMA_CHANNEL_5

#define UART_DMA_PERIPH LL_AHB1_GRP1_PERIPH_DMA2
#define UART_GPIO_PERIPH LL_AHB1_GRP1_PERIPH_GPIOG
#define UART_UART_PERIPH LL_APB2_GRP1_PERIPH_USART6
#define UART_ENABLE_CALL LL_APB2_GRP1_EnableClock
#define UART_Af LL_GPIO_AF_8

#define NVIC_SRV_RX_IRQ_NAME DMA2_Stream1_IRQn
#define NVIC_SRV_TX_IRQ_NAME DMA2_Stream7_IRQn

#define NVIC_SRV_RX_IRQ_HANDLER DMA2_Stream1_IRQHandler
#define NVIC_SRV_TX_IRQ_HANDLER DMA2_Stream7_IRQHandler

#define NVIC_SRV_RX_ACTV LL_DMA_IsActiveFlag_TC1
#define NVIC_SRV_RXE_ACTV LL_DMA_IsActiveFlag_TE1
#define NVIC_SRV_TX_ACTV LL_DMA_IsActiveFlag_TC7

#define NVIC_SRV_RX_CLRF LL_DMA_ClearFlag_TC1
#define NVIC_SRV_RXE_CLRF LL_DMA_ClearFlag_TE1
#define NVIC_SRV_TX_CLRF LL_DMA_ClearFlag_TC7

#define UI_BUTTON_PORT GPIOA
#define UI_BUTTON_PERIPH LL_AHB1_GRP1_PERIPH_GPIOA

#endif

#if defined(STM32F205xx) || defined(STM32F405xx)

#define ESP_USART USART2
#define ESP_USART_Port GPIOA
#define ESP_USART_TX LL_GPIO_PIN_2
#define ESP_USART_RX LL_GPIO_PIN_3

#define ESP_USART_IRQ_NAME USART2_IRQn
#define ESP_USART_IRQ_HANDLER USART2_IRQHandler

#define SIGN_DATA_Port GPIOC
#define SIGN_GPIO_PERIPH LL_AHB1_GRP1_PERIPH_GPIOC

#define UART_DMA DMA1
#define UART_DMA_TX_Stream LL_DMA_STREAM_6
#define UART_DMA_RX_Stream LL_DMA_STREAM_5
#define UART_DMA_Channel LL_DMA_CHANNEL_4

#define UART_DMA_PERIPH LL_AHB1_GRP1_PERIPH_DMA1
#define UART_GPIO_PERIPH LL_AHB1_GRP1_PERIPH_GPIOA
#define UART_UART_PERIPH LL_APB1_GRP1_PERIPH_USART2
#define UART_ENABLE_CALL LL_APB1_GRP1_EnableClock
#define UART_Af LL_GPIO_AF_7

#define NVIC_SRV_RX_IRQ_NAME DMA1_Stream5_IRQn
#define NVIC_SRV_TX_IRQ_NAME DMA1_Stream6_IRQn

#define NVIC_SRV_RX_IRQ_HANDLER DMA1_Stream5_IRQHandler
#define NVIC_SRV_TX_IRQ_HANDLER DMA1_Stream6_IRQHandler

#define NVIC_SRV_RX_ACTV LL_DMA_IsActiveFlag_TC5
#define NVIC_SRV_RXE_ACTV LL_DMA_IsActiveFlag_TE5
#define NVIC_SRV_TX_ACTV LL_DMA_IsActiveFlag_TC6

#define NVIC_SRV_RX_CLRF LL_DMA_ClearFlag_TC5
#define NVIC_SRV_RXE_CLRF LL_DMA_ClearFlag_TE5
#define NVIC_SRV_TX_CLRF LL_DMA_ClearFlag_TC6

#define UI_BUTTON_PORT GPIOA
#define UI_BUTTON_PERIPH LL_AHB1_GRP1_PERIPH_GPIOA

#endif

#endif

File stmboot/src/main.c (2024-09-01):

#ifdef USE_F2
#include <stm32f2xx.h>
#endif
#ifdef USE_F4
#include <stm32f4xx.h>
#endif
#include "common/bootcmd.h"
#include <stdbool.h>
#include "memset.h"

// BOOTLOADER REVISION CONSTANT
const char BL_REV[4] = {'2', 'c', 0, 0};

extern const void * _sirtext;
extern void * _srtext, *_ertext;
#define RAMFUNC __attribute__((section(".rtext")))

#define FLASH_KEY1 0x45670123U
#define FLASH_KEY2 0xCDEF89ABU

#ifdef STM32F205xx
// board
#define LED_DATA_PORT GPIOC
#define LED_DATA_BLOCK RCC_AHB1ENR_GPIOCEN
#else
// nucleo
#define LED_DATA_PORT GPIOD
#define LED_DATA_BLOCK RCC_AHB1ENR_GPIODEN
#endif

// BASIC SCREEN DRIVER
//
// Only controls one row of monochrome pixels
void init_scrn() {
	RCC->AHB1ENR |= RCC_AHB1ENR_GPIOBEN | LED_DATA_BLOCK;
	asm volatile ("nop");
	asm volatile ("nop");
	asm volatile ("nop");

	GPIOB->MODER = (
		GPIO_MODER_MODE5_0 |
		GPIO_MODER_MODE6_0 |
		GPIO_MODER_MODE0_0 |
		GPIO_MODER_MODE1_0 |
		GPIO_MODER_MODE2_0 |
		GPIO_MODER_MODE3_0
	);

	LED_DATA_PORT->MODER = (
		GPIO_MODER_MODE6_0 |
		GPIO_MODER_MODE0_0 |
		GPIO_MODER_MODE1_0 |
		GPIO_MODER_MODE2_0 |
		GPIO_MODER_MODE3_0 |
		GPIO_MODER_MODE4_0 |
		GPIO_MODER_MODE5_0 
	);

	GPIOB->PUPDR = 0;
	GPIOB->ODR = (1 << 6);
	LED_DATA_PORT->ODR = 0;
}

void show_line(bool data[64]) {
#include "showline.inc"
}

RAMFUNC void show_line_ram(bool data[64]) {
#include "showline.inc"
}

void jump_to_program() {
	SysTick->CTRL = 0;
	SysTick->LOAD = 0;
	SysTick->VAL = 0;

	SCB->VTOR = 0x4000;

	__set_MSP(*(uint32_t *)(0x08004000));
	((void(*)(void))(*(uint32_t *)(0x08004004)))();
}

RAMFUNC void do_update_app() {
	uint8_t sector_count = 0;
	bool sp[64] = {1, 0, 0, 0}; // 1, 0, 0, 0 - status UPDATE
	memset(sp + 4, 0, 60);

	// Erase sectors
	uint32_t size = bootcmd_update_size();
	if (size > 0) {sector_count++; sp[4] = 1;}
	if (size > 16384) {sector_count++; sp[5] = 1;}
	if (size > 32768) {sector_count++; sp[6] = 1;}
	if (size > 49152) {sector_count++; sp[7] = 1;}
	if (size > 114688) {sector_count++; sp[8] = 1;}
	if (size > 245760) {sector_count++; sp[9] = 1;}
	if (size > 376832) {sector_count++; sp[10] = 1;}

	sp[12] = 0;
	sp[13] = 1;
	sp[14] = 1;
	sp[15] = 0; // status code 0, 1, 1, 0, leds indicate erase count
	show_line_ram(sp);

	// set PSIZE
	CLEAR_BIT(FLASH->CR, FLASH_CR_PSIZE);
	FLASH->CR |= 2 << FLASH_CR_PSIZE_Pos;

	sp[13] = 0; // status code 0, 0, 1, 0, leds indicate erase remaining
	
	for (uint8_t i = 0; i < sector_count; ++i) {
		CLEAR_BIT(FLASH->CR, FLASH_CR_SNB);
		FLASH->CR |= FLASH_CR_SER /* section erase */ | ((1 + i) << FLASH_CR_SNB_Pos);
		FLASH->CR |= FLASH_CR_STRT;

		while (READ_BIT(FLASH->SR, FLASH_SR_BSY)) {}

		sp[i+4] = 0;
		show_line_ram(sp); 
	}
	CLEAR_BIT(FLASH->CR, FLASH_CR_SER);

	// Sectors erased, program flash
	memset(sp, 0, 64);

	sp[0] = 1;

	if (size % 4 != 0) {
		size += (4 - (size % 4)); // round to next 4
	}

	int sp_pos = 2;
	int counter = 0;
	
	for (uint32_t i = 0; i < size; i += 4) {
		counter += 4;
		FLASH->CR |= FLASH_CR_PG;
		*(uint32_t *)(0x08004000 + i) = *(uint32_t *)(0x08080000 + i);

		while (READ_BIT(FLASH->SR, FLASH_SR_BSY)) {}

		if (counter > (size / 64)) {
			counter = 0;
			sp_pos += 1;
			if (sp_pos == 64) {
				memset(sp + 2, 0, 62);
				sp_pos = 2;
			}
			sp[sp_pos] = 1;
			show_line_ram(sp);
		}
	}

	FLASH->CR |= FLASH_CR_LOCK;

	memset(sp + 1, 0, 63);

	sp[4] = 1;
	sp[5] = 0;
	sp[6] = 1;
	sp[7] = 1; // status 1 0 1 1  - comparing

	if (memcmp((const void *)(0x08004000), (const void *)(0x08080000), bootcmd_update_size()) != 0) {
		sp[0] = 1;
		sp[3] = 1;
		sp[4] = 1;
		sp[5] = 1;
		sp[6] = 1;
		sp[7] = 1; // ERROR - compare fail
		show_line_ram(sp);
		for (int i = 0; i < 30000; ++i) {
			asm volatile ("nop");
		}
		// UHOH
		NVIC_SystemReset(); // retry
	}

	// verify is ok, we can now erase the update partition and mark everything as hunkidory.
	// this also means that a program can check a 
	
	bootcmd_service_update();

	// the system is now updated, reset
	NVIC_SystemReset();
}

RAMFUNC void do_update_bootloader() {
	bool sp[64] = {1, 1, 0, 0}; // 1, 0, 0, 0 - status RELOAD
	memset(sp + 4, 0, 60);

	show_line_ram(sp);

	if (bootcmd_update_size() > 16384) {
		sp[1] = 0;
		sp[3] = 1;
		sp[4] = 1;
		sp[5] = 1;
		sp[6] = 0;
		sp[7] = 0; // 1 1 0 0 - error in size of bootloader
		show_line_ram(sp);
		for (int i = 0; i < 30000; ++i) {
			asm volatile ("nop");
		}
		// UHOH
		NVIC_SystemReset(); // retry
	}

	volatile uint32_t update_size = bootcmd_update_size();

	// bootloader update loop
	// erase original bootloader
	//
	// NO FLASH FUNCTIONS CAN COME AFTER THIS
	
	CLEAR_BIT(FLASH->CR, FLASH_CR_PSIZE);
	FLASH->CR |= 2 << FLASH_CR_PSIZE_Pos;

	sp[4] = 1;
	sp[5] = 1; // 1, 1, 0, 0 - erasing sector
	show_line_ram(sp);
	
	CLEAR_BIT(FLASH->CR, FLASH_CR_SNB);
	FLASH->CR |= FLASH_CR_SER /* section erase + 0 sector */;
	FLASH->CR |= FLASH_CR_STRT; // WE are now gone

	while (READ_BIT(FLASH->SR, FLASH_SR_BSY)) {}
	CLEAR_BIT(FLASH->CR, FLASH_CR_SER);
	sp[5] = 0;
	sp[6] = 1;
	show_line_ram(sp); // erase OK, copying

	for (uint32_t ptr = 0x08000000, src = 0x08080000; ptr < (0x08000000 + update_size); ptr += 4, src += 4) {
		FLASH->CR |= FLASH_CR_PG;
		*((uint32_t *)ptr) = *((uint32_t *)src);
		while (FLASH->SR & FLASH_SR_BSY) {;}
	}

	sp[5] = 1;
	show_line_ram(sp); // 1, 1, 1 - OK
	FLASH->CR &= ~FLASH_CR_PG;

	// Set the BOOT MODE back to a normal value
	RTC->BKP0R = BOOTCMD_RUN;
	RTC->BKP1R = 0xd0d3;

	for (int i = 0; i < 30000; ++i) {asm volatile ("nop");}

	// Manually jump to the bootloader again
	
	__set_MSP(*(uint32_t *)(0x08000000));
	((void(*)(void))(*(uint32_t *)(0x08000004)))();

	// Did it return?
	sp[0] = 1;
	sp[1] = 0;
	sp[2] = 1;
	sp[3] = 0;
	sp[4] = 0;
	sp[5] = 0;
	sp[6] = 0;
	sp[7] = 0;
	sp[8] = 1; // ERROR 0, 0, 0, 0, 1 - new bootloader died
	show_line_ram(sp);

	while (1) {;}
}
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

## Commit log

2020-06-16 Fix various sim build issues
    [main.cpp]
2020-06-18 Fix update extraction of webui.ar
    PSTR in the right place damnit
    [upd.cpp]
2020-06-30 Prepare for new slot system by limiting slot ids to 12 bits
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2020-09-22 Begin porting ESP over; use new SDK and remove a whole bunch of stuff
    [partitions.csv]
2020-09-23 reselect card between commands in init
    fixes some sandisk cards
    [sd.cpp]
2020-09-23 rename some partitions
    [partitions.csv]
2020-09-23 fix static-ness of TAG on serial
    [serial.cpp]
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2020-09-25 Add recovery code for ESP8266 stuck requests
    [serial.cpp]
2020-09-26 Remove old CI tools
    they will be added when I can be bothered to rewrite them
    [upload_stm.cfg]
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2020-09-28 Add logging for failed task allocation
    [main.cpp, protocol.cpp]
2020-10-12 print better error for gai fail
2020-10-12 fix infinite stack overflow in update_blocks
    todo: check if this means we can reduce the stack overhead
    [serial.cpp]
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2020-10-14 Make slot() return a typedslot so the right bool() is called
    also makes using strs easier due to the overload
2020-10-14 Send blocks always whenever they change temperature
    in case the STM discarded them (TODO: add another meaning for DATA_DEL
    for this?)
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2020-10-15 Various fixes to srv/serial
    [serial.cpp]
2020-10-15 Fix ttc in 1 element case
2020-10-15 Minor fixes to evicting
    still very very broken -- i think the next tool in the caplog will be a
    bheap decoder
    [serial.cpp]
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2020-10-18 Make esp try to send packets after out of space twice
    note: this really needs a short delay to get the stm to actually
    try evicting stuff
    [serial.cpp]
2020-10-18 Suspendall if not in ISR
    fixes servicer case
2020-10-18 fix uart swap in sdkconfig
2020-10-19 Fix nucleo pin setup
    how tf was it _this_ wrong?
    [pins.h]
2020-10-19 Add error screen for invalid memory
    [main.cpp]
2020-10-23 Begin rewriting upd
    (finished update webui; stubbed cacerts)
    new design shouldn't reboot unnecessarily
    new cacerts should delete all certs in the old folder, then extract the
    given ar into a new folder. do it into a temp dir for good measure
    though
    [upd.cpp]
2020-10-23 Fix esp upd sending
    [upd.cpp]
2020-10-23 fix hang during start
    [protocol.cpp]
2020-11-02 Add the beginnings of a cool crash handler
    apparently i don't know how to drive the display though
    who knows
    i need more sleep
    [main.cpp]
2020-11-04 Various fixes to crash handler + matrix
    [main.cpp]
2020-11-04 Add pagination to crashh
    [main.cpp]
2020-11-04 Add more context to crash handler reports
    [main.cpp]
2020-11-04 Update code to use new crash handler
    [main.cpp]
2020-11-05 Fix sim build
    (add a bunch of stubs)
    [main.cpp, upd.cpp]
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2020-12-23 prevent infinite send subloop
    [serial.cpp]
2021-03-15 update board schematic pdf
    [contbrd.sch]
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2021-03-19 run desync fixer on both cases
    [protocol.cpp]
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2021-04-23 add proper stm rx error handling
    finally!
    [pins.h, protocol.cpp]
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2021-07-09 Various nonsense around trying to fix low mem
    [serial.cpp]
2021-07-10 fix esp protocol in sim
    [protocol.cpp]
2021-07-10 init dupm after connecting to stm to avoid race condition
    [serial.cpp]
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2021-07-15 Fix handling of 0-size packet RX in esp
    [protocol.cpp, serial.cpp]
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2021-07-20 Always align to 4-bytes in json allocator
    the Xtensa™ is fairly picky about alignment
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2021-07-20 Fix suprious fail message in webui update
    [upd.cpp]
2021-07-21 Show all tasks in crash handler
    [main.cpp]
2021-07-21 Add laser dxf
    did I do it right?
    [msign-laser.dxf]
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2021-07-27 change laser file to svg
    [msign-laser.dxf]
2021-07-27 fix warnings in sd
    [sd.cpp]
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2021-08-15 Fix graph y-axis on !0 y0
2021-08-20 Attempt to use hardware timer pulse generation for better color stability
    Currently, OE pulses are generated purely in software with a timer
    update interrupt. This is susceptible to considerable jitter especially
    since the interrupt must be below the system RTOS priority to allow it
    to signal the display task when to swap buffers. This technique
    still uses update interrupts, but drives the OE pin from a timer compare
    channel, which should have much less imprecision.
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2021-08-23 Fix logs breaking sim comms
    [main.cpp]
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2021-09-05 Add option to override wifi country settings
    might work around a bug in the sdk
    [main.cpp]
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2021-09-06 Homogenize on data new size
    hopefully will result in less "oops the data is corrupted for a frame"
    problems.
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2021-09-08 Filter ui on actual buttons to fix .changed()
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2021-10-02 Try to rework grabber task to be stoppable and refreshable
    with less jank
    [main.cpp]
2021-10-04 Fix screen task name
    [main.cpp]
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2021-10-05 Preserve temperature across truncations
    and fix a few bugs that said change would cause in dupm if memory
    ran out.
2021-10-18 Fix missing case statement in timekeeper
2021-10-30 Try and fix deadlock on esp for grab killer
    (at least I assume that's what it is)
    [main.cpp]
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2021-12-05 adjust error handling in protocol
    [protocol.cpp]
2021-12-05 Fix escape filtering in sdlog
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2022-05-08 Fix bheap free space calc for ephemeral blocks
    (technically should probably be a separate flag for NonDisposable or
    something since the flags check was for esp ephemeral awaiting-push
    blocks but in the current design those never exist so whatever)
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2022-05-14 Add basic UI support to the crash handler
    [main.cpp]
2022-05-19 Fix brackets
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2022-07-28 Support building for STM32F4 target as "board2"
    Runs at 168mhz instead of 120mhz too
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2022-08-08 Consolidate transit name loading
    May in future also handle altcode setup if that gets put into a
    different slot.
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2022-08-26 Make wifitime use nosync to avoid stalling event loop
    dhcp now comes up _before_ connecting to STM, which is nice
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2023-05-14 Add more crash debugging on servicer state
    [main.cpp]
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2023-07-15 Attempt to also fix the bootloader
    [main.c]
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2023-07-15 Fix stm32f4 ld script
2023-10-02 Fix documentation in serial::interface.current_slot_size
    [serial.cpp]
2023-10-15 Bump nmfu + cryptography requirements
    - solves a longstanding "security issue" on dependabot
    - lets us use -fuse-packed-enums
2023-10-16 Properly diagnose not found urls in http serve parser
    Turns out this wasn't an nmfu bug, just a wrongly specified parser: the
    match failure isn't in the case statement; it's in the space that comes
    after it which was not included in the try{}catch(nomatch){} block which
    would set the error code.
2023-10-27 Squelch dependabot
    ooh la la a security vulnerability in my js build system how terrifying
2023-12-21 Add new button board PCB + reorg board/
    [buttons.kicad_pcb, buttons.kicad_sch, contbrd.brd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]
2023-12-22 Update silkscreen
    [buttons.kicad_pcb]
2023-12-26 final buttonboard update and manuf files
    [buttons-B_Cu.gbl, buttons-B_Mask.gbs, buttons-B_Paste.gbp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]
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2023-12-26 Sync octoprint on 409 case because update_slot() was going the nocopy route
2023-12-27 Even more verbose sd card errors
    [sd.cpp]
2023-12-27 Even more robust sd error handling
    [sd.cpp]
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2023-12-27 Allow filtering prefixes/suffixes of gcode filenames
    also fixes the color picker
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2023-12-30 Add a mutex to ensure serial & dupm don't race setting up a packet filter
    Previously, dupm could try to do something like:
    send_pkt()
    // ... a few unimportant things ...
    wait_for_packet()
    and the response packet it's waiting for could arrive in between. This
    adds a hold_packets_until_wait which stops the serial task from dumping
    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
2023-12-30 Adjust dupm queue timeout to 0 for requests from serial
    This prevents a deadlock of the form:
    - dupm queue fills
    - dupm waits for packet
    - serial gets a DATA_TEMP message
    - serial waits for 5 seconds for empty space in dupm
    - dupm wait timeout expires
    - stm sends response for dupm packet
    - serial 5 second timeout expires
    - serial dumps out dupm wait response
    Since the dupm retries things, this usually repeats a few times as well,
    often cascading until no traffic can be exchanged.
    Really, there shouldn't be any reason to block for these requests: the
    STM retries both of the packets mentioned on its own.
    [serial.cpp]
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2023-12-31 Swap ADC pins with TAB/SEL buttons
    their original pins are not adc inputs. rev2 board will fix this if
    I ever manufacture it
2023-12-31 Return frame_time as a signed integer so multiplying by it works sensibly
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2024-01-01 Major overhaul of SD layer bit handling
    - Timeouts now actually work instead of failing way too quickly
    - Busy states are checked in more places
    - Nops removed for speed
    [sd.cpp]
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2024-01-06 Track exceptions through the crash handler
2024-01-06 Resolve all interrupt handlers in log to names
2024-01-06 Fix LTO ramfunc issues
    [main.cpp]
2024-01-07 Fix draw_graph_precip filtering at wrong location
2024-01-08 Avoid clearing weather slots when updating
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2024-03-18 Add ESP8266 panic/crashlog saving
    After a fatal error, we write the crashlog contents (or at least
    the backtrace; the other PANIC() messages aren't captured at the moment)
    into RAM, then on the next boot we write that message to the SD card.
    [main.cpp, serial.cpp]
2024-03-18 Halt STM if a crash log was just saved to SD card
    [main.cpp, protocol.cpp, serial.cpp]
2024-03-18 Properly report crashes to the STM
    [main.cpp, serial.cpp]
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2024-04-19 Minor bheap fixes
    - use more efficient codepath for make_space_after in certain cases
    - clarify control flow in split_block
2024-05-06 Print EXCVADDR in crashlog
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2024-07-03 Attempt to prevent config updating stomping over active data fetch
    [main.cpp]
2024-07-03 Fix buggy weather data fuse
    Still obviously not considering the actual hour offset but meh.
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2024-07-13 Remove libc dependency from stmboot
    Also doesn't link against libgcc, which is technically wrong but the
    bootloader is not meant to use any of the things libgcc fills anyways.
    [main.c]
2024-07-14 Remove stm dependency on newlib
    The entirety of the stm codebase right now only relied on:
    - mem{move,cpy,set}: trivial to reimplement (even without
    optimizations, just using -O3 on a naive implementation generates
    suitable unrolling)
    - strlen & strncpy: also trivial to implement
    - strftime & gmtime_r: replaced with c++ quasi-time.h implementation
    mintime.h (instead of struct tm, we have mint::tm with member
    functions to access the few non-integer formats of strftime)
    - snprintf: rewrote a minimal snprintf supporting:
    - %d,%u,%x (field width supported but not precision)
    - %s (field width and precision supported)
    - %c (field width supported)
    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
    [adc_calibration.cpp, main.cpp]
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2024-07-15 Avoid UB in sd
    [sd.cpp]
2024-07-15 Convince the esp SDK to build under GCC 13.2
    - does not address the many, _many_ format warnings, but otherwise
    fixes a couple of oopsies in it
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2024-07-24 Avoid dumping small blocks when they are current
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2024-09-01 Make main() return void
    This is technically more correct since the STM started building
    with -ffreestanding turned on
    [main.c, main.cpp]
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2024-10-01 Write pending log buffer to crashlogs
    (also, adjust sdlog to support log-while-write-to-sd)
    [serial.cpp]
2024-10-01 Fix case where HTTP adapter can get stuck with an open connection
    also, fix it trying to connect even when DNS lookup fails
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2024-11-10 Make weather graph space y-axis tickmarks better
    still not perfect, it doesn't (for example) try to smoosh stuff against
    the top of the screen if doing so benefits the spacing of the tickmarks
    instead of their labels
2024-11-10 Add fix for memory leak in sdk code
    When reconnecting to a WPA2-Enterprise network, the system can decide
    to cache on a reconnection attempt, in which case the EAP sm is not
    cleaned up and roughly 7k is leaked (well, it's referenced by a global
    so will not accumulate over multiple attempts, but still) as a result.
    This adds a few hacks to ensure the SDK code is told about key
    negotiation succeeding regardless - this is complicated by the fact that
    the WPA2 code in libnet80211.a (as decompiled) only checks that state
    and deinitializes from rx_eapol, i.e. after a packet is received (or
    from connection timeout), so if the state is never set to FINISHED
    during a packet reception, it never deini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
2024-11-26 Avoid showing 0mm of snow if no accumulation, show rate instead
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2025-01-14 Refactor bheap to use C++20 requires
    and also add tail() for fixed-header-dynamic-trailer-typed slots
2025-01-18 Add tailed block support to slotlib
    (bheap supports fixed-length header + dynamic trailer;
    only fixed types in slotlib atm)
2025-03-04 Optimize int64 -> fixed_t in octoprintbitmap
    - for decimal <= 4:
    - computes int() * (Fac / n) for integer part of *65536/*6553.6/...
    - uses bit shifts to emulate the binary fraction for .6, .36, .536,
    etc.
    - for decimal <= 11:
    - stores a table of powers of ten to do the 64-bit division only
    once (the *Fac is optimized away to a bitshift)
    - only otherwise does repeated division
    - might replace this with a cap in the parser on decimal precision,
    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
2025-04-29 Attempt to fix infinite loop in exc decode from interrupt
2025-04-29 Fix CI build due to newer xtensa gcc
    Pins ESP toolchian at gcc 13.2
    I do not feel like recreating the UNHOLY FUSION that is the
    newlib-libstdc++-xtensa-lx106-elf-13.2.0.tar.xz archive at the moment.
    (more importantly, it's based on the official ESP32 sources and they
    never released a 13.3 build).
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2025-11-09 Avoid "currently <precip>" summaries due to incorrect check
    (should_ignore_hourly_summary ignored the 24h fallback for fog
    ending/starting conditions)
2025-11-11 Add first chunk of rev2 PCB
    - power stage tentatively done
    - probably going to switch from sic951->sic451 with external
    inductor as it's far easier to get a hold of
    - still need to play with the eval boards for the sic951 which I
    have (i'd prefer to have the 451 but it's not in stock and i'm not
    paying for mouser shipping)
    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
    [5vreg.kicad_sch, 5vswitch.kicad_sch, esp32.kicad_sch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]
2025-11-11 remove sic951 --> start doing sic451
    [5vreg.kicad_sch]
2025-11-11 Finish most of power section of rev2 PCB
    [5vreg.kicad_sch, 5vswitch.kicad_sch, matrixandbuffer.kicad_sch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]
2025-11-11 More board work
    [5vreg.kicad_sch, matrixandbuffer.kicad_sch, power.kicad_sch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]
2025-11-11 More board stuff
    (better clk routing, etc.)
    [5vreg.kicad_sch, 5vswitch.kicad_sch, decoder.kicad_sch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]
2025-11-11 Upgrade to kicad 9
    wow this has taken so long a new version of kicad came out that's kind
    of sad
    [5vreg.kicad_sch, 5vswitch.kicad_sch, decoder.kicad_sch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]
2025-11-11 Continue board work
    - move to rp2040, separate stm32g071 to do usb-c + aux ctrl IO
    - still cheaper lol with the cost of stm32s
    - more power reg stuff
    [5vreg.kicad_sch, decoder.kicad_sch, mainboard.kicad_sch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]
2025-11-12 Split out board into A/B
    allow 2x displays (for chaining)
    [decoder.kicad_sch, decoderout.kicad_sch, mainboard.kicad_sch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]
2025-12-08 Board GPIO allocation
    - and usbmux
    still need to do termination on the big buses + a bunch of bypass caps
    [5vreg.kicad_sch, 5vswitch.kicad_sch, decoder.kicad_sch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]
2025-12-14 Continue board, assign caps/res, adjust for JLC availability
    [5vreg.kicad_sch, 5vswitch.kicad_sch, decoder.kicad_sch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]
2025-12-14 Start new PCB
    - all footprints setup
    - need to setup netclasses next, tho
    [5vreg.kicad_sch, 5vswitch.kicad_sch, decoder.kicad_sch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]
2025-12-15 Add netclasses, more footprints, fix ERC
    [5vswitch.kicad_sch, esp32.kicad_sch, mainboard.kicad_sch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]
2025-12-15 Really finish rev2 board schematic
    - fix some more footprints
    - move to real SD card holder, for example
    - repair part numbers
    - add LCSC part refs to everything
    - add even more caps to the 3.3V reg output
    - really should use an LDO but meh it should be fine
    total BOM cost for 5 of them is apparently 160 CAD, or like 32 dollars
    each (don't think that includes the feeder fees tho)
    [5vreg.kicad_sch, 5vswitch.kicad_sch, decoder.kicad_sch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]
2025-12-16 Start board
    add a few extra bypass caps too, and swap some pins on the USB mux
    i forgot to add a bypass cap on the tpd6s so that also needs to happen
    truly 63 capacitors is not enough
    [5vreg.kicad_sch, 5vswitch.kicad_sch, decoder.kicad_sch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]
2025-12-23 More tweaks to schematic, start laying out regulators
    [5vreg.kicad_sch, 5vswitch.kicad_sch, decoderout.kicad_sch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]
2025-12-28 3.3V LDO
    [decoder.kicad_sch, mainboard.kicad_pcb, power.kicad_sch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]
2025-12-28 Layout more component blocks
    - regulators
    - mcus
    Still need to do the decoders + overall packing
    [mainboard.kicad_pcb, rp2040.kicad_sch]
2025-12-29 Rough full board layout
    also, start re-organizing which pins of buffers/gates are used for what
    still need to reorder the mem i/o lines to align better
    also fix duplicate pullups and fix mem_io isolation res
    [decoder.kicad_sch, decoderout.kicad_sch, mainboard.kicad_pcb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]
2026-01-02 Start routing rev2 board
    - got component placement mostly done, board outline set
    - did the power planes for the regulators, still need to do thermal
    relief stuff and setup the board-global power planes
    - then the big thing is the high freq stuff, then its just connect the
    dots hopefully
    [mainboard.kicad_pcb]
2026-01-13 Force disable wifi powersave on esp8266
    might be stuck on in flash config? could explain the lack of arps...
2026-01-13 Route some more of the board: usb protection / mux
    and some of the power mcu
    [mainboard.kicad_pcb, power.kicad_sch]
2026-02-24 Reorganize board, compress stuff closer to each other
    [mainboard.kicad_pcb]
2026-04-14 Finish board rev2
    woo another pcb
    [5vreg.kicad_sch, 5vswitch.kicad_sch, bom.csv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]
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2026-11-03 Fix http only downloads
    (in the very rare case lwip_recv decides not to do the right thing lol)
2026-11-06 Initialize 3d camera_pos / target correctly
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

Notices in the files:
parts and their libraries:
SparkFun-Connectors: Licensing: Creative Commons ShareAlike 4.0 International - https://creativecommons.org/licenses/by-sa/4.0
